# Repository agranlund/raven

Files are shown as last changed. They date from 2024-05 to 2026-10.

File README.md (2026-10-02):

# Raven
### A homemade Atari clone computer based on Motorola 68060
This computer is primarily designed to be an Atari clone computer with
the goal of being able to natively run clean GEM/TOS applications, and backward compatibility with old ST games by help of software emulation.

Latest release package: https://github.com/agranlund/raven/releases/tag/Raven.A1.latest

Other resources:
- Youtube: https://www.youtube.com/@granlund23/videos
- Forum: https://www.exxosforum.co.uk/forum/viewforum.php?f=119

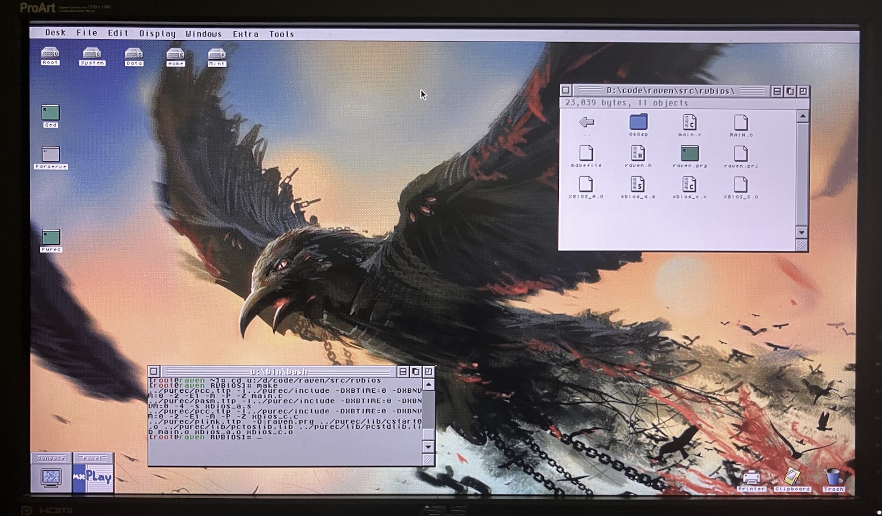
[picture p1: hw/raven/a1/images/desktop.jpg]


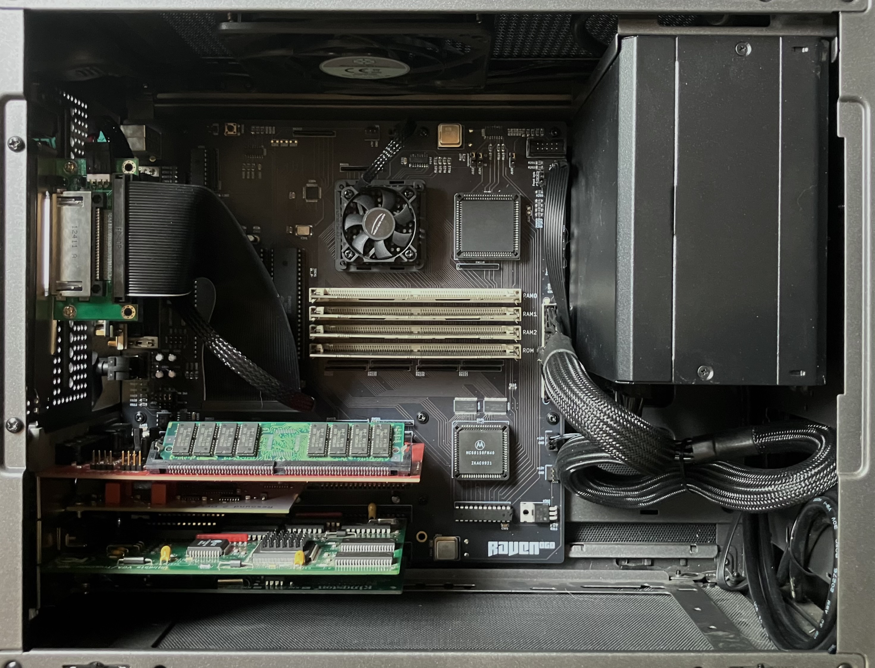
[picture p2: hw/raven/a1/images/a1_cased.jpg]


## This is not a consumer product.
I have no formal EE training or education and learn as I go.

This computer is primarily designed as a one-off for myself. For fun and learning and as a platform for low-level tinkering. 

All hardware and software sources are provided as-is and for free but comes with no guarantees or promise of support.

The computer works for me and runs EmuTOS, FreeMiNT and MagiC but if you decide to build or buy this board I very much recommend coming in with a DIY mindset.
Knowledge and tools to perform hardware-level debugging and/or very low level software debugging is highly recommended.

## Specifications Rev.A2
- Motorola 68060 CPU @ 96Mhz
- Motorola 56303 DSP @ 90Mhz
- Max 48MB RAM
- Max 16MB ROM
- USB Mouse & Keyboard
- 1Mbps serial port
- Legacy Atari serial port
- Legacy Atari parallel port
- Legacy Atari joystick ports
- IDE Harddisk interface
- Realtime clock
- Midi In/Out
- YM2149 sound
- MC68901 mfp
- ISA 16bit expansion slots x4

## Manual
- [Revision.A1](doc/manual_a1.pdf)

## Required or recommended parts
- Raven motherboard
	- [Revision.A2](hw/raven/a2/)
    - [Revision.A1](hw/raven/a1/)
    	- [USB upgrade](hw/raven/a1/upgrades/ckbd/)
    - ~~[Revision.A0](hw/raven/a0/)~~
- RAM modules
    - [16MB 55ns](hw/simm/ram_16M55/)
    - ~~[8MB 10ns](hw/simm/ram_8M10/)~~
- ROM module
    - [55ns SMD](hw/simm/rom_SMD/)
    - [55ns PLCC](hw/simm/rom_PLCC/)
- ATX power supply
- USB keyboard and mouse (PS/2 for Rev.A1 without USB upgrade)
- Some kind of suitable 44pin IDE->CF adapter
- RS232<->USB cable capable of 1Mbps
- ISA graphics card.
    - SVGA with hardware acceleration
        - Cirrus GD5434, GD5429, GD5428, GD5426
        - WDC WD90C33, WD90C31
        - Tseng ET4000/W32i
        - ATI Mach32
    - SVGA without hardware acceleration
        - Tseng ET4000AX
        - (untested) Cirrus GD5424, GD5422
        - (untested) WD90C30
    - Cards not listed above may work but only in standard VGA resolutions.
- ISA Network card.
	- RTL8019AS based card
- ISA soundcard
	- SoundBlaster compatible
	- Gravis Ultrasound

## Additional tools
- [ROM module programmer](hw/simm/programmer/)
- Programmer for ATF1508AS, for example ATDH1150-USB
- Programmer for ATF22V10C, for example XGecu TL866II-Plus
- (Rev.A1) Programmer for PIC16F876A, for example XGecu TL866II-Plus

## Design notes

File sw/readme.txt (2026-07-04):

## Subtrees:
sw/rom/emutos           : https://github.com/emutos/emutos master
sw/isa/drivers/picogus  : https://github.com/polpo/picogus main
sw/dsp/asm56k           : https://github.com/agranlund/asm56k master

## Compilers:
rom/mon                     : m68k-atari-mintelf-gcc
rom/srec                    : m68k-atari-mintelf-gcc
rom/emutos                  : m68k-atari-mintelf-gcc

rvbios                      : pureC
rvnova                      : pureC
rvsnd                       : pureC
tools/cache                 : pureC
tools/eiffel                : pureC
tools/flash                 : pureC
tools/fpu_emu               : m68k-atari-mintelf-gcc
tools/fpu_off               : pureC
tools/mon                   : pureC
tools/patch_xc              : pureC
tools/raven.cpx             : pureC
tools/resetnvm              : pureC
tools/serial.cpx            : pureC
tools/thingpal              : pureC
tools/uiptools              : m68k-atari-mintelf-gcc

isa/isa_bios                : pureC
isa/drivers/fmradio         : pureC
isa/drivers/gus             : pureC
isa/drivers/mpu401          : pureC
isa/drivers/oplmidi         : pureC
isa/drivers/ne2000/ethernec : turboC (1)
isa/drivers/picogus         : m68k-atari-mintelf-gcc

(1) using existing binaries, not compiling from source.
    to be replaced by own driver at some point.

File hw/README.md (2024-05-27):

All pcbs are made within JLCPCB tolerances and any Gerbers found here are exported for JLCPCB specifications.

Disclaimer: I am not an electrical engineer.
If anything in here seems stupidly designed, then it probably is.

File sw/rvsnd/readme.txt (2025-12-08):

# rvsnd
Sound HAL for Atari compatibles

Very early work in progress but can currently be used to initialize
cards, as well as control their mixers.
Midi in/out drivers are supported too.

Install:
- put rvsnd.prg in c:\auto
- put rvsnd.inf in root of c:\
- rvsnd.inf contains settings which can be edited with a text editor of choice

Remove the old standalone drivers from your auto folder if you have them:
- mpu401.prg
- oplmidi.prg
- ultrinit.prg

You can use rvsctrl.prg on the commandline to view and change settings.
(They are not saved. for that you need to manually edit rvsnd.inf)

The gsxbmixer application should work with rvsnd:
https://assemsoft.atari.org/gsxb/index.html

todo: proper documentation...

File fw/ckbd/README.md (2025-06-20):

# CKBD
## Eiffel replacement for Raven
## This is a work in progress and may contain yet to be discovered incompatibilities

CKBD aims to be fairly compatible with Eiffel and allows the use of the following devices:
* USB Keyboard and mouse
* PS2 Keyboard and mouse
* Atari joystick(s)
* Atari mouse
* Amiga mouse

Raven.A2 has the necessary hardware already on the motherboard.

Older revisions can use an [upgrade board](../../hw/raven/upgrades/ckbd/) that plugs into the Eiffel port.
Two USB ports are then exposed on an internal header.

## Technical description

CKBD is based around the CH559 microcontroller from WCH.

Some parts of this sourcecode is based on HIDman by Rasteri (https://github.com/rasteri/HIDman)

which is turn was based on CH559sdccUSBHost by atc114 (https://github.com/atc1441/CH559sdccUSBHost)

# First time programming: Windows
- Install WCHISPTool tool: https://www.wch.cn/downloads/WCHISPTool_Setup_exe.html
- Connect CKBD to your computer using a USB cable connected to the USB0 port.
- Select "File -> Load UI Config" and pick "ckbd_wch.ini"
- Under the "Download File" section pick "ckbd_a1.bin" as Object File 1
- Press Download to program the firmware

# First time programming: MacOS/Linux
There are several tools for flashing CH559, including an official one from WCH.
I am using ch552tool from MarsTechHAN (https://github.com/MarsTechHAN/ch552tool)

Flashing with ch552tool:
- install ch552tool, libusb and pyusb
- Connect CKBD to your computer using a USB cable connected to the USB0 port.
- run "python3 ch55xtool.py -f ckbd_a1.bin -r"

Flashing with WCHISPTool_Cmd:
- Install WCHISPTool_Cmd
- Read the documentation (especially if you are on MacOS)
- Connect CKBD to your computer using a USB cable connected to the USB0 port.
- run "WCHISPTool_CMD -p \<deviceid\> -c ckbd_wch.ini -o program -f ckbd_a1.bin"
  (you did read the manual regarding finding your \<deviceid\>, right?)

## Firmware update
With the CBKD installed in Raven:
   - press the NMI button to enter the monitor
   - run "kbd flash"
   - send the ckbd firmware binary with your serial terminal
   - run "reset" to reset Raven

If the ckbd is bricked and won't respond to updating firmware the normal way then:
  - make sure Raven is powered off
  - disconnect all usb devices
  - jumper the two middle pins of CKBD header J104
  - power on Raven
  - perform the same steps as when you did the first time programming
  - power off Raven
  - remove jumper from J104 and your USB programming cable
  - reconnect your devices and power on Raven

# Compiling
Compiles with SDCC: https://sdcc.sourceforge.net/

If you are building and working on the firmware yourself you can use "make target=a1 flash" or "make target=a1 flash_wchispcmd" to flash using the bundled ch552tool or wchisptool.
When using wchisptool you'll need to modify the WCHISPDEV variable in the makefile.

Executing "kbd prog" from the Raven monitor will put the CH559 into bootloader mode so it can be programmed with these tools (ie; you don't need to jumper it to start in bootloader mode)

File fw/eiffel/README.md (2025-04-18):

Compiles with GPASM from GPUTILS: https://gputils.sourceforge.io/

## Eiffel firmware v1.10.2-raven_A1

Firmware for Raven rev.A1 boards, based on v1.10.1-Mq_fixedFire_noLcd

The version ending with _ansi defaults to US-ANSI keyboard layout, however the layout can be changed at any time using the Eiffelcf application.

## Eiffel firmware v1.10.1-Mq_fixedFire_noLcd

This is a modified firmware with joystick fix and disabled LCD.
See this thread for details:

http://www.atari.org.pl/forum/viewtopic.php?id=19470

Original Eiffel schematics, firmware and control software:

http://didier.mequignon.free.fr/eiffel-e.htm

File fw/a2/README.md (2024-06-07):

- Nessi
    - ATF1508AS  7ns : main bus logic
- Narnia
    - ATF22V10C 10ns : isa control signals
- Iksi
    - ATF22V10C 10ns : ym/mfp/ide control signals

Builds with WinCUPL Atmel version 5.30.4
https://www.microchip.com/en-us/products/fpgas-and-plds/spld-cplds/pld-design-resources

I am using the newer ATF1508 fitter v1918 extracted from the Atmel Prochip package.
It's probably going to work fine with the old version bundled with WinCUPL but I have not tested it.

ATF1508AS can be programmed in-place using ATMISP software and ATDH1150USB programming cable.
Both of the ATF22V10C chips needs to be programmed off-board in an external programmer.

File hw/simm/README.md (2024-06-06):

# Info:
- Simm modules should be manufactured with a thickness of 1.2 mm
- They are probably be a tiny bit too wide but do fit in the socket ok. Would be good to shave off a millimeter or so in a future update.
- Unless stated otherwise these hardware designs are licensed under CERN-OHL-P v2
    - See LICENSE.md or visit https://cern.ch/cern-ohl

### Sub projects:
- breakout
	- simple simm breakout module for debugging. untested.
- panel
	- template for merging two simms onto one board separated by mouse-bites
- programmer
	- Pico based programmer for ROM simm modules
- ram_16M55
	- 16MB 55ns RAM module
- ram_8M10
	- 8MB 10ns RAM module
- rom_16M55
	- module with SMD roms (recommended)
- rom_2M55
	- module for 4x socketed PLCC roms
- template
	- blank simm module template

### Pinout:

1. vcc     * 
2. a2
3. a3
4. a4
5. a5
6. a6
7. a7
8. a8
9. a9
10. gnd     *
11. d31
12. d30
13. d29
14. d28
15. d27
16. d26
17. d25
18. d24
19. gnd     *
20. d23
21. d22
22. d21
23. d20
24. d19
25. d18
26. d17
27. d16
28. gnd     *
29. d15
30. d14
31. d13
32. d12
33. d11
34. d10
35. d9
36. d8
37. gnd     *
38. d7
39. d6
40. d5
41. d4
42. d3
43. d2
44. d1
45. d0
46. gnd     *
47. a21
48. a20
49. a19
50. a18
51. a17
52. a16
53. gnd     *
54. a15
55. a14
56. a13
57. a12
58. a11
59. a10
60. a9
61. a8
62. gnd     *
63. b0
64. b1
65. b2
66. b3
67. nc      -
68. oe
69. we
70. nc      -
71. nc      -
72. vcc     *

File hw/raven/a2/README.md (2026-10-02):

# Raven060 Rev.A2

(c)2025-2026 Anders Granlund

This source describes Open Hardware and is licensed under the CERN-OHLW v2.

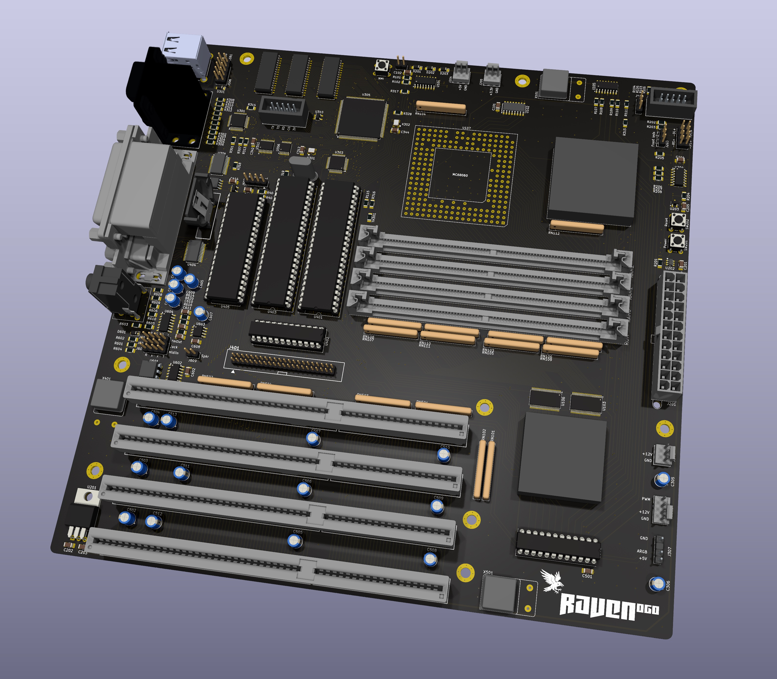
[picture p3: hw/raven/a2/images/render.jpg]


## Status:
- Built and running. Individual new features being tested.

## Info:
- Designed for JLCPCB standard six layer stackup (JLC06161H-3313)
- [Complete BOM](production/raven-a2_bom.md)
- [Interactive BOM](https://htmlpreview.github.io/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)
- [Interactive PCB](https://kicanvas.org/?repo=https%3A%2F%2Fgithub.com%2Fagranlund%2Fraven%2Ftree%2Fmain%2Fhw%2Fraven%2Fa2)

The following changes has been made to the files here on Github since after my personal board was manufactured.
- PWR_SW to UART:RI connection removed
- DC blocking capacitors to ADC left/right inputs added

## Changelog from Rev.A1
- Silkscreen: Fixed wrong pinout info for J305
- Silkscreen: Reversed order of RAM simms
- Silkscreen: Clearer orientation for a bunch of headers
- Silkscreen: Clearer pin1 markers for a bunch of SMD footprints
- Footprint:  Larger footprints for handsolder D201, D202, D203
- BOM: Replaced PLCC64 socket for U104 with black part
- BOM: Replaced PLCC84 socket for U108 with black part
- BOM: Replaced buttons SW101,SW201,SW202 with black parts
- BOM: Replaced jumpers with standard closed-top ones
- BOM: Replaced J401 IDE header
- Fixed: RTC power delivery, now using ATX standby power
- Fixed: unused but floating inputs on U102
- Fixed: polarity of YM2149 DC blocking caps
- Changed: through-hole DS1818 with DS1818R (SMD version)
- Changed: IDE interface is now big-endian
- Changed: CKBD instead of Eiffel
- Changed: 2xUSB instead of 2xPS2
- Changed: Replaced one 12V fan header with PWM + ARGB
- Removed: UART IRQ6 (MFP1:I4)
- Removed: CPU clock multiplier jumpers
- Added: small solderpad for securing Y402 to board
- Added: 68150:BUSCS signal separate from 68150:CS
- Added: A6 signal instead of A5 to ATF1508 (for BERR on SFP004 access)
- Added: pullups on 68150 data bus
- Added: pulldown on IDE:IRQ
- Added: i2c eprom with preprogrammed MAC address
- Added: i2c expansion header
- Added: CPU temperature readout from CKBD
- Added: PowerOff control from CKBD
- Added: YM2149 sw controlled volume
- Added: internal speaker amp + header
- Added: DSP56303 with DAC+ADC and ESSI1 expansion header

## Optional / non-critical:
- todo: describe building Rev.A2 without DSP?

## Untested:
- Midi-in

## Notes and Erratas:
- Part number for ARGB header isn't perfect, might want to use a variant with slightly longer pins.

## Future:
- Remove all components from Analog Devices as they can be hard to purchase for individuals?
  - MAX3245  : ICL3245ECAZ  (drop in replacement)
  - DS1307   : MCP79411     (software changes only, also makes U407+C415 redundant)
  - DS1818R  : MIC6315      (small schematic and board change needed)
  - MAX16054 : tbd          (small schematic and board change needed)

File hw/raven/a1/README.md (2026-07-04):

# Raven060 Rev.A1

(c)2024 Anders Granlund

This source describes Open Hardware and is licensed under the CERN-OHLW v2.



## Status:
Success: All major features has been tested and works in EmuTOS and FreeMiNT.

Tested with 48mhz oscillator for 96mhz CPU, 48mhz BUS speed.

## Info:
- Designed for JLCPCB Standard Service 6 layers
- [Complete BOM](production/raven-a1_bom.md)
- [Interactive BOM](https://htmlpreview.github.io/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)
- [Interactive PCB](https://kicanvas.org/?repo=https%3A%2F%2Fgithub.com%2Fagranlund%2Fraven%2Ftree%2Fmain%2Fhw%2Fraven%2Fa1)

## Errors to consider when building:
- C601-C604 capacitor orientation is wrong. Solder reverse of what silkscreen says.
- J305 silkscreen mislabeled; Pinout is same as J206 above.

## Changelog from Rev.A0:
- Changed locations of H607, H609
- Changed IDE ADR: A1:A3 -> A2:A4
- Changed I2C DTA: MFP1_I7 -> MFP1_I3
- Changed I2C CLK: MFP1_I3 -> MFP1_I7
- Added UART IRQ6 (MFP1:I4)
- Added Eiffel thermistor
- Added 3.3V fan header
- Added 5V fan header
- Added 12V fan header
- Added 12V fan header (Eiffel controlled)
- Added CPU speed switch J102, J104
- Added CPLD spare input switch J105
- Added CPLD spare output header J106
- Added CPLD input ISA:IOCS16
- Added expansion header J402 (4xYM outputs, 5V, gnd, i2c)
- Added pullup on CPU RW
- Added pullup on 68150 RW
- Combined CPLD excs/exbusen signals
- Disabled RS232 AutoShutdownPlus
- Removed debug testpoints and solderjumpers
- Removed second audio connector
    - YM-out / Midi-in share same lower connector on J601
    - Non selected is exposed on header J602:J604
- Misc silkscreen & bom fixes

## Errata / Notes for next revision:
- Silkscreen: J305 pinout mislabeled
- Silkscreen: U203 orientation is not obvious
- Silkscreen: J204-206,J305 orientation is not obvious
- Silkscreen: J301-304 orientation is not obvious
- Silkscreen: J103, J401 orientation is not obvious
- Footprints: D201-203 pads are small and hard to solder by hand
- Footprints: C601-603 hole spacing slightly too wide
- Footprints: C502-513 hole spacing slightly too wide
- Footprints: Y402 add a way to secure it (SMD pad at top to solder it in place)
- BOM: PLCC socket Preci-Dip 540-88-068-24-008 is brown, find black replacement
- BOM: PLCC socket Preci-Dip 540-88-084-24-008 is brown, find black replacement
- BOM: ATX connector TE 1-1775099-3 is white, find black replacement
- BOM: Buttons are red, find black replacement
- BOM: Jumpers TE 1-881545-4 are difficult to grab, pick a different variant
- PCB: Some kind of sign-of-life LEDs
- PCB: Combining excs/exbusen was a misstake. Separate signals could allow faster synchronous termination.
- PCB: A5 signal to CPLD is unused and the pin could potentially be freed up for something else
- PCB: SFP004 detection cannot neatly be prevented in software, route A6 to CPLD for hardware berr generation.
- PCB: Add hardware debounce the NMI switch
- PCB: Add header for one of MFP2 timer-outs (for pc-speaker type applications)
- PCB: Realtime clock should use +5VSB instead of +5V to reduce battery usage

## Untested:
- Midi In

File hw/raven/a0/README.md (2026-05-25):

# Raven060 Rev.A0

(c)2024 Anders Granlund

This source describes Open Hardware and is licensed under the CERN-OHLW v2.

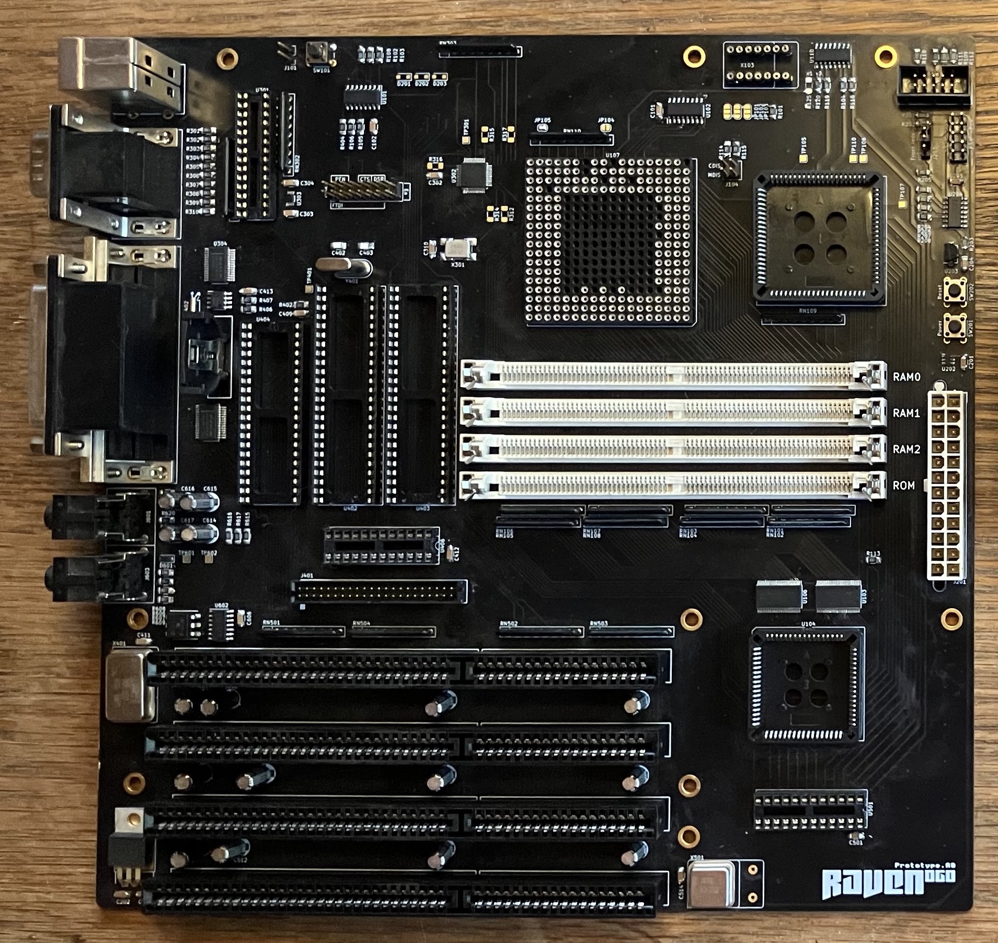
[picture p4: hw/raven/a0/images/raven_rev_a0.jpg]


## Status:
Success: All major features has been tested and works in EmuTOS and FreeMiNT.

Computer runs stable at 96mhz CPU / 48mhz BUS speed.

This is the very first "throw away" prototype and I do not recommend building it.
No efforts will be made to ensure software or firmware developments maintain compatibility with this version.

Revision.A1 should be considered the corrected version of this board.

## Info:
- Designed for JLCPCB Standard Service 6 layers
- [Interactive BOM](https://htmlpreview.github.io/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)

## Notes:

#### Untested features:
- Midi in

#### Errors:
- Layout:
	- H607 wrong location
	- H609 wrong location
    - Back connectors too close to lower edge
- Silkscreen:
	- C512 upside down
- BOM:
	- Exclude DNP parts
	- Missing the jumpers

#### Must fix:
- CPU:
	- pullup on RW
	- remove debug solder jumpers
    - remove debug option header
- 68150:
	- pullup on RW
- RS232:
	- U304 : disable AutoShutDownPlus
	- U401 : disable AutoShutDownPlus
	- remove internal FTDI header
- Eiffel:
	- IRQ6 instead of 5 (or both)
	- Hook up Therm and fan controls
- IDE:
	- use A2:4 instead of A1:3 like Atari/Amiga
- YM:
	- Add internal Line-out header
- ISA:
	- route IOCS16 to cpld

#### Nice to have:
- Fan header(s)
- Combine exbusen & excs
- CPU x1/x2 selectable by jumper
- Spare CPLD in/out on header
- pin info on back silkscreen (ym/mfp)

#### Maybe:
- PC speaker header on a spare MFP2 TBO/TCO
- Indicator leds
- Get rid of uart oscillator and derive from bus clock
- Find a spare input pin usable for bootmode select or similar
- Philosophical question, should IDE be kept little-endian like Amiga/PC or changed to big-endian like Atari
- Should the IDE header be kept as a normal male MB pinout or changed to female cable pinout to allow directly plugging in cheap CF card adapters that expects a cable connection

#### Future ideas:
- onboard ethernet
- onboard usb
- Built in amp + speaker?

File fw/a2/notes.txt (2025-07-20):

Nessi:
 pin changes:
  34: A6 replaces A5
  81: /ETH_CS replaces SPARE_J106_IN_81
  73: /65150:BUSCS replaces SPARE_J106_IO_73

 todo:
  - generated BERR on SFP004 access (fffa40-fffa5f)
  - trigger /68150:BUSCS
  - decode and trigger /ETH_CS

Iksi:

Narnia:

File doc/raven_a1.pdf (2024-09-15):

REV.A1

Raven 68060, rev.A1
(c)2024 Anders Granlund

This computer and accompanying software is open source.

Disclaimer: This computer was designed as a learning experience and for my own enjoyment.
Hardware and software sources are provided as-is and for free but with any functional guarantees or promise of support.

# Ports

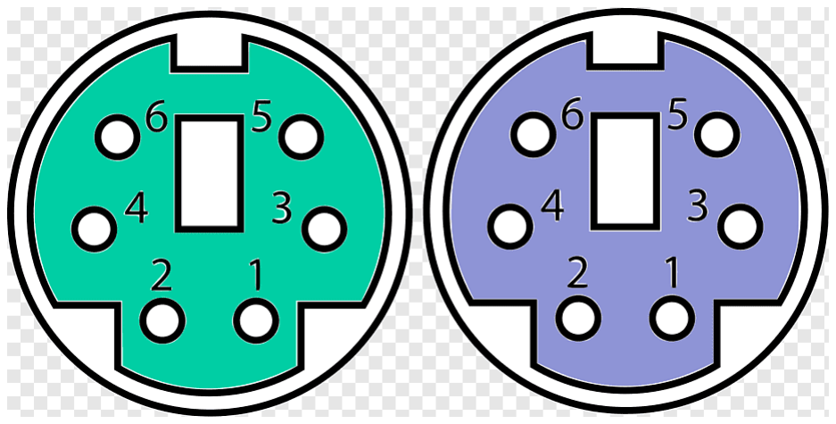
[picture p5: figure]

1 : Mouse data
3 : Mouse GND
4 : Mouse +5V
5 : Mouse clock

1 : Keyboard data
3 : Keyboard GND
4 : Keyboard +5V
5 : Keyboard clock

1 : JOY0 Up
2 : JOY0 Down
3 : JOY0 Left

4 : JOY0 Right
5 : nc
6 : JOY0 Fire

7 : JOY0 +5V
8 : JOY0 GND
9 : nc

1 : LPT1 Strobe
11 : LPT1 Busy

1 : JOY1 Up
2 : JOY1 Down
3 : JOY1 Left

4 : JOY1 Right
5 : nc
6 : JOY1 Fire

7 : JOY1 +5V
8 : JOY1 GND
9 : nc

2-9 : LPT1 Data
18-25 : LPT1 GND

1 : COM1 DCD
2 : COM1 RX
3 : COM1 TX
4 : COM1 DTR
5 : COM1 GND
6 : COM1 DSR
7 : COM1 RTS
8 : COM1 CTS
9 : COM1 RI

1 : COM2 DCD
2 : COM2 RX
3 : COM2 TX
4 : COM2 DTR
5 : COM2 GND
6 : nc
7 : COM2 RTS
8 : COM2 CTS
9 : COM2 RI

LPT1 : Atari parallel
COM1 : High speed UART
COM2 : Atari serial

# Audio ports

Upper : Midi-OUT
Lower : Midi-IN / YM-OUT

The function of the lower port is selected using jumpers J602:J604 on the motherboard. Non-selected function can be still be used through the exposed header.

YM-OUT is outputted in stereo with channel A=left, B=both, C=right
TRS-Tip | : Left
TRS-Ring | : Right
TRS-Sleeve : GND

Midi-OUT is outputted on the TRS connector as Midi Standard Type-A
TRS-Tip | : MIDI5 (Sink)
TRS-Ring | : MIDI4 (Source)
TRS-Sleeve : MIDI2 (Shield)

Midi-IN in inputted from the TRS connector as Midi Standard Type-A
TRS-Tip | : MIDI5 (Sink)
TRS-Ring | : MIDI4 (Source)
TRS-Sleeve : nc

# Motherboard connectors and jumpers

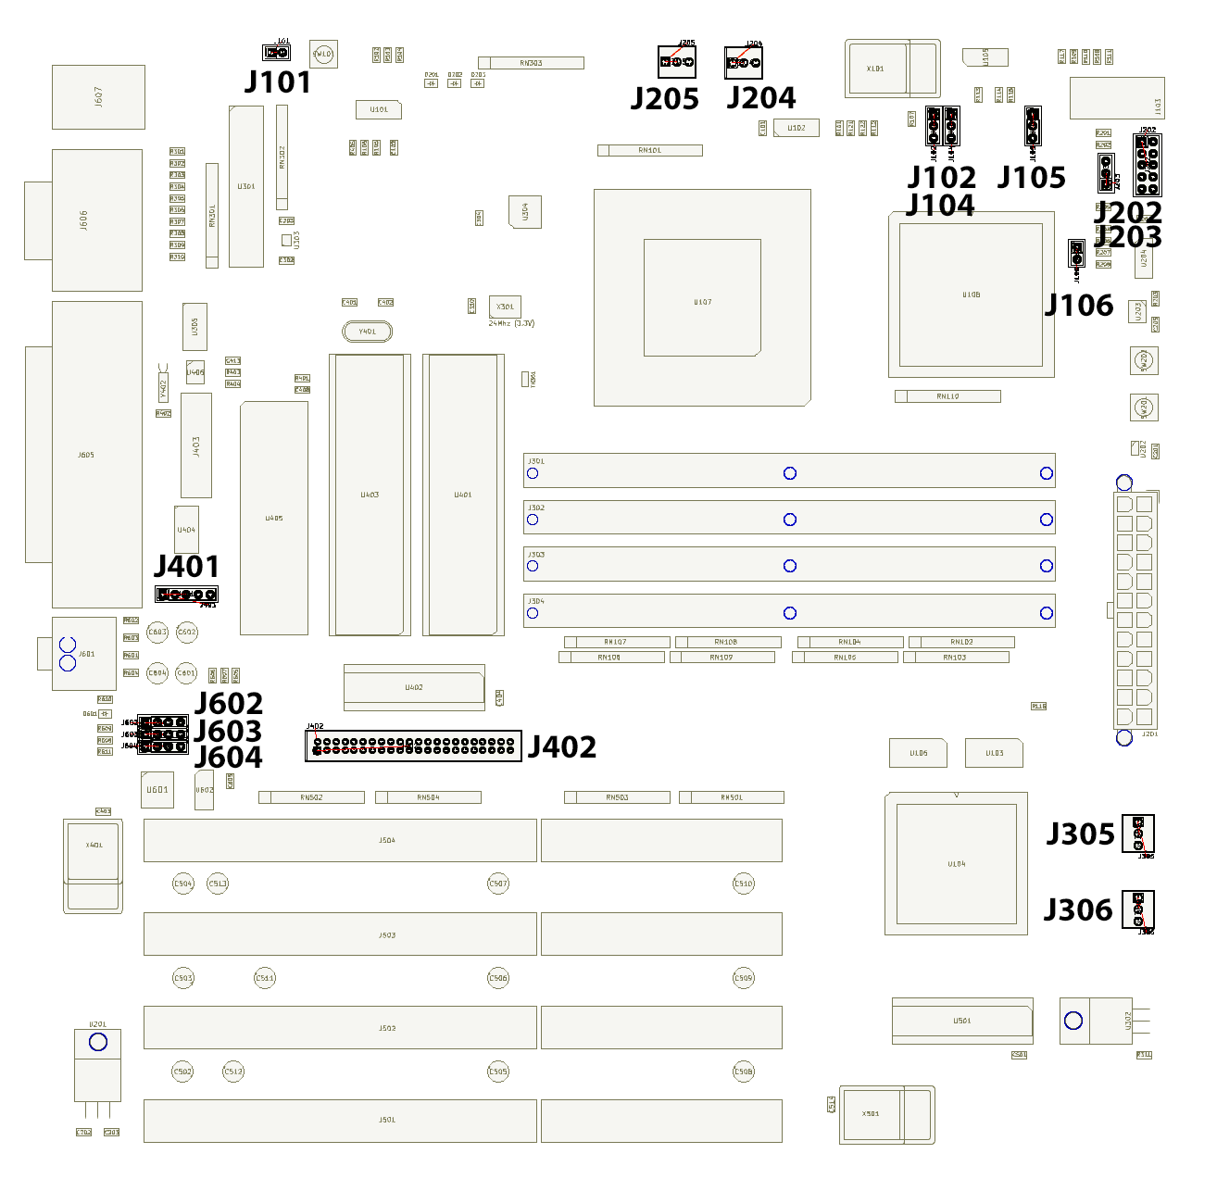
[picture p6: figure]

J101 | : NMI trigger
J102,J104 | : CPU x1/x2 multiplier selector
J105 | : RAM speed selector (not yet implemented)
J106 | : Reserved
J202 | : Front panel connector
J203 | : Front panel configuration
J204 | : Always on fan +3.3V
J205 | : Always on fan +5V
J305 | : Always on fan +12V
J306 | : Eiffel controlled fan +12V [On:40°C, Off:30°C] | (Silkscreen pinout is mislabeled)
J401 | : I2C/GPO expansion connector
J402 | : 44pin IDE interface
J602,J603,J604 : Lower TRS port feature select.
Connect all pins of either J602 or J604 to the middle J603 using 4 jumpers. The unused feature can still be used through the unconnected header. J602=YM-Out, J604=Midi-In

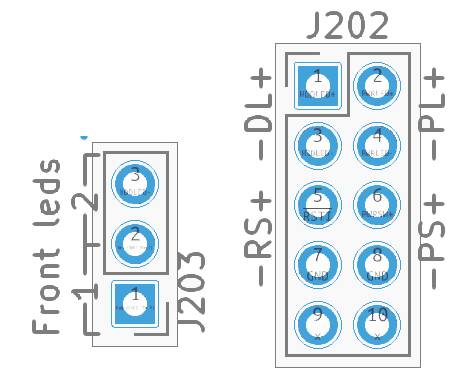
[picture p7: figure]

| J203 : LED configuration.
| 1 = Shared Disk and Power LED
| 2 = Separate Disk and Power LEDs | J202 : Frontpanel connector
| | 1 : DL+ : Disk LED+
| | 2 : PL+ : Power LED+
| | 3 : DL- : Disk LED-
| | 4 : PL- : Power LED-
| | 5 : RS+ : Reset switch+
| | 6 : PS+ : Power switch+
| | 7 : RS- : Reset switch-
| | 8 : RS+ : Power switch-
| | 9 : nc
| | 10 : nc

# IDE Interface

1 : /Reset
3 : D31
5 : D30
7 : D29
9 : D28
11 : D27
13 : D26
15 : D25
17 : D24
19 : GND
21 : DMARQ (nc)
23 : /IOW
25 : /IOR
27 : /RDY
29 : /DMACK (+5v)
31 : IRQ
33 : A3
35 : A2
37 : /CS0
39 : /DASP (led)
41 : +5V
43 : GND

2 : GND
4 : D16
6 : D17
8 : D18
10 : D19
12 : D20
14 : D21
16 : D22
18 : D23
20 : KEY | (nc)
22 : GND
24 : GND
26 : GND
28 : CSEL (gnd)
30 : GND
32 : /IOCS16 (nc)
34 : /PDIAG (nc)
36 : A4
38 : /CS1
40 : GND
42 : +5V
44 : GND

The IDE interface is byte swapped little endian like Amiga and PC, but unlike Atari which is normally big endian.

Register access using A2-A4 same as Amiga and Atari

Connector is IDC male with an orientation that assumes the male-pin drive is connected with a cable or suitable adapter.

# SIMM modules

RAM must be populated from first to last slots. Eg; if you only have one Simm, then it must go in the first (RAM0) slot. ROM must be place in the fourth (ROM) slot.

This may change in the future.
Eg; a combo ROM+RAM Simm module could be made possible with only software / cpld changes.

All Simms modules regardless of type share the exact same pinout:

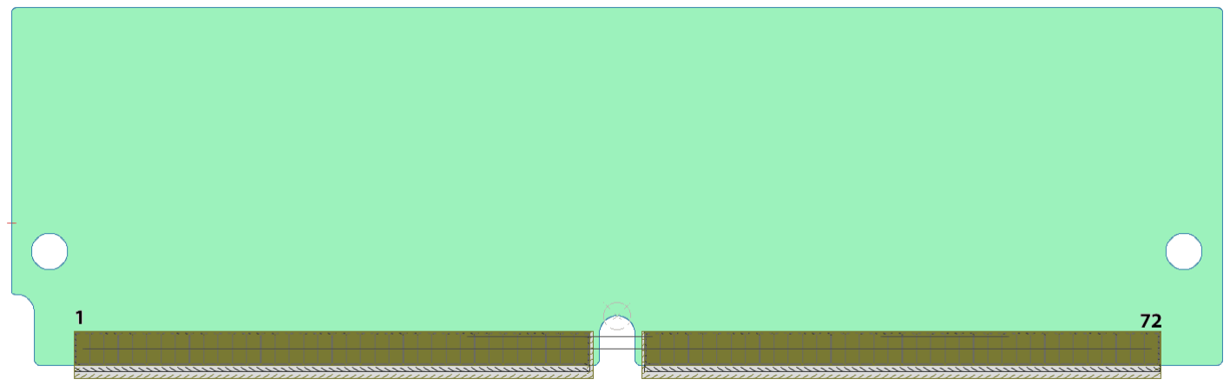
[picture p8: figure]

1 | : +3.3V
2-9 | : A0-A7
10 | : GND
11-18 : D31-D24
19 : GND
20-27 : D23-D16
28 : GND
29-36 : D15-D8
37 : GND
38-45 : D7-D0
46 : GND

47-52 : A21-A16
53 : GND
54-61 : A15-A8
62 : GND
63-66 : BS0-BS3
67 | : nc
68 | : /OE
69 | : /WE
70 | : nc
71 | : nc
72 | : +3.3V | Todo: 10ns vs 55ns RAM

# Expansion slots

todo: ISA interrupts

todo: ISA DMA

todo: LELS wiring

# Physical memory map

Raven CPLD can only decodes address bits 31,30,29,25,24,10,9,5 and relies on PMMU to provide an Atari compatible logical memory map.

$00000000 - $00FFFFFF : SIMM0
$01000000 - $01FFFFFF : SIMM1 $02000000 - $02FFFFFF : SIMM2 $40000000 - $40FFFFFF : SIMM3

$20000000 - $20FFFFFF : UART $A0000000 - $A00001FF : IDE $A0000200 - $A00003FF : MFP2 $A1000800 - $A10009FF : YM
$A1000A00 - $A1000BFF : MFP1 $A1000C00 - $A1000DFF : ACIA emulation

$80000000 - $80FFFFFF : ISA RAM $81000000 - $810FFFFF : ISA IO $82000000 - $82FFFFFF : ISA RAM16 (*)
$83000000 - $830FFFFF : ISA IO16 (*)

(*) Subject to changes, $82x/$83x map may be removed in the future.

# Logical memory map

$00000000 - $00xxxxxx : ST-RAM (1-4MB)
ST-RAM is followed by 1MB bus error

$00500000 - $0050FFFF : bios unused $00510000 - $0051FFFF : bios acia emu $00520000 - $0057FFFF : bios stack $00580000 - $005EFFFF : bios bss
$00600000 - $007FFFFF : bios reserved

$00E00000 - $00EFFFFF : TOS

$00F00000 - $00FFFFFF : Atari hardware registers

$01000000 - $03FFFFFF : TT-RAM (48MB) $04000000 - $040FFFFF : bus error

$41000000 - $41FFFFFF : ST-Emulation

$FF000000 - $FFFFFFFF : 24bit mirror

// todo: ISA bus

# Hardware Interrupts

Autovector interrupts

VBR+$64 : IRQ1 : —
VBR+$68 : IRQ2 : —
VBR+$6C : IRQ3 : —
VBR+$70 : IRQ4 : —
VBR+$74 : IRQ5 : UART
VBR+$78 : IRQ6 : MFP1+MFP2 VBR+$7C : IRQ7 : NMI

Vectored interrupts

VBR+$100 : MFP1 : LPT1 Busy VBR+$104 : MFP1 : COM2 CarrierDetect VBR+$108 : MFP1 : COM2 ClearToSend VBR+$10C : MFP1 : <masked> VBR+$110 : MFP1 : TimerD
VBR+$114 : MFP1 : TimerC
VBR+$118 : MFP1 : UART
VBR+$11C : MFP1 : HDD
VBR+$120 : MFP1 : TimerB
VBR+$124 : MFP1 : COM2 TxError VBR+$128 : MFP1 : COM2 TxBufferEmpty VBR+$12C : MFP1 : COM2 RxError VBR+$130 : MFP1 : COM2 RxBufferFull VBR+$134 : MFP1 : TimerA
VBR+$138 : MFP1 : COM2 Ring VBR+$13C : MFP1 : <masked>

VBR+$140 : MFP2 : ISA 2/9
VBR+$144 : MFP2 : ISA 3
VBR+$148 : MFP2 : ISA 4
VBR+$14C : MFP2 : ISA 5
VBR+$150 : MFP2 : TimerD
VBR+$154 : MFP2 : TimerC
VBR+$158 : MFP2 : ISA 7
VBR+$15C : MFP2 : ISA 10
VBR+$160 : MFP2 : TimerB
VBR+$164 : MFP2 : Midi TxError VBR+$168 : MFP2 : Midi TxBufferEmpty VBR+$16C : MFP2 : Midi RxError VBR+$170 : MFP2 : Midi RxBufferFull VBR+$174 : MFP2 : TimerA
VBR+$178 : MFP2 : ISA 11
VBR+$17C : MFP2 : ISA 14

# Logical Interrupts

Raven Bios moves the VBR to get first dibs on all interrupts.
It normally jumps directly to the equivalent vector at base $0 but it can use this feature to hide or emulate interrupts for compatibility.
This works because all, or most, Atari software assumes vectors start at $0 without checking VBR.

$70 : IRQ4 : VBL emulation (from MFP2:TimerB)
$7C : IRQ7 : intercepted and will never trigger (used by bios)
$10C : MFP1 : intercepted and will never trigger (used for i2c)
$118 : MFP1 : ACIA emulation
$13C : MFP1 : intercepted and will never trigger (used for i2c)

# Debug monitor

Enter debug monitor by pressing NMI button SW101 or closing jumper J101.
The default monitor connection is COM1, 750000 baud, 8 data bits, no parity, 1 stop bit with CTS/RTS flow control.

Commands:

# Todo:

- ATF1508AS / ATV22V10C / Eiffel programming
- Hard disk setup
- NOVA driver
- ISA_BIOS
- ISA programming example
- Ethernet driver
- GUS driver
- I2C information and programming
- J402 Expansion header
- J105 RAM speed select

# Resources

Raven: | https://github.com/agranlund/raven
ST Emulator: | https://github.com/agranlund/castaway
Eiffel: | http://didier.mequignon.free.fr/eiffel-e.htm
NOVA: | https://silicon-heaven.org/atari/nova

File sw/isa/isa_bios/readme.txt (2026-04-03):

ISA plug and play bios for Atari compatibles

Main development platform is Raven but it has built-in support
for other ISA enabled Atari platforms too.

- Raven
  Main developement platform.
  IRQ is supported.
  DMA not supported by the hardware.

- Hades
  (limited support. IRQ support not implemented)

- Milan
  (limited support. IRQ support not implemented)

- Panther/2
  (limited support. IRQ support not implemented)

- Others
  Limited support for other platforms can be added by
  specifying the bus configuration in isa_bios.inf

Portions of this software is based on code from FreeBSD.

----------------------------------------------------------------------------
SPDX-License-Identifier: BSD-2-Clause-FreeBSD

Copyright (c) 1996, Sujal M. Patel
Copyright (c) 2025, Anders Granlund
All rights reserved.

Redistribution and use in source and binary forms, with or without
modification, are permitted provided that the following conditions are met:
1. Redistributions of source code must retain the above copyright
   notice, this list of conditions and the following disclaimer.
2. Redistributions in binary form must reproduce the above copyright
   notice, this list of conditions and the following disclaimer in the
   documentation and/or other materials provided with the distribution.

 THIS SOFTWARE IS PROVIDED BY THE AUTHOR AND CONTRIBUTORS ``AS IS'' AND
 ANY EXPRESS OR IMPLIED WARRANTIES, INCLUDING, BUT NOT LIMITED TO, THE
 IMPLIED WARRANTIES OF MERCHANTABILITY AND FITNESS FOR A PARTICULAR PURPOSE
 ARE DISCLAIMED.  IN NO EVENT SHALL THE AUTHOR OR CONTRIBUTORS BE LIABLE
 FOR ANY DIRECT, INDIRECT, INCIDENTAL, SPECIAL, EXEMPLARY, OR CONSEQUENTIAL
 DAMAGES (INCLUDING, BUT NOT LIMITED TO, PROCUREMENT OF SUBSTITUTE GOODS
 OR SERVICES; LOSS OF USE, DATA, OR PROFITS; OR BUSINESS INTERRUPTION)
 HOWEVER CAUSED AND ON ANY THEORY OF LIABILITY, WHETHER IN CONTRACT, STRICT
 LIABILITY, OR TORT (INCLUDING NEGLIGENCE OR OTHERWISE) ARISING IN ANY WAY
 OUT OF THE USE OF THIS SOFTWARE, EVEN IF ADVISED OF THE POSSIBILITY OF
 SUCH DAMAGE.
----------------------------------------------------------------------------

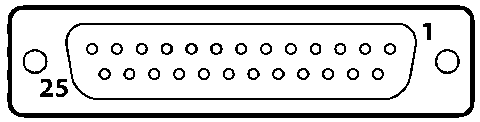
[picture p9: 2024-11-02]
doc/img/lpt.gif

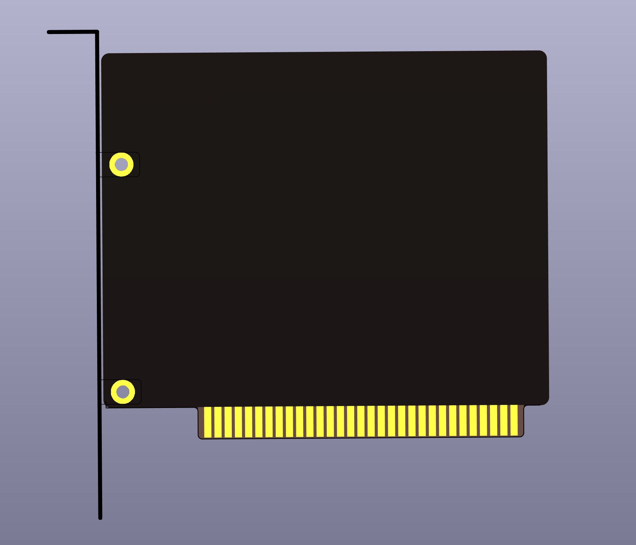
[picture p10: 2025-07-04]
hw/isa/template_8bit/images/render.png

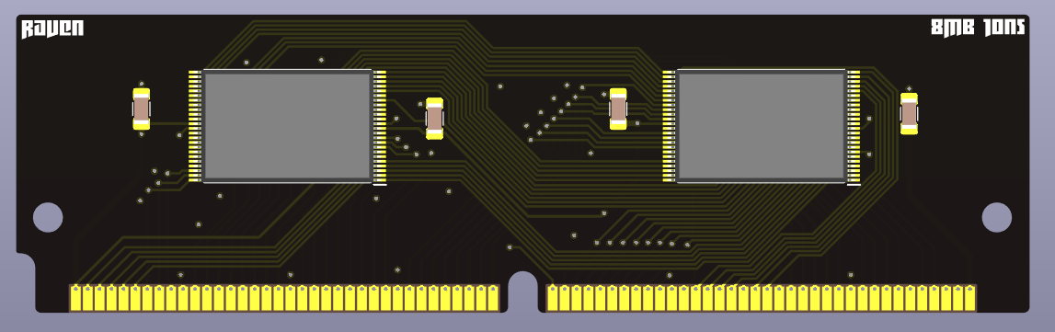
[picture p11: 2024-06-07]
hw/simm/ram_8M10/images/render.png

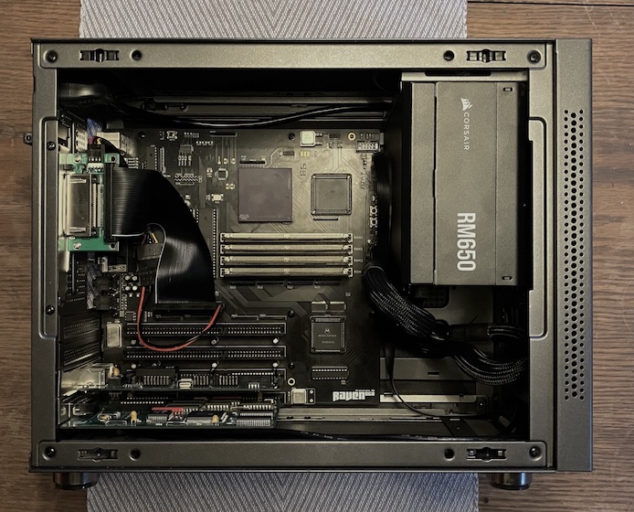
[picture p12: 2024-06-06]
hw/raven/a0/images/raven_a0_cased2.jpg

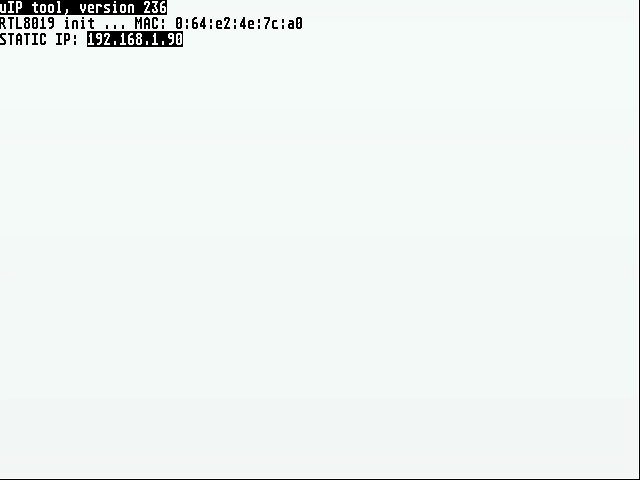
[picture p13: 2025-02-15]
sw/tools/uiptools/docs/static_ip_screen.png

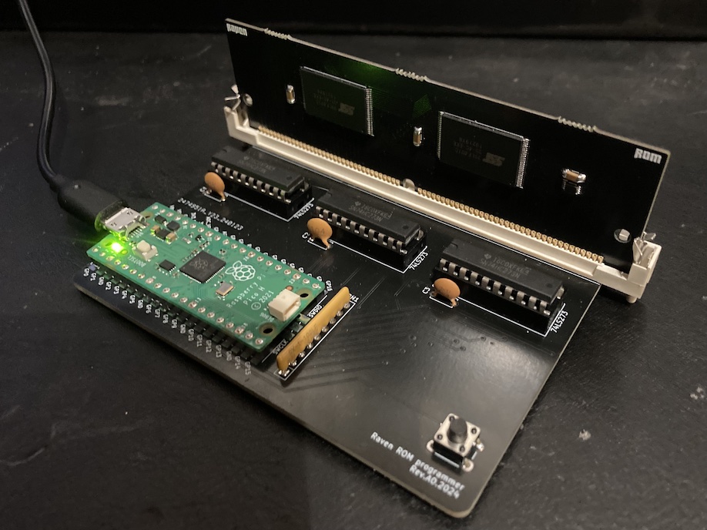
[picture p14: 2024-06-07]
hw/simm/programmer/images/programmer.jpg

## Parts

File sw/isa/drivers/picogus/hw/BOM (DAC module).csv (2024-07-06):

Mfr. # | Manufacturer | Qty | Mouser # | Digi-Key # | LCSC # | Customer # | Footprint | Description | Notes
CL31A476MPHNNNE | Samsung Electro-Mechanics | 2 | 187-CL31A476MPHNNNE | 1276-3063-1-ND | C96123 | C1,C2 | 0805 | 47 µF ±20% 10V Ceramic Capacitor X5R 1206 (3216 Metric) | Subst any 47uF electrolytic cap w/ 2mm lead spacing
CL21B105KBFNNNE | Samsung Electro-Mechanics | 1 | 187-CL21B105KBFNNNE | 1276-1029-1-ND | C28323 | C10 | 0805 | 1 µF ±10% 50V Ceramic Capacitor X7R 0805 (2012 Metric) | Subst any X7R 1uF 0805 ceramic cap
CL21B104KCFNNNE | Samsung Electro-Mechanics | 8 | 187-CL21B104KCFNNNE | 399-C0805C104M5RAC7800CT-ND | C28233 | C3,C4,C5,C6,C7,C8,C9,C11 | 0805 | 0.1 µF ±10% 100V Ceramic Capacitor X7R 0805 (2012 Metric) | Subst any X7R 0.1uF 0805 ceramic cap
B5819W-TP | Micro Commercial Components | 1 | 833-B5819W-TP | B5819W-TPMSCT-ND | C8598 | D1 | SOD-123 | 40V 600mV@1A 1A SOD-123 Schottky Barrier Diodes (SBD) | Subst any 1A 20V Schottky SOD123 diode
M20-9771246 | Harwin | 1 | 855-M20-9771246 | M20-9771246-ND | C2840012 | I2S_DAC1,J4,J7 |  | Headers & Wire Housings 12 SIL VERTICAL PIN HEADER TIN | Cut into 6, 4, 2 pin sections
10129381-918001BLF | FCI / Amphenol | 1 | 649-1012938191801BLF | 609-10129381-918001BLF-ND | C2935925 | J1 | PinHeader_2x09_P2.54mm_Vertical | Headers & Wire Housings HEADER DR VT TH 2X9-10129381-918001BLF | Subst any 2x9 2.54mm pin header
SJ1-3535NG | CUI Devices | 1 | 490-SJ1-3535NG | CP1-3535NG-ND | C5372857 | J5 | Jack_3.5mm_CUI_SJ1-3535NG_Horizontal | 3.50mm (0.141", 1/8", Mini Plug) - Headphone Phone Jack Stereo (3 Conductor, TRS) Connector Solder | Black jack for MIDI - Yellow jacks on AliExpress, search PJ-325
PH1-02-UA | Adam Tech | 1 | 649-54102-T0800LF | 2057-PH1-02-UA-ND | C2883961 | J7 | PinHeader_1x02_P2.54mm_Vertical | Connector Header Through Hole 2 position 0.100" (2.54mm)
SJ1-3535NG-GR | CUI Devices | 1 | 490-SJ1-3535NG-GR | SJ1-3535NG-GR | C692438 | J8 | Jack_3.5mm_CUI_SJ1-3535NG_Horizontal | 3.50mm (0.141", 1/8", Mini Plug) - Headphone Phone Jack Stereo (3 Conductor, TRS) Connector Solder, green | Green jack for line out
BLM21AG102SN1D | Murata Electronics | 2 | 81-BLM21AG102SN1 | 490-1041-1-ND | C85835 | FB1,FB2 | 0805 | 1 kOhms @ 100 MHz 1 Ferrite Bead 0805 (2012 Metric) 600mA 280mOhm | Subst any 1kOhm @ 100Mhz 0805 ferrite bead
CR0805-JW-102ELF | Bourns | 1 | 652-CR0805JW-102ELF | CR0805-JW-102ELFCT-ND | C17513 | R1 | 0805 | 1 kOhms ±5% 0.125W, 1/8W Chip Resistor 0805 (2012 Metric) Moisture Resistant Thick Film | Subst any 1kOhm 0.125w 0805 resistor
CR0805-JW-153ELF | Bourns | 3 | 652-CR0805JW-153ELF | 118-CR0805-JW-153ELFCT-ND | C17475 | R2,R5,R6 | 0805 | 15 kOhms ±5% 0.125W, 1/8W Chip Resistor 0805 (2012 Metric) Moisture Resistant Thick Film | Subst any 15kOhm 0.125w 0805 resistor
RK73B2ATTD221J | KOA Speer | 2 | 660-RK73B2ATTD221J | 2019-RK73B2ATTD221JCT-ND | C5120092 | R3,R4 | 0805 | 220 Ohms ±5% 0.25W, 1/4W Chip Resistor 0805 (2012 Metric) Automotive AEC-Q200 Thick Film | Subst any 220Ohm 0.25w 0805 resistor
CR0805-JW-471ELF | Bourns | 2 | 652-CR0805JW-471ELF | 118-CR0805-JW-471ELFCT-ND | C17710 | R7,R8 | 0805 | 470 Ohms ±5% 0.125W, 1/8W Chip Resistor 0805 (2012 Metric) Moisture Resistant Thick Film | Subst any 470Ohm 0.125w 0805 resistor
SC0915 | Raspberry Pi | 1 | 358-SC0915 | 2648-SC0915CT-ND | C2905423 | U1 |  | Single Board Computers Raspberry Pi Pico | Pico W and Pico H also work
74LVC244APW,118 | Nexperia | 1 | 771-74LVC244APW-T | 1727-2875-1-ND | C6079 | U2 | TSSOP-20 | Buffer, Non-Inverting 2 Element 4 Bit per Element 3-State Output 20-TSSOP
SN74CB3T3257 | Texas Instruments | 2 | 595-SN74CB3T3257PWR | 296-17850-1-ND | C544573 | U3,U4 | TSSOP-14 | Encoders, Decoders, Multiplexers & Demultiplexers 4-Bit 1-OF-2 FET Mltplx/Demultplxr
74AHC14S14-13 | Diodes Incorporated | 1 | 621-74AHC14S14-13 | 31-74AHC14S14-13CT-ND | C6942 | U5 | SOIC-14 | Inverter IC 6 Channel Schmitt Trigger 14-TSSOP | Subst any 74LVC14
74LVC00AS14-13 | Diodes Incorporated | 1 | 621-74LVC00AS14-13 | 31-74LVC00AS14-13CT-ND | C526338 | U6 | SOIC-14 | NAND Gate IC 4 Channel 14-SO | Subst any 74LVC00
SN74LVC1G00DBVR | Texas Instruments | 1 | 595-SN74LVC1G00DBVR | 74LVC1G00W5-7DICT-ND | C7826 | U7 | SOT-23-5 | Logic Gates 2-Input | Subst any 74LVC1G00
APS6404L-3SQR-SN | AP Memory Technology | 1 | 878-APS6404L-3SQR-SN | 1528-4677-ND | C139966 | U8 | SOIC-8 | DRAM IoT RAM 64Mb QSPI (x1,x4) SDR 133/84MHz, RBX, 3V, Ind. Temp., SOP8 | Subst Adafruit 4677, Vilsion Tech VTI7064MSME, ISSI IS66WVS1M8BLL-104NLI, IPUS IPS6404, Lyontek LY68L6400SLIT, Espressif ESP-PSRAM64H
SN74LVC2G06DBVR | Texas Instruments | 1 | 595-SN74LVC2G06DBVR | 296-13492-1-ND | C402162 | U10 | SOT-23-6 | Buffers & Line Drivers Single Invert w/OD | Subst any 74LVC1G06

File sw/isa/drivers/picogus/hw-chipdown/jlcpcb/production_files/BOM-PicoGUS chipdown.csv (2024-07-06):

Comment | Designator | Footprint | LCSC
100Ω@100MHz | FB3,FB4 | L_0805_2012Metric | C1015
1k | R12,R14,R4,R6,R7,R8,R9 | C_0402_1005Metric | C11702
2.2uF | C18,C19 | C_0402_1005Metric | C12530
PCM5100 | U10 | TSSOP-20_4.4x6.5mm_P0.65mm | C131154
AO3401A | Q1 | SOT-23 | C15127
0.1uF | C14,C15,C16,C2,C20,C23,C26,C27,C28,C3,C30,C32,C33,C34,C35,C36,C37,C4,C45,C5,C6,C7,C8,C9 | C_0402_1005Metric | C1525
SN74CB3T3245 | U7 | TSSOP-20_4.4x6.5mm_P0.65mm | C15298
1KΩ@100MHz | FB1,FB2 | L_0805_2012Metric | C155073
1uF | C10 | C_0603_1608Metric | C15849
10u | C12,C13,C17 | C_0805_2012Metric | C15850
2.2nF | C21,C22 | C_0603_1608Metric | C1604
30pF | C24,C25 | C_0603_1608Metric | C1658
D_Schottky | D2 | D_SOD-323_HandSoldering | C191023
RP2040 | U12 | QFN-56-1EP_7x7mm_P0.4mm_EP3.2x3.2mm_ThermalVias | C2040
USB_A - joy | J5 | USB-A_902-131A1011D10100 | C2345
27 | R15,R16 | C_0402_1005Metric | C25100
470 | R10,R11,R13 | R_0402_1005Metric | C25117
10K | R1,R5 | R_0402_1005Metric | C25744
15K | R17,R18 | R_0402_1005Metric | C25756
APS6404L-3SQR-SN | U8 | SOIC-8_3.9x4.9mm_P1.27mm | C261881
3.5mm TRS | J7 | Jack_3.5mm_CUI_SJ1-3535NG_Horizontal | C2910528
Wavetable | J8 | Wavetable | C358701
USB_B_Micro - program | J6 | USB-microB_U254-051T-4BH83-F1S | C397452
2.2uF | C39,C40,C41,C42,C43,C44 | CP_Elec_4x5.4 | C445039
IRQDMA_JP | J3 | PinHeader_2x09_P2.54mm_Vertical | C492426
220 | R2,R3 | R_0805_2012Metric | C5120092
1u | C29,C31 | C_0402_1005Metric | C52923
SW_Push | SW1 | SW_SPST_TL3305A | C5342982
SN74CB3T3257 | U1,U2 | TSSOP-16_4.4x5mm_P0.65mm | C544573
74LVC2G06 | U6 | SOT-363_SC-70-6 | C548560
AMS1117-3.3_SOT223 | U9 | SOT-223-3_TabPin2 | C6186
M62429L | U13 | SOIC-8_3.9x4.9mm_P1.27mm | C668666
3.5mm TRS | J9 | Jack_3.5mm_CUI_SJ1-3535NG_Horizontal | C692438
LED | D1 | LED_0603_1608Metric | C72038
74AHC14 | U3 | TSSOP-14_4.4x5mm_P0.65mm | C7460
Polyfuse | F1 | Fuse_1206_3216Metric | C75464
74LVC00 | U4,U5 | TSSOP-14_4.4x5mm_P0.65mm | C7803
W25Q128JVS | U11 | SOIC-8_5.23x5.23mm_P1.27mm | C82317
ABLS-12.000MHZ-B4-T | Y1 | Crystal_SMD_3225-4Pin_3.2x2.5mm | C9002
47uF | C1,C11,C38 | C_1206_3216Metric | C96123

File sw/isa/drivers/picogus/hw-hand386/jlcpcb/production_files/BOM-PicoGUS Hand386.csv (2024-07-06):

Comment | Designator | Footprint | LCSC
1K | R8 | R_0402_1005Metric | C11702
2.2uF | C11,C12 | C_0402_1005Metric | C12530
PCM5100 | U10 | TSSOP-20_4.4x6.5mm_P0.65mm | C131154
74AHC14 | U5 | TSSOP-14_4.4x5mm_P0.65mm | C138310
0.1uF | C13,C14,C15,C16,C20,C3,C4,C5,C6,C7,C8,C9 | C_0402_1005Metric | C1525
SN74CB3T3245 | U2 | TSSOP-20_4.4x6.5mm_P0.65mm | C15298
2.2nF | C18,C19 | C_0402_1005Metric | C1531
33 | R4 | R_0805_2012Metric | C161967
10uF | C17 | C_0603_1608Metric | C19702
470 | R5,R6 | R_0402_1005Metric | C25117
10K | R1,R2,R7 | R_0402_1005Metric | C25744
APS6404L-3SQN-SN | U8 | SOIC-8_3.9x4.9mm_P1.27mm | C3028887
1K @ 100MHz | FB1,FB2 | L_0603_1608Metric | C50069
1uF | C10 | C_0402_1005Metric | C52923
SN74CB3T3257 | U3,U4 | TSSOP-16_4.4x5mm_P0.65mm | C544573
AudioJack3 | J5 | PJ-231F-4A | C707219
10 | R3 | R_0805_2012Metric | C728003
74LVC00 | U6 | TSSOP-14_4.4x5mm_P0.65mm | C7803
74LVC1G00 | U7 | SOT-23-5 | C7826
74LVC1G06 | U9 | SOT-23-5 | C840103
1A 20V Schottky | D1 | D_SOD-123 | C8598
AudioJack3 | J1 | PJ-321A | C879743
47uF | C1,C2 | C_1206_3216Metric | C96123
Bus_ISA_8bit | J3 | EDGE-60

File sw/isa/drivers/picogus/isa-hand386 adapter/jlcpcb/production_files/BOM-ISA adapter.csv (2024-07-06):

Comment | Designator | Footprint | LCSC
1K | R1,R2,R3,R4 | R_0805_2012Metric | C17513
10K | RV1 | RK10J12R0A0B | C351175
100nF | C1 | C_0805_2012Metric | C49678
74HC14 | U1 | SOIC-14_3.9x8.7mm_P1.27mm | C5605
Bus_ISA_8bit | J3 | BUS_PC
MountingHole_3.2mm_M3_Pad | H1 | MountingHole_3.2mm_M3_ISO14580_Pad
Conn_02x30_Odd_Even | J1 | Hand386_PicoGUS
IRQDMA_JP | J4 | PinHeader_2x09_P2.54mm_Vertical
MountingHole_3.2mm_M3_Pad | H2 | MountingHole_3.2mm_M3_ISO14580_Pad
AudioJack3 | J6 | Jack_3.5mm_CUI_SJ1-3535NG_Horizontal
Wavetable | J5 | Wavetable

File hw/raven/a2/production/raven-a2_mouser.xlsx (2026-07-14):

RAVEN_A2
Mouser nr | Tillverk: Nr. | Tillverkare | Kundens artikelnummer | Beskrivning | RoHS-direktivet | Livscykel | Ordermängd. | Pris (SEK) | Totalsumma: (SEK)
667-ECE-A1AKS101I | ECE-A1AKS101I | Panasonic |  | Aluminumelektrolytkondensatorer - radiella med ben 10VDC 100uF SU | Överensstämmer med RoHS-direktiv |  | 1 | 2,64 kr | 2,64 kr
667-ECE-A1HKS100I | ECE-A1HKS100I | Panasonic |  | Aluminumelektrolytkondensatorer - radiella med ben 50VDC 10uF POLARIZED | Överensstämmer med RoHS-direktiv |  | 14 | 1,42 kr | 19,88 kr
667-ECE-A1HKS4R7 | ECE-A1HKS4R7 | Panasonic |  | Aluminumelektrolytkondensatorer - radiella med ben 50VDC 4.7uF POLARIZED | Överensstämmer med RoHS-direktiv |  | 4 | 2,73 kr | 10,92 kr
80-C1206C106K4R | C1206C106K4RACTU | KEMET |  | Flerskiktade keramiska kondensatorer MLCC - SMD/SMT 16V 10uF X7R 1206 10% | Överensstämmer med RoHS-direktiv |  | 10 | 1,27 kr | 12,70 kr
80-C1206C225K4R | C1206C225K4RACTU | KEMET |  | Flerskiktade keramiska kondensatorer MLCC - SMD/SMT 16V 2.2uF X7R 1206 10% | Överensstämmer med RoHS-direktiv |  | 2 | 2,92 kr | 5,84 kr
80-C1206C105K4R | C1206C105K4RACTU | KEMET |  | Flerskiktade keramiska kondensatorer MLCC - SMD/SMT 16V 1uF X7R 1206 10% | Överensstämmer med RoHS-direktiv |  | 13 | 0,912 kr | 10,03 kr
80-C1206C474K5R | C1206C474K5RACTU | KEMET |  | Flerskiktade keramiska kondensatorer MLCC - SMD/SMT 50V 0.47uF X7R 1206 10% | Överensstämmer med RoHS-direktiv |  | 1 | 2,64 kr | 2,64 kr
80-C1206C104K5R | C1206C104K5RACTU | KEMET |  | Flerskiktade keramiska kondensatorer MLCC - SMD/SMT 50V 0.1uF X7R 1206 10% | Överensstämmer med RoHS-direktiv |  | 80 | 0,371 kr | 29,68 kr
80-C1206C103K5R | C1206C103K5RACTU | KEMET |  | Flerskiktade keramiska kondensatorer MLCC - SMD/SMT 50V 0.01uF X7R 1206 10% | Överensstämmer med RoHS-direktiv |  | 2 | 1,46 kr | 2,92 kr
80-C1206C272K5R | C1206C272K5RACTU | KEMET |  | Flerskiktade keramiska kondensatorer MLCC - SMD/SMT 50V 2700pF X7R 1206 10% | Överensstämmer med RoHS-direktiv |  | 1 | 2,64 kr | 2,64 kr
80-C1206C330J1G | C1206C330J1GACTU | KEMET |  | Flerskiktade keramiska kondensatorer MLCC - SMD/SMT 100V 33pF C0G 1206 5% | Överensstämmer med RoHS-direktiv |  | 2 | 2,10 kr | 4,20 kr
603-RT1206FRE0747KL | RT1206FRE0747KL | YAGEO |  | Tunnfilmsresistorer - SMD 1/4W 47K ohm 1% 50ppm | RoHS överensstämmelse genom undantag |  | 12 | 0,233 kr | 2,80 kr
603-RT1206FRE0710KL | RT1206FRE0710KL | YAGEO |  | Tunnfilmsresistorer - SMD 1/4W 10K ohm 1% 50ppm | RoHS överensstämmelse genom undantag |  | 50 | 0,233 kr | 11,65 kr
603-RT1206FRE074K7L | RT1206FRE074K7L | YAGEO |  | Tunnfilmsresistorer - SMD 4.7K Ohm 1% 1/4W 200 Volts 50ppm | RoHS överensstämmelse genom undantag |  | 10 | 0,233 kr | 2,33 kr
603-RT1206FRE072K2L | RT1206FRE072K2L | YAGEO |  | Tunnfilmsresistorer - SMD 1/4W 2.2K ohm 1% 50ppm | RoHS överensstämmelse genom undantag |  | 10 | 0,223 kr | 2,23 kr
603-RT1206FRE071KL | RT1206FRE071KL | YAGEO |  | Tunnfilmsresistorer - SMD 1/4W 1K ohm 1% 50ppm | RoHS överensstämmelse genom undantag |  | 15 | 0,223 kr | 3,35 kr
603-RT1206FRE07220RL | RT1206FRE07220RL | YAGEO |  | Tunnfilmsresistorer - SMD 1/4W 220 ohm 1% 50ppm | RoHS överensstämmelse genom undantag |  | 10 | 0,233 kr | 2,33 kr
603-RT1206FRE0733RL | RT1206FRE0733RL | YAGEO |  | Tunnfilmsresistorer - SMD 1/4W 33 ohm 1% 50ppm | RoHS överensstämmelse genom undantag |  | 10 | 0,233 kr | 2,33 kr
858-L091S472LF | L091S472LF | TT Electronics |  | Motståndsnätverk och -matriser 4.7K OHM 9 PIN | RoHS överensstämmelse genom undantag |  | 4 | 8,56 kr | 34,24 kr
858-L091S102LF | L091S102LF | TT Electronics |  | Motståndsnätverk och -matriser 1K OHM 9 PIN | RoHS överensstämmelse genom undantag |  | 12 | 4,82 kr | 57,84 kr
750-CGRKM4001-HF | CGRKM4001-HF | Comchip Technology |  | Likriktare 1.0A 50V SMD Gen Purpose rect | Överensstämmer med RoHS-direktiv |  | 3 | 3,65 kr | 10,95 kr
821-1N914BWRHG | 1N914BW RHG | Taiwan Semiconductor |  | Kopplingsdioder för små signaler 75V, 0.15A, Switching Diode & Array | Överensstämmer med RoHS-direktiv |  | 1 | 1,46 kr | 1,46 kr
771-PMEG2010ER115 | PMEG2010ER,115 | Nexperia |  | Schottky-dioder och -likriktare RECT 20V 1A SM SCHOTTKY | RoHS överensstämmelse genom undantag |  | 1 | 3,65 kr | 3,65 kr
871-B57621C5103J62 | B57621C5103J62 | TDK |  | NTC-termistorer NTC THERMISTOR 1206 10K J62 B-35300 | Överensstämmer med RoHS-direktiv |  | 1 | 11,02 kr | 11,02 kr
710-61300211121 | 61300211121 | Wurth Elektronik |  | List- och kabelhölje WR-PHD 2.54mm 2Pin T HT Header | Överensstämmer med RoHS-direktiv |  | 2 | 1,19 kr | 2,38 kr
710-61300311121 | 61300311121 | Wurth Elektronik |  | List- och kabelhölje WR-PHD 2.54mm Hdr 3P Single Str Gold | Överensstämmer med RoHS-direktiv |  | 2 | 1,19 kr | 2,38 kr
710-61300411121 | 61300411121 | Wurth Elektronik |  | List- och kabelhölje WR-PHD 2.54mm Hdr 4P Single Str Gold | Överensstämmer med RoHS-direktiv |  | 4 | 1,73 kr | 6,92 kr
710-61300821121 | 61300821121 | Wurth Elektronik |  | List- och kabelhölje WR-PHD 2.54mm Hdr 8P Dual Str Gold | Överensstämmer med RoHS-direktiv |  | 1 | 6,38 kr | 6,38 kr
710-61301021121 | 61301021121 | Wurth Elektronik |  | List- och kabelhölje WR-PHD 2.54mm THT 10 Pin Dual Pin Headr | Överensstämmer med RoHS-direktiv |  | 1 | 10,03 kr | 10,03 kr
710-61201021621 | 61201021621 | Wurth Elektronik |  | List- och kabelhölje WR-BHD 2.54mm Box 10Pin Male Straight | Överensstämmer med RoHS-direktiv |  | 2 | 4,28 kr | 8,56 kr
710-62004421121 | 62004421121 | Wurth Elektronik |  | List- och kabelhölje WR-PHD 2.0mm THT 44P in Dual Pin Headr | Överensstämmer med RoHS-direktiv |  | 1 | 17,60 kr | 17,60 kr
571-1-1775099-3 | 1-1775099-3 | TE Connectivity |  | Ström till kortet ATX PWR CONN 1 BDLK 24 POS | Överensstämmer med RoHS-direktiv |  | 1 | 8,56 kr | 8,56 kr
571-5176139-2 | 5176139-2 | TE Connectivity |  | Standard kortkantskontakter CONN SEC II 49P 100C/L | Överensstämmer med RoHS-direktiv |  | 4 | 57,24 kr | 228,96 kr
571-5822030-3 | 5822030-3 | TE Connectivity |  | SIMM-kontakter LEFT POLARIZATION 72 tin | Överensstämmer med RoHS-direktiv |  | 4 | 64,13 kr | 256,52 kr
538-171856-1003 | 171856-1003 | Molex |  | List- och kabelhölje KK Hdr Vrt 3 Ckt 2.54mm Pitch 15um Au | Överensstämmer med RoHS-direktiv |  | 3 | 5,29 kr | 15,87 kr
538-47053-1000 | 47053-1000 | Molex |  | List- och kabelhölje 4P VERT HDR W/FL | Överensstämmer med RoHS-direktiv |  | 1 | 4,74 kr | 4,74 kr
575-8001000410001000 | 800-10-004-10-001000 | Mill-Max |  | List- och kabelhölje STANDARD PIN HEADER | RoHS överensstämmelse genom undantag |  | 1 | 25,12 kr | 25,12 kr
855-S8401-46 | S8401-46 | Harwin |  | Hållare för myntcellsbatteri S84 EZ BDWR, SMT COIN CELL HOLDER CR2032 | Överensstämmer med RoHS-direktiv |  | 1 | 18,34 kr | 18,34 kr
523-L17H26R0121 | L17H26R0121 | Amphenol |  | D-sub-dualport kontaktdon DUAL PORT D SUB |  |  | 1 | 68,90 kr | 68,90 kr
806-K42X-E9P/P-A4NJ | K42X-E9P/P-A4NJ | Kycon |  | D-sub-dualport kontaktdon DL-PRT 9M O/ 9M-750 4GB JS | RoHS överensstämmelse genom undantag |  | 1 | 99,00 kr | 99,00 kr
806-STX-4235-3/3-N | STX-4235-3/3-N | Kycon |  | Telefonkontakter 3.5mm STACKED STEREO 3P OVER 3P NONTHREA | Överensstämmer med RoHS-direktiv |  | 1 | 19,40 kr | 19,40 kr
640-USB1035GFP0BB | USB1035-GF-P-0-B-B | GCT |  | USB-anslutningar USB A Skt, Dual Top TH R/A, GF, BLK, No ground, W/stake, tray | Överensstämmer med RoHS-direktiv |  | 1 | 5,83 kr | 5,83 kr
571-1-2199298-8 | 1-2199298-8 | TE Connectivity |  | IC och komponentuttag 24P DIP SKT 300 CL LADDER | Ej tillämplig |  | 2 | 7,11 kr | 14,22 kr
571-1-2199298-9 | 1-2199298-9 | TE Connectivity |  | IC och komponentuttag 28P DIP SKT 300 CL LADDER | Överensstämmer med RoHS-direktiv |  | 1 | 8,02 kr | 8,02 kr
517-4840-6000-CP | 4840-6000-CP | 3M |  | IC och komponentuttag 40P DUAL WIPE DIPSKT | Överensstämmer med RoHS-direktiv |  | 1 | 8,94 kr | 8,94 kr
517-4848-6000-CP | 4848-6000-CP | 3M |  | IC och komponentuttag 48P DUAL WIPE DIPSKT | Överensstämmer med RoHS-direktiv |  | 2 | 12,40 kr | 24,80 kr
517-8468-11B1-RK-TP | 8468-11B1-RK-TP | 3M |  | IC och komponentuttag 68P PLCC SOCKET THRU-HOLE | Överensstämmer med RoHS-direktiv | Utgående | 1 | 26,82 kr | 26,82 kr
517-8484-11B1-RK-TP | 8484-11B1-RK-TP | 3M |  | IC och komponentuttag 84P PLCC SOCKET THRU-HOLE | Överensstämmer med RoHS-direktiv | Utgående | 1 | 31,27 kr | 31,27 kr
737-MSA-G | MSA-G | Adam Tech |  | List- och kabelhölje CLOSED TOP .100 GOLD PLATED | Överensstämmer med RoHS-direktiv |  | 8 | 0,912 kr | 7,30 kr
688-SKHHAK | SKHHAKA010 | Alps Alpine |  | Taktil-omkopplare 6.0x6.0x5.0mm 100gf | Överensstämmer med RoHS-direktiv |  | 3 | 2,75 kr | 8,25 kr
595-SN74LS07DR | SN74LS07DR | Texas Instruments |  | Buffertar och linjedrivare Hex W/ OC HV Out A 5 95-SN74LS07D A 595- A 595-SN74LS07D | Överensstämmer med RoHS-direktiv |  | 1 | 5,65 kr | 5,65 kr
595-SN74LS148DR | SN74LS148DR | Texas Instruments |  | Kodare, avkodare, multiplexrar och demultiplexrar 8 to 3 Priority A 59 5-SN74LS148D A 595- A 595-SN74LS148D | Överensstämmer med RoHS-direktiv |  | 1 | 15,90 kr | 15,90 kr
595-CD74HCT10M96G4 | CD74HCT10M96G4 | Texas Instruments |  | Logikgrindar Hi Spd CMOS Log Tr 3 -Input NAND ALT 595 ALT 595-CD74HCT10M96 | Överensstämmer med RoHS-direktiv | Utgående | 1 | 4,20 kr | 4,20 kr
595-SN74LVC1G14DBVR | SN74LVC1G14DBVR | Texas Instruments |  | Växelriktare SINGLE SCHMITT TRIGG ER INVERTER A 595-S A 595-SN74LVC1G14DBVT | Överensstämmer med RoHS-direktiv |  | 1 | 1,09 kr | 1,09 kr
771-AHC157D118 | 74AHC157D,118 | Nexperia |  | Kodare, avkodare, multiplexrar och demultiplexrar SOT109-1 QUAD 2INPUT MULTPLXR | Överensstämmer med RoHS-direktiv |  | 1 | 2,92 kr | 2,92 kr
771-74LVCH16245ADG11 | 74LVCH16245ADGG,11 | Nexperia |  | Buss-transceiver SOT362-1 BUS TRANSCEIVER | Överensstämmer med RoHS-direktiv |  | 2 | 7,75 kr | 15,50 kr
556-ATF1508AS-7JX84 | ATF1508AS-7JX84 | Microchip |  | EEPLD - Elektroniskt raderbara, logiska programmeringsenheter 128 MC CPLD 7NS IND TEMP GRN | Överensstämmer med RoHS-direktiv | Utgående | 1 | 127,62 kr | 127,62 kr
556-ATF22V10C-10PU | ATF22V10C-10PU | Microchip |  | EEPLD - Elektroniskt raderbara, logiska programmeringsenheter 500 Gate SPLD 5V 24pin | Överensstämmer med RoHS-direktiv |  | 2 | 23,96 kr | 47,92 kr
579-24AA02E48TIOT | 24AA02E48T-I/OT | Microchip |  | EEPROM 2K, 256x8 1.8V Serial EE | Överensstämmer med RoHS-direktiv |  | 1 | 2,83 kr | 2,83 kr
700-MAX3245CAIT | MAX3245CAI+T | Analog Devices Inc. |  | RS-232, IC-gränssnitt 1 A Supply Current, 1Mbps, 3.0V to 5.5V, RS-232 Transceivers with AutoShutdown Plus | Överensstämmer med RoHS-direktiv |  | 2 | 63,07 kr | 126,14 kr
700-MAX16054AZTT | MAX16054AZT+T | Analog Devices Inc. |  | Övervakningskretsar On/Off Controller with Debounce and 15kV ESD Protection | Överensstämmer med RoHS-direktiv |  | 1 | 39,43 kr | 39,43 kr
700-DS1818R-10T&R | DS1818R-10+T&R | Analog Devices Inc. |  | Övervakningskretsar 3.3V EconoReset with Pushbutton | Överensstämmer med RoHS-direktiv |  | 1 | 40,70 kr | 40,70 kr
700-DS1307ZT&R | DS1307Z+T&R | Analog Devices Inc. |  | Realtidsklocka 64 x 8, Serial, I C Real-Time Clock | Överensstämmer med RoHS-direktiv |  | 1 | 49,40 kr | 49,40 kr
727-CY2308SXC-2 | CY2308SXC-2 | Infineon |  | Klockbuffert 3.3VZDB COM | Överensstämmer med RoHS-direktiv | Utgående | 1 | 110,03 kr | 110,03 kr
701-XR68M752IM48-F | XR68M752IM48-F | MaxLinear |  | UART, IC-gränssnitt UART | Överensstämmer med RoHS-direktiv |  | 1 | 85,75 kr | 85,75 kr
782-CNY17F-3 | CNY17F-3 | Vishay |  | Transistor, utmatningsoptokopplare Phototransistor Out Single CTR 100-200% | Överensstämmer med RoHS-direktiv |  | 1 | 5,75 kr | 5,75 kr
579-MCP4251-103-E/SL | MCP4251-103E/SL | Microchip |  | Digital IC-potentiometer Dual 8B V SPI POT | Överensstämmer med RoHS-direktiv |  | 1 | 11,34 kr | 11,34 kr
621-PAM8302AADCR | PAM8302AADCR | Diodes Incorporated |  | Ljudförstärkare 2.5W MONO FILTERLESS CLASS-D AUDIO AMP | Överensstämmer med RoHS-direktiv |  | 1 | 5,11 kr | 5,11 kr
595-PCM1808PW | PCM1808PW | Texas Instruments |  | IC-omvandlare för A/D-ljud Sgl-ended Ana Input 24B 96kHz Stereo ADC A 595-PCM1808PWR | Överensstämmer med RoHS-direktiv |  | 1 | 19,82 kr | 19,82 kr
595-PCM5102APWR | PCM5102APWR | Texas Instruments |  | IC-omvandlare för D/A-ljud 2VRMS DirectPath 112 dB Audio Stereo DAC A 595-PCM5102APW | Överensstämmer med RoHS-direktiv |  | 1 | 32,86 kr | 32,86 kr
926-LM7905CT/NOPB | LM7905CT/NOPB | Texas Instruments |  | Linjära spänningsregulatorer 3-Terminal Neg Vltg | Överensstämmer med RoHS-direktiv |  | 1 | 14,31 kr | 14,31 kr
913-AS7C31024B12TJCN | AS7C31024B-12TJCN | Alliance Memory |  | SRAM SRAM, 1Mb, 128K x 8, 3.3V, 32pin 300 mil SOJ, 12ns, Commercial Temp - Tube | Överensstämmer med RoHS-direktiv |  | 3 | 89,15 kr | 267,45 kr
815-ACH-14.31818EK | ACH-14.31818MHZ-EK | ABRACON |  | Standardklockoscillatorer Crystal Oscillator 8-DIP, 4 Leads (Half Size, Metal Can) 14.31818MHz 30ppm -20C - 70C CMOS 5V | Överensstämmer med RoHS-direktiv |  | 1 | 46,64 kr | 46,64 kr
815-ASELJE225792MLRT | ASELJ-E-22.5792MHz-L-R-T | ABRACON |  | Standardklockoscillatorer Crystal Oscillator 22.5792MHz 25ppm -40C - 85C CMOS 3.3V | Överensstämmer med RoHS-direktiv | Ny produkt | 1 | 16,22 kr | 16,22 kr
815-ASE24.000MHZLCT | ASE-24.000MHZ-LC-T | ABRACON |  | Standardklockoscillatorer 24.0 MHZ 3.3V 50PPM -40+85C | Överensstämmer med RoHS-direktiv |  | 1 | 12,19 kr | 12,19 kr
815-ACHL-48-EK | ACHL-48.000MHZ-EK | ABRACON |  | Standardklockoscillatorer Crystal Oscillator 8-DIP, 4 Leads (Half Size, Metal Can) 48MHz 30ppm -20C - 70C CMOS 3.3V | Överensstämmer med RoHS-direktiv |  | 1 | 46,64 kr | 46,64 kr
815-ACH-8-EK | ACH-8.000MHZ-EK | ABRACON |  | Standardklockoscillatorer Crystal Oscillator 8-DIP, 4 Leads (Half Size, Metal Can) 8MHz 30ppm -20C - 70C CMOS 5V | Överensstämmer med RoHS-direktiv |  | 1 | 41,23 kr | 41,23 kr
774-MP024S | MP024S | CTS |  | Kristaller 2.45760 MHz 32pF | Överensstämmer med RoHS-direktiv |  | 1 | 13,99 kr | 13,99 kr
520-S-.32712.513XC | ECS-.327-12.5-13X-C | ECS |  | Kristaller CRYSTAL 32.768 kHZ 12.5 PF SMD, ESR 35K Ohms, 10ppm -20C - 70C, 2.1 x 6.2 1 w Max 3 ppm 1st Year Aging Max | Överensstämmer med RoHS-direktiv |  | 1 | 2,92 kr | 2,92 kr
535-1108800 | 1108800 | Aries Electronics |  | IC och komponentuttag OSCILLATOR HALF 4PIN | Överensstämmer med RoHS-direktiv |  | 1 | 9,57 kr | 9,57 kr

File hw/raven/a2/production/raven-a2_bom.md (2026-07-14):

# Raven060 Revision.A2

| Manufacturer | Part number | Value | Count | Note |
|---|---|---|---|---|
| Panasonic | ECE-A1AKS101 | 100u | 1 | |
| Panasonic | ECE-A1HKS100I | 10u | 14 | |
| Panasonic | ECE-A1HKS4R7 | 4u7 | 4 | |
| | | | | |
| Kemet | C1206C106K4RACTU | 10u | 8 | |
| Kemet | C1206C225K4RACTU | 2.2u | 2 | |
| Kemet | C1206C105K4RACTU | 1u | 9 | |
| Kemet | C1206C474K5RACTU | 0.47u | 1 | |
| Kemet | C1206C104K5RACTU | 0.1u | 78 | |
| Kemet | C1206C103K5RACTU | 0.01u | 2 | |
| Kemet | C1206C272K5RACTU | 2.7n | 1 | |
| Kemet | C1206C330J1GACTU | 33p | 2 | |
| | | | | |
| Yageo | RT1206FRE0747KL | 47K | 12 | |
| Yageo | RT1206FRE0710KL | 10K | 50 | |
| Yageo | RT1206FRE074K7L | 4K7 | 8 | |
| Yageo | RT1206FRE072K2L | 2K2 | 5 | |
| Yageo | RT1206FRE071KL | 1K | 15 | |
| Yageo | RT1206FRE07220RL | 220 | 5 | |
| Yageo | RT1206FRE0733RL | 33 | 5 | |
| | | | | |
| IRC / TT | L091S472LF | 4K7 | 4 | |
| IRC / TT | L091S102LF | 1K | 12 | |
| | | | | |
| Comchip | CGRKM4001-HF | 1A 50V | 3 | |
| Taiwan Semiconductor  | 1N914BW RHG | 1N914 | 1 | |
| Nexperia | PMEG2010ER | PMEG2010ER | 1 | |
| | | | | |
| TDK | B57621C5103J62 | NTC 10K | 1 | |
| | | | | |
| Wurth Elektronik | 61300211121 | PinHdr_01x02 | 2 | |
| Wurth Elektronik | 61300311121 | PinHdr_01x03 | 2 | |
| Wurth Elektronik | 61300411121 | PinHdr_01x04 | 4 | |
| Wurth Elektronik | 61300821121 | Pinhdr_02x04 | 1 | |
| Wurth Elektronik | 61301021121 | PinHdr_02x05 | 1 | |
| Wurth Elektronik | 61201021621 | BoxHdr_02x05 | 2 | |
| Wurth Elektronik | 62004421121 | IDE44 | 1 | |
| TE Connectivity | 1-1775099-3 | ATX Power | 1 | |
| TE Connectivity | 5176139-2 | ISA16 | 4 | |
| TE Connectivity | 5822030-3 | SIMM72 | 4 | |
| Molex | 171856-1003 | FanHeader | 3 | |
| Molex | 47053-1000 | FanHeader | 1 | |
| Mill-Max | 800-10-004-10-001000 | FanHeader | 1 | 1 |
| Harwin | S8401-46 | BatteryHolder | 1 | |
| Amphenol | L17H26R0121 | DB25/9/9 | 1 | |
| Kycon | K42X-E9P/P-A4NJ | DB9M/9M | 1 | |
| Kycon | STX-4235-3/3-N | TRSx2 | 1 | |
| GCT | USB1035-GF-P-0-B-B | USBx2 | 1 | |
| | | | | |
| TE Connectivity | 1-2199298-8 | DIP-24 | 2 | |
| TE Connectivity | 1-2199298-9 | DIP-28 | 1 | |
| 3M | 4840-6000-CP | DIP-40 | 1 | |
| 3M | 4848-6000-CP | DIP-48 | 2 | |
| 3M | 8468-11B1-RK-TP | PLCC-68 | 1 | |
| 3M | 8484-11B1-RK-TP | PLCC-84 | 1 | |
| Aries Electronics | 1108800 | OscHalf | 1 | |
| | | | | |
| Adam Tech | MSA-G | Jumper | 8 | |
| Alps Alpine | SKHHAKA010 | Button | 3 | |
| | | | | |
| Texas Instruments | SN74LS07DR | 74LS07 | 1 | |
| Texas Instruments | SN74LS148DR | 74LS148 | 1 | |
| Texas Instruments | CD74HCT10M96G4 | 74HCT10 | 1 | |
| Texas Instruments | SN74LVC1G14DBVT | SN74LVC1G14 | 1 | |
| Nexperia | 74AHC157D,118 | 74AHC157 | 1 | |
| Nexperia | 74LVCH16245ADGG,11 | SN74LVCH16245 | 2 | |
| Microchip | ATF1508AS-7JX84 | ATF1508 | 1 | |
| Microchip | ATF22V10C-10PU | ATF22V10 | 2 | |
| Microchip | 24AA02E48T-I/OT | 24AA02E48 | 1 | |
| Analog Devices | MAX3245CAI+T | MAX3245 | 2 | |
| Analog Devices | MAX16054AZT+T | MAX16054 | 1 | |
| Analog Devices | DS1818R-10+T&R | DS1818 | 1 | |
| Analog Devices | DS1307Z+T&R | DS1307 | 1 | |
| Infineon Technologies | CY2308SXC-2 | CY2308 | 1 | |
| MaxLinear | XR68M752IM48-F | XR68M752 | 1 | |
| Vishay | CNY17F-3 | CNY17F-3 | 1 | |
| Microchip | MCP4251T-103E/SL | MCP4251 | 1 | |
| Diodes Incorporated | PAM8302AADCR | PAM8302 | 1 | |
| Texas Instruments | PCM1808PW | PCM1808 | 1 | |
| Texas Instruments | PCM5102APWR | PCM5102A | 1 | |
| Texas Instruments | LM7905CT/NOPB | LM7905 | 1 | |
| Alliance Memory | AS7C31024B-12TJCN | AS7C31024B | 3 | |
| | | | | |
| Abracon | ACH-14.31818MHZ-EK | 14.31818Mhz (5V)  | 1 | |
| Abracon | ASELJ-E-22.5792MHz-L-R-T | 22.5792MHz (3.3V) | 1 | |
| Abracon | ASE-24.000MHZ-L-C-T | 24Mhz (3.3V) | 1 | |
| Abracon | ACHL-48.000MHZ-EK | 48Mhz (3.3V) | 1 | |
| Abracon | ACH-8.000MHZ-EK | 8Mhz (5V) | 1 | |
| CTS | MP024S | 2.4576Mhz | 1 | |
| ECS | ECS-.327-12.5-13X-C | 32.768kHz | 1 | |
|-----------------------|--------------------------|-------------------|-------|------|
| WCH | CH559L | CH559 | 1 | |
| Yamaha | YM2149 | YM2149 | 1 | |
| Motorola | MC68060RC50 | MC68060 | 1 | |
| Motorola | MC68150FN40 | MC68150 | 1 | |
| Motorola | MC68901P | MC68901 | 2 | |
| Motorola | DSP56303AG100 | DSP56303 | 1 | |
| Archi-TECH | 1870-5222B | PGA-206 | 1 | |

1. Solder with thiner, shorter, pin facing up.
   Alternative part number 350-10-104-00-001000 might be better for a bit longer pins.

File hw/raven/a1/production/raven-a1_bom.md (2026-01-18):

Raven060 Revision.A1

| Manufacturer | Part number | Value | Count | Note |
|---|---|---|---|---|
| Panasonic | EEU-EB1H100SH | 10u | 12 | |
| Panasonic | EEU-EB1H4R7SH | 4u7 | 4 | |
| Kemet | C1206C105K4RACTU | 1u | 4 | |
| Kemet | C1206C104K5RACTU | 0.1u | 52 | |
| Kemet | C1206C103K2RACTU | 0.01u | 1 | |
| Kemet | C1206C330J1GACTU | 33p | 2 | |
| | | | | |
| Yageo | RT1206FRE0710KL | 10k | 18 | |
| Yageo | RT1206FRE074K7L | 4k7 | 8 | |
| Yageo | RT1206FRE072K2L | 2k2 | 3 | |
| Yageo | RT1206FRE071KL | 1k | 11 | |
| Yageo | RT1206FRE07470RL | 470 | 12 | |
| Yageo | RT1206FRE07220RL | 220 | 3 | |
| Yageo | RT1206FRE0733RL | 33 | 4 | |
| | | | | |
| IRC/TT | L091S103LF | 10k | 2 | |
| IRC/TT | L091S472LF | 4k7 | 2 | |
| IRC/TT | L091S102LF | 1k | 13 | |
| | | | | |
| Comchip | CGRKM4001-HF | 1A50V | 3 | |
| Taiwan Semiconductor  | 1N914BW RHG | 1N914 | 1 | |
| | | | | |
| TDK | B57621C5103J62 | ntc10k | 1 | |
| | | | | |
| Wurth Elektronik | 61300211121 | 01x02 | 2 | |
| Wurth Elektronik | 61300311121 | 01x03 | 4 | |
| Wurth Elektronik | 61300411121 | 01x04 | 3 | |
| Wurth Elektronik | 61300821121 | 02x04 | 1 | |
| Wurth Elektronik | 61301021121 | 02x05 | 1 | |
| Wurth Elektronik | 61201021621 | jtag | 1 | |
| TE Connectivity | 1-1775099-3 | atx | 1 | (1)  |
| TE Connectivity | 5822030-3 | simm | 4 | |
| TE Connectivity | 5176139-2 | isa | 4 | |
| Molex | 87831-4420 | ide44 | 1 | (6)  |
| Molex | 171856-1003 | fan | 4 | |
| Harwin | S8401-46 | bat | 1 | |
| Amphenol | L17H26R0121 | db25/9/9 | 1 | |
| Kycon | STX-4235-3/3-N | trsx2 | 1 | |
| Kycon | K42X-E9P/P-A4NJ | db9/9 | 1 | |
| Kycon | KMDGX-6SG/P-S4N | ps2x2 | 1 | |
| | | | | |
| TE Connectivity | 1-2199298-8 | dip24 | 2 | |
| TE Connectivity | 1-2199298-9 | dip28 | 1 | |
| 3M | 4840-6000-CP | dip40 | 1 | |
| 3M | 4848-6000-CP | dip48 | 2 | |
| Preci-dip | 540-88-068-24-008 | plcc68 | 1 | (2)  |
| Preci-dip | 540-88-084-24-008 | plcc84 | 1 | (2)  |
| Aries Electronics | 1108800 | osc8 | 1 | |
| | | | | |
| TE Connectivity | 1-881545-4 | jumper | 8 | (4)  |
| Alps Alpine | SKHHARA010 | button | 3 | (3)  |
| | | | | |
| Texas Instruments | SN74LS07DR | 74ls07 | 1 | |
| Texas Instruments | SN74LS148DR | 74ls148 | 1 | |
| Texas Instruments | CD74HCT10M96G4 | 74hct10 | 1 | |
| Nexperia | 74AHC157D,118 | 74ahc157 | 1 | |
| Nexperia | 74LVCH16245ADGG,11 | 74lvch16245 | 2 | |
| Microchip | ATF1508AS-7JX84 | atf1508 | 1 | |
| Microchip | ATF22V10C-10PU | atf22v10 | 2 | |
| Microchip | PIC16F876A-I/SP | pic16 | 1 | |
| Analog Devices | MAX3245CAI+T | max3245 | 2 | |
| Analog Devices | MAX16054AZT+T | max16054 | 1 | |
| Analog Devices | DS1818-10+T&R | ds1818 | 1 | |
| Analog Devices | DS1307Z+T&R | ds1307 | 1 | |
| Texas Instruments | TXU0202DCUR | txu0202 | 1 | |
| Texas Instruments | LM7905CT/NOPB | lm7905 | 1 | |
| Infineon Technologies | CY2308SXC-2 | cy2308 | 1 | |
| MaxLinear | XR68M752IM48-F | xr68m752 | 1 | |
| Vishay | CNY17F-3 | cny17f-3 | 1 | |
| Vishay | IRF510PBF | irf510 | 1 | |
| | | | | |
| Abracon | ACHL-48.000MHZ-EK | 48m | 1 | (5)  |
| Abracon | ASV-24.000MHZ-EJ-T | 24m | 1 | |
| Abracon | ACH-8.000MHZ-EK | 8m | 1 | |
| Abracon | ACH-14.31818MHZ-EK | 14.31818m | 1 | |
| CTS | MP024S | 2.4576m | 1 | |
| ECS | ECS-.327-12.5-13X-C | 32.768k | 1 | |
|-----------------------|-----------------------------|-------------|-------|------|
| Yamaha | YM2149F | YM2149 | 1 | |
| Motorola | MC68150FN40 | MC68150 | 1 | (5)  |
| Motorola | MC68060RC50 | MC68060 | 1 | (5)  |
| Motorola | MC68901P | MC68901 | 2 | |
| Archi-Tech | 1870-5222B | pga206 | 1 | |

(1) connector is white. todo: find a black alternative.

(2) sockets are brown. possible black replacements (not tested)
 * 8468-11B1-RK-TP, 3M (PLCC68)
 * 8484-11B1-RK-TP, 3M (PLCC84)

(3) buttons are red, possible black replacement (not tested)
 * SKHHAKA010, Alps Alpine

(4) these jumpers are very hard to grab. todo: find better alternative.

(5) for 48mhz bus speed and 96/48 cpu.

(6) This socket is too narrow for IDC cable connectors.
    Don't have a part number but IDC box headers for 44pin ATA is
    available all over the place.
    Alternatively, use a normal 2mm pitch 2x22pin pin header such
    as: Wurth 62004421121

You may need to use a slower oscillator depending on your MC68060 / MC68150 combination. 
I don't know how far a lower rated MC68150FN33 overclocks but the 40mzh version seems comfortable at 48mhz.

My own revision.A0 build was tested with these following speeds:
- 48mhz bus, 96mhz cpu
- 25mhz bus, 50mhz cpu

The CPU can be either the full version or the LC variant without FPU. An MMU is required so EC models cannot be used.

I recommend the full version unless you are comfortable recompiling software to get rid of fpu requirement, want to implement a soft-fpu emulator, or just generally don't mind being in uncharted territory and enjoys troubleshooting old applications from the 90's.
A lot of Atari software is going to assume that there is an FPU if you have a 68060, they might even refuse to start even if they aren't
actually using it for anything.

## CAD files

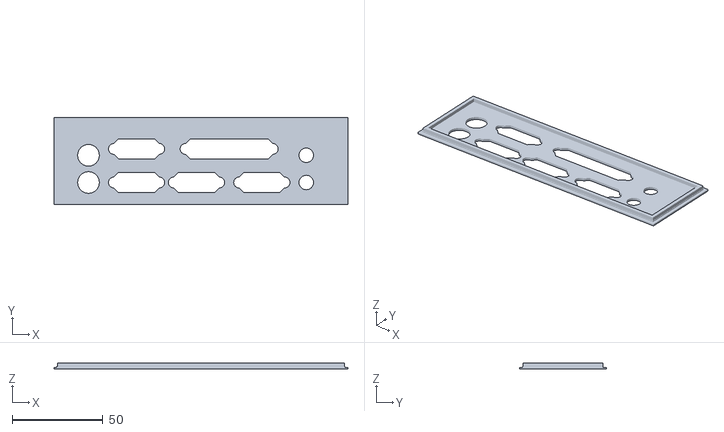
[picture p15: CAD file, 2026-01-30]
hw/raven/a1/raven_ioshield_new.stl
162.0 x 48.0 x 3.50

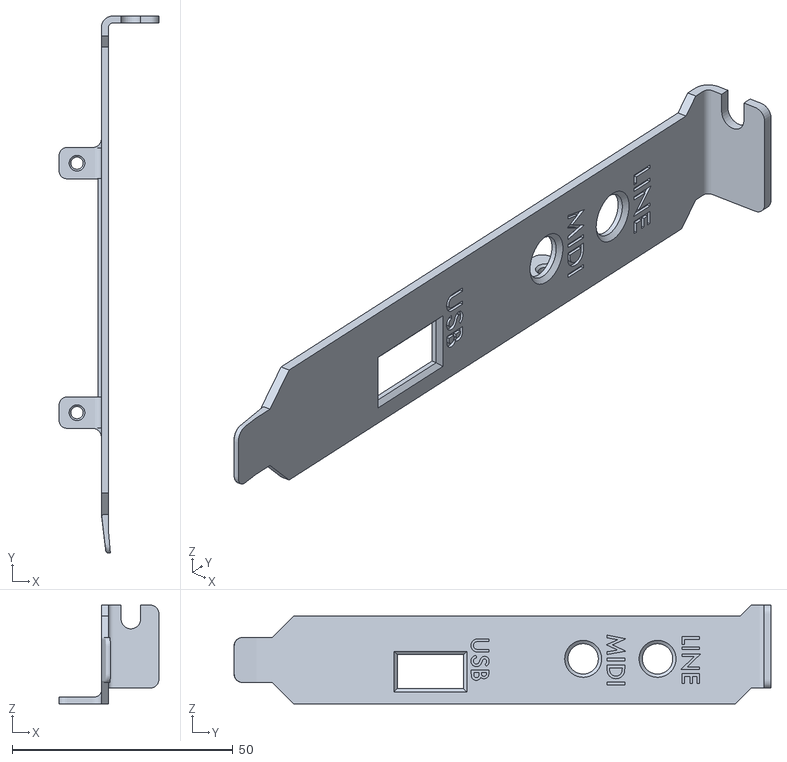
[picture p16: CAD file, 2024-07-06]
sw/isa/drivers/picogus/hw-chipdown/bracket/picogus 2.0 3D printed bracket.stl
22.6 x 121.7 x 22.4

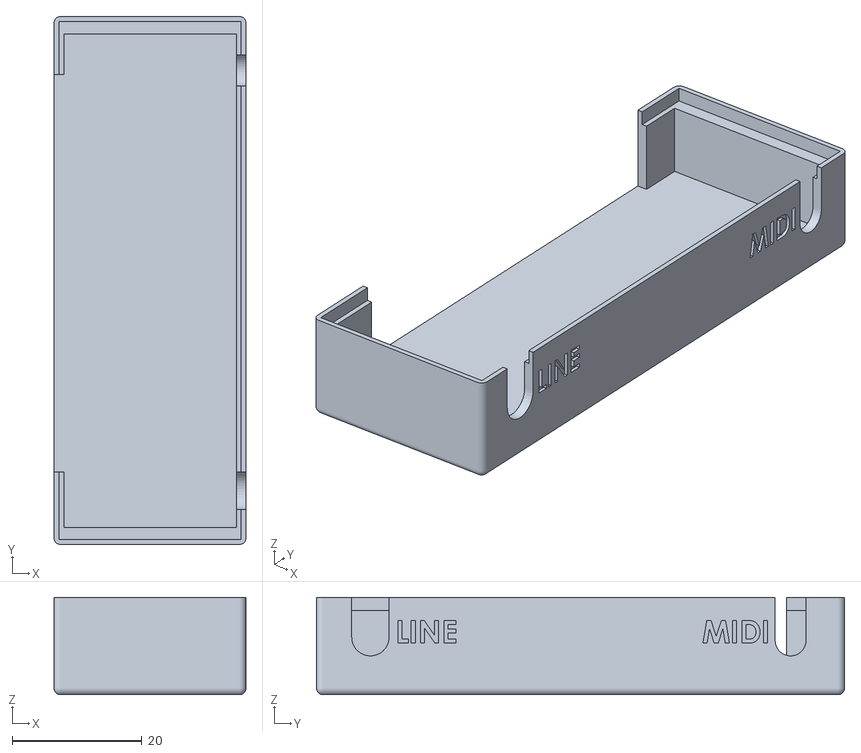
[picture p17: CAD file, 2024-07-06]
sw/isa/drivers/picogus/hw-hand386/picogus_hand_bottom_v2.STL
29.5 x 81.3 x 15.0

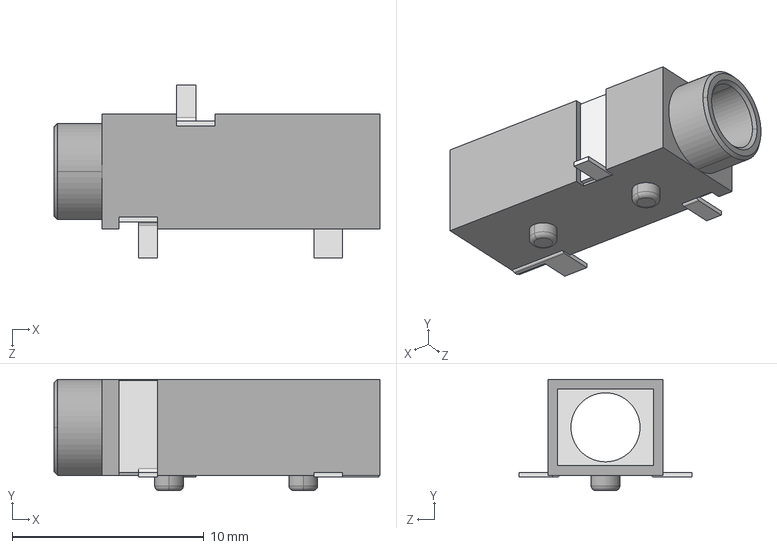
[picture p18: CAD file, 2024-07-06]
sw/isa/drivers/picogus/hw/parts/CUI_DEVICES_SJ-3523-SMT-TR.step
17.0 x 5.80 x 9.00 mm

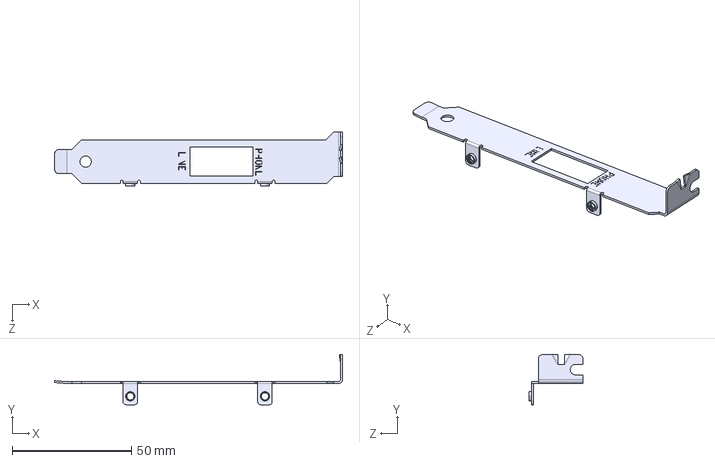
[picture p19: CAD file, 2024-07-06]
sw/isa/drivers/picogus/isa-hand386 adapter/parts/keystone-PN9202-1.STEP
120.9 x 21.2 x 22.7 mm

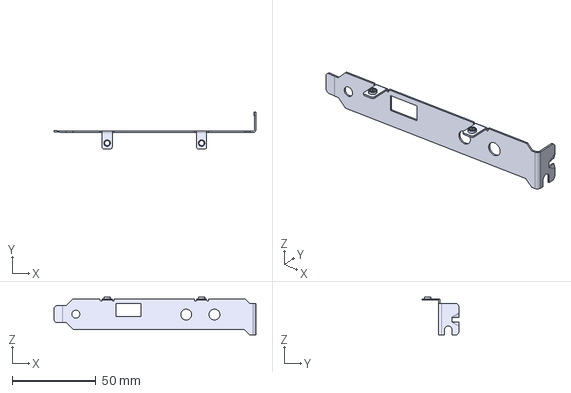
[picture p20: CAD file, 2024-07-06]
sw/isa/drivers/picogus/hw-chipdown/bracket/picogus 2.0 sheet metal bracket.step
120.9 x 22.2 x 22.7 mm

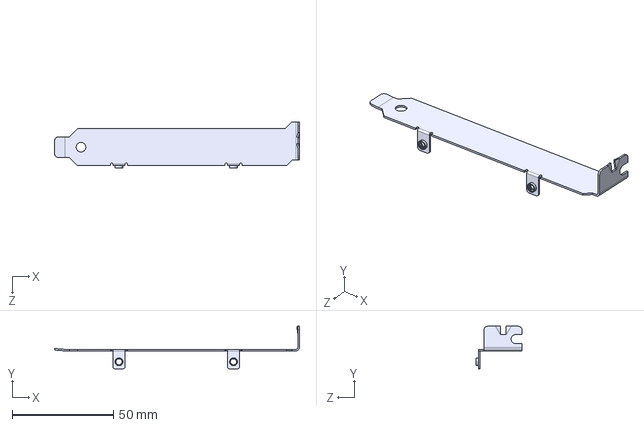
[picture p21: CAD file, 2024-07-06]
sw/isa/drivers/picogus/hw-common/parts/keystone-PN9202.STEP
120.9 x 21.2 x 22.7 mm

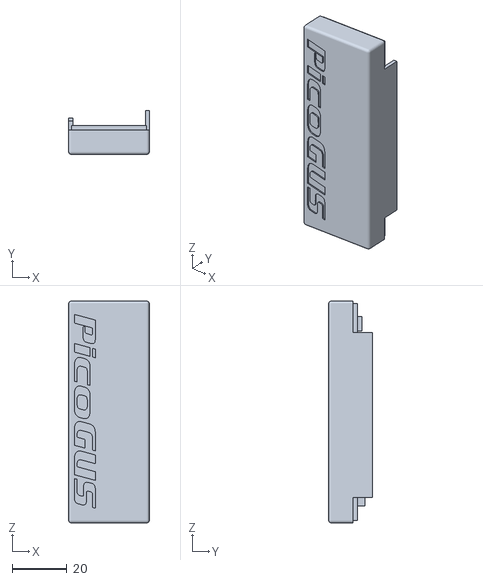
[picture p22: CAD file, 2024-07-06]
sw/isa/drivers/picogus/hw-hand386/picogus_hand_top_v2.STL
29.5 x 16.0 x 81.3

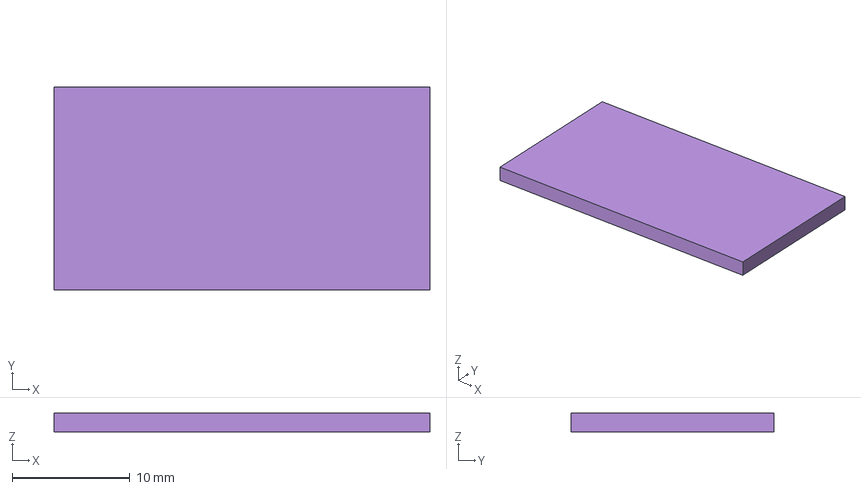
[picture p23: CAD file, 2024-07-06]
sw/isa/drivers/picogus/hw/parts/Unnamed1-Cube.step
32.0 x 17.2 x 1.60 mm

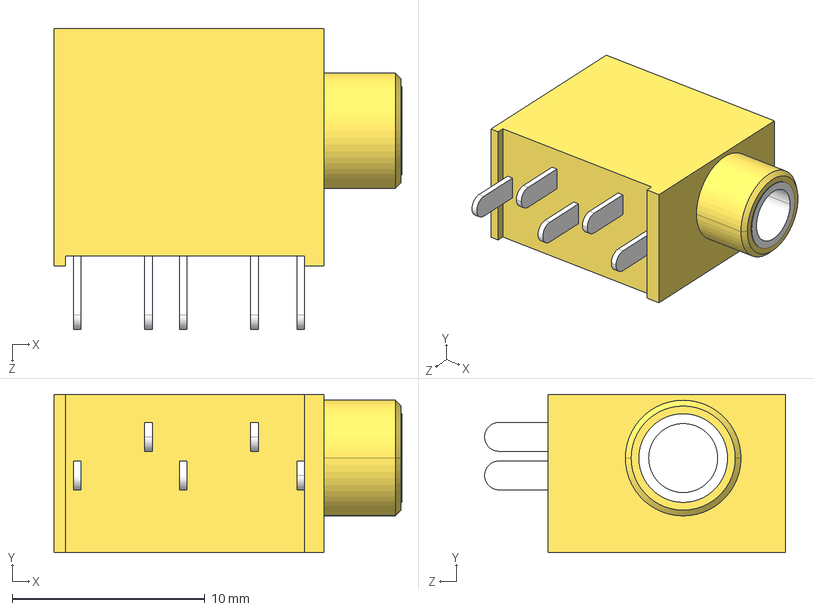
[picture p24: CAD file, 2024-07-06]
sw/isa/drivers/picogus/hw-common/parts/CUI_DEVICES_SJ1-3535NG-BE.step
18.1 x 8.20 x 15.6 mm

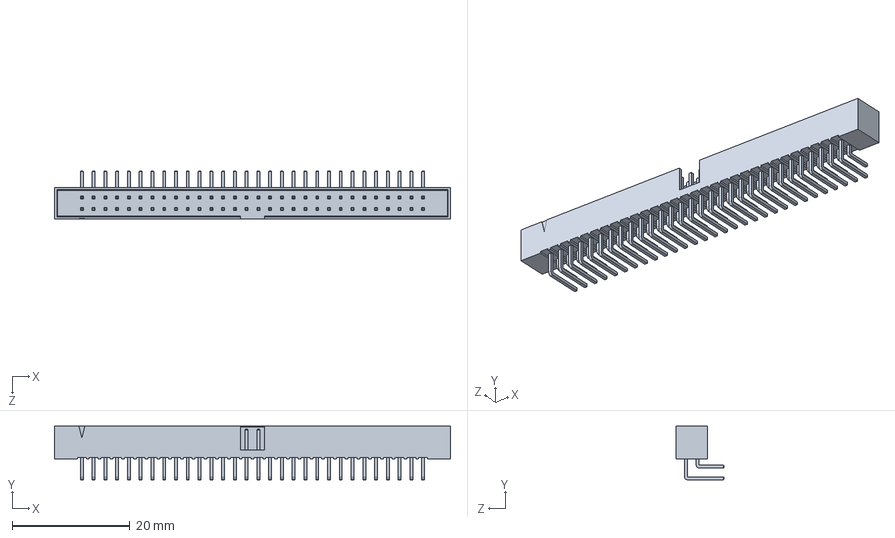
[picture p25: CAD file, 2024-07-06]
sw/isa/drivers/picogus/isa-hand386 adapter/parts/SBH21-_ _ _N-D30-RA-_ _.STEP
67.3 x 9.10 x 8.20 mm

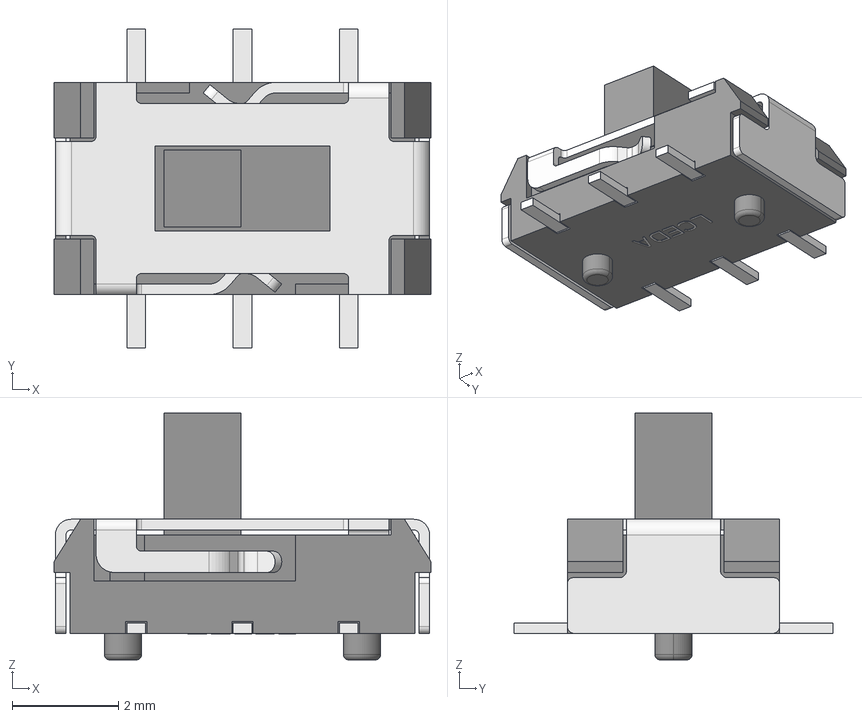
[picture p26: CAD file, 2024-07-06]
sw/isa/drivers/picogus/hw-common/parts/SWITCH_MS-22D28-G020.step
7.10 x 6.00 x 4.65 mm

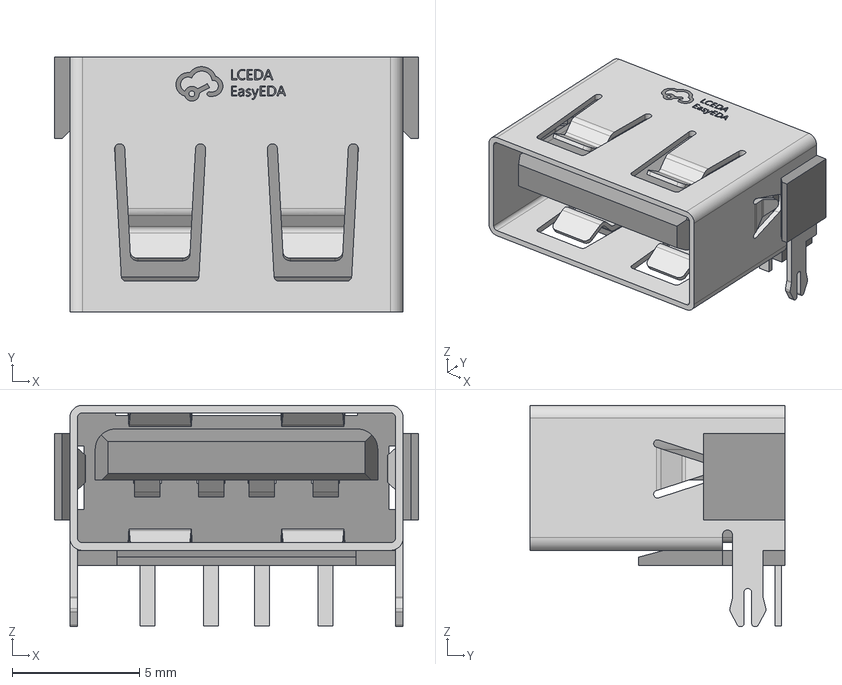
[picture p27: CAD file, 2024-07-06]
sw/isa/drivers/picogus/hw-common/parts/USB-A_AF 10.0 HC6.3.step
14.3 x 10.00 x 8.70 mm

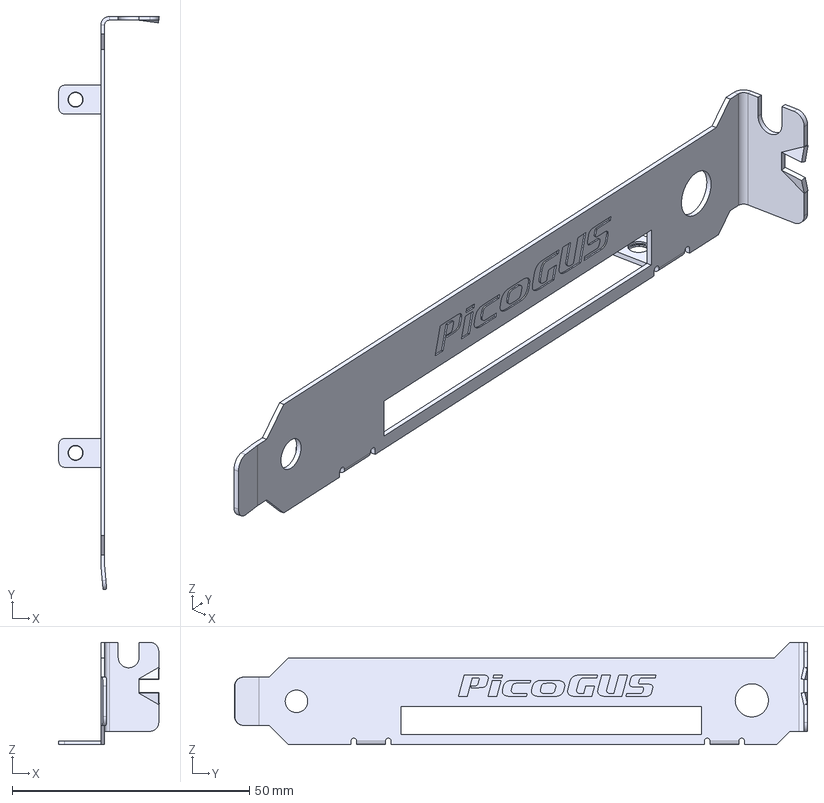
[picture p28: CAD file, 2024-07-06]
sw/isa/drivers/picogus/isa-hand386 adapter/parts/ISA adapter bracket v4.step
21.2 x 120.9 x 21.6 mm

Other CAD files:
hw/raven/a1/Raven060 IO Shield.blend
sw/isa/drivers/picogus/hw-common/parts/CUI_DEVICES_SJ1-3533NG.step
sw/isa/drivers/picogus/hw-common/parts/CUI_DEVICES_SJ1-3535NG-G.step
sw/isa/drivers/picogus/hw-common/parts/PJ-210B.step
sw/isa/drivers/picogus/hw-common/parts/RK09712_0-L20-short.step
sw/isa/drivers/picogus/hw-common/parts/RK09712_0-L20.STEP
sw/isa/drivers/picogus/hw-common/parts/RK10J12R0A0B.step
sw/isa/drivers/picogus/hw-common/parts/RK10J12R0A0B.stp
sw/isa/drivers/picogus/hw-common/parts/RK10J1_R.STEP
sw/isa/drivers/picogus/hw-common/parts/TL3305BFxxxxG.stp
sw/isa/drivers/picogus/hw-common/parts/USB-A_902-131A1011D10100.step
sw/isa/drivers/picogus/hw-common/parts/USB-microB_U254-051T-4BH83-F1S.step
sw/isa/drivers/picogus/hw-common/parts/keystone-9202-maxconnector.step
sw/isa/drivers/picogus/isa-hand386 adapter/parts/RK10J12R0A0B.stp

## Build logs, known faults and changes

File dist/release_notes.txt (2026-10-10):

Raven 68060
Hardware and software binary release

xxxxxx:

  rom:
	- rvbios bootlogo grayscale insted of 1bpp mono
	- added dsp info to bios setup screen
	- added fan controls to bios setup screen
	- added rgb controls to bios setup screen (Rev.A2)
	- general ISA mem access performance increase
	- motorola fpsp fixes

  rvnova:
    - general ISA mem access performance increase

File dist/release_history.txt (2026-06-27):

Raven 68060
Hardware and software binary release

260406:
  rom (bios)
    faster vgabios x86emu
    export function for moving 060sp to any vector table
    d and a commands can now take register as parameter
  rom (emutos)
    updated to #f96a524 @ 20260331
    correct cache status when menudesk.inf is not present
    removed cache menu item (as Falcon, use control panel if needed)
  rvbios:
    move 060sp to TOS vectors (fix Mint 1.16.0 crash)
    support older CT60 xbios calls (fix xcontrol for CT60 crash)
    support puntaes xbios call (MagiC poweroff)
  isa_bios:
    more flexible device config options (isa_bios.inf)
    more useful device info log (isa_bios.log)
  rvsound:
    fix cache related crash
    (update entire folder, including drivers)
  software:
    added xcontrol.acc (CT60 patched version)
    added general.cpx  (CT60 patched version)
    added gsxbmixer

20260308:
  rvnova:   (svga) fixed broken pitch values in .bib file
  software: (uiptool) support 16bit transfer
  software: (castaway) support physical floppy drive

20260302:
  rvnova:   option to scale dac value
  rvnova:   fixed potential bug with blitter fillpattern address

20260225:
  rom:      fixed boot font issue
  rvnova:   more VDI acceleration for Cirrus + WDC

20260216:
  rvnova:   tseng driver fixes

20260215:
  rvnova:   wip tseng driver
  
20260215:
  rvnova:   added settings file
  rvbios:   updated nova settings panel

20260213:
  rom:      updated EmuTOS (#65a71f3 @ 20260202)
  rvnova:   better 1280x720x8bpp quality on Cirrus

20260209:
  rvnova:   1280x720x8bpp for Cirrus and WDC

20260208:
  rvnova:   WD90C33 blitter support
  
20260201:
  software: added ISA floppy disk driver

20260107:
  rom:      fixed crash related to copyback cache

20260106:
  firmware: (iksi) support Atari disk interupt

20251229:
  rom:      default to 8x8 font during boot
  rvnova:   default to 8x8 font during boot
  rvnova:   ET4000/MACH32/MACH64 drivers patched for 68060
  xboot:    patched for 68060
  isa_bios: improved details in logfile
  software: include standalone emucon2.tos in tools folder
  
20251226:
  rom:      updated EmuTOS (#24dff9a @ 20251225)
  rom:      enabled EmuTOS SCSIDRV
  rom:      include uip.tos in romdisk
  software: fixed potential stack bug in all purec based programs
  rvsnd:    fixed missing PSG flag in SND cookie
  
20251215:
  rom:      map entire 16MB isa-ram rather than only first 4MB

20251214:
  rom:      support EmuTOS Shutdown feature (when ckbd is present)
  rom:      removed nova driver specific pmmu mapping
  rvnova:   add nova driver specific pmmu mapping
  isa_bios: support isa-interrupt callbacks

20251208:
  rom:      disable store/load bypass on rev1+5 cpu
  rom:      moved motorola sp060 into bootrom
  rom:      emutos panic message now outputs on raven serial
  rvbios:   moved motorola sp060 into bootrom
  rvbios:   settime/gettime implemention for rtc
  software: rvsnd added (work in progress)
  firmware: (nessi) included version 251029

20251007:
  rom:      ensure caches enabled during vgabios calls
  rvnova:   remove temporary vgabios workarounds

20251004:
  rom:      improved generic vga compatibility
  rvnova:   improved generic vga compatibility
  rvnova:   Cirrus Logic GD5434 driver
  rvbios:   bootscreen
  software: PicoGUS driver updated

20250914:
  rvbios:   prevent showing boot screen twice under MagiC
  software: added 3rd party fpupatch
  software: added 3rd party xboot

20250827:
  rom:      updated to EmuTOS 1.4
  rom:      x86 emulation bugfix
  rvnova:   Cirrus Logic GD54xx driver (blitter support)
  rvnova:   WDC90C31 driver (blitter support)
  rvnova:   OAK driver

20250808:
  rom:      layout and size optimization
  rom:      wip configspace for system settings
  firmware: (simm programmer) support for rom configspace
  rvbios:   get chipset version from bootrom
  rvnova:   generic vga driver

20250718
  rom:      improved IDE speed (4.8 -> 7.9 MB/s)
  firmware: (nessi) improved cf-card compatibility

20250627
  firmware: (nessi) ISA fix: 16-color vga modes now work

20250626
  rom:      support for ide byteswap adapter
  rom:      updated romdisk software
  rom:      create ramdisk when no hdd partition exist
  software: added ymodem serial transfer program

20250621
  rvbios:   _MCH cookie for Raven is now 0x00070000

20250620
  rom:      ckbd support
  rom:      eiffel key-repeat fix
  rom:      autorun srec programs after upload
  firmware: (ckbd) added ckbd firmware binary
  firmware: (nessi) reversed order of ram slots
  rvbios:   ET4000/W32i memory interleave setting
  rvnova:   ET4000/W32i memory interleave support

20250321
  rom:      fixed software reset from tos/mint
  firmware: (eiffel) default to scancode set 2

20250317
  drivers:  added US-ANSI keyboard table for Eiffel

20250307
  monitor:  in-system rom flashing
  software: added rom flash utility

20250215
  software: added uiptools for NE2000 ISA cards

20250208
  rom:      hi-speed serial now usable in TOS as bios device 7
  tools:    added serial.cpx for configurating serial ports

20250123
  drivers:  Aims FM-Radio ISA card

20250119
  drivers:  OPL midi driver

20250107
  rom:      ROM disk support for utilities

20241230
  rom:      fixed bug in cookie set command
  devel:    small isa library can work even without ISA_BIOS
            to a limited degree and on regonised platforms

20241229
  drivers:  MPU401 driver

20241226
  rom:      added tos cookie commands
  rom:      monitor input/output redirection
  software: added raven/mon.tos (requires rom >= 20241226)
  software: added 3rdparty autoexec
  software: added 3rdparty setenv
  software: added 3rdparty setflags
  software: moved 3rdparty autosort into own folder

20241225
  rvbios:   use standard Atari colors
  rvbios:   reset after certain changes
  rvbios:   cpu page memory settings
  rvbios:   check rom version on startup
  rom:      faster vga init
  rvnova:   fixed memory overwrite
  isa_bios: built with purec
  ultrinit: built with purec

20241216
  Updated pgusinit from latest v2.2.0 sources

20241215
  Improved x86 bios emulation, S3 86C801 card now works.

20241210
  Basic mono vga mode is now intiialized by
  the Raven bios instead of EmuTOS.
  Should work on all/most types of VGA cards.

20241202
  software: added FPU emulator 'fpemu.prg'
  software: added ISA_BIOS and example config file
  rvbios:   fixed GUI glitches on nvram page
  rvbios:   fixed SP060 issue
  monitor:  config system and storing settings to nvram

20241124
  monitor: selftest is now a loadable s19 program

20241120
  nova: added 1280x720 resolutions where possible
  nova: added  320x200 resolutions where possible

20241115
 software: first pass of software support package
 monitor: COM1 default to 115200 baud
 monitor: new command 'a' for disassembly
 
20241110

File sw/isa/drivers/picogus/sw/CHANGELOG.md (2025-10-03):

# v3.2.1

## Fixes/improvements

### pgusinit

Fixes several regressions in pgusinit:

- Fixes issue where port settings are parsed as decimal, not hex (fixes /mpuport, /gusport, /cdport, etc.)
- Fixes /sbport and /gusport commands not passing through option
- Fixes /wifistatus command
- Restores /defaults command

### General

- Gives VREG a bit more time to settle at bootup/reset. Should improve stability on initial poweron, after changing modes, or flashing firmware.

# v3.2.0

## Fixes/improvements

### General

- Settings saved in flash with `pgusinit /save` are now preserved when upgrading to a firmware version that introduces new settings
- Volume control is now available for all sources. For example, in SB mode, the SB DSP, OPL2, and CD-ROM audio volumes can be independently controlled. Thanks to [Daniel Arnold (Delphius)](https://github.com/RetroLoom) for contributing this!
- DualShock 4 gamepad support has been fixed

### SB mode

Sound Blaster playback has been almost completely rewritten, removing a major bottleneck and freeing up way more CPU time.

- Crashing on titles with simultaneous SB DSP & OPL2 fixed
- High-quality assembly optimized FIR polyphase resampler for much better sounding OPL2 output. Huge thanks to [korneliuszo](https://github.com/korneliuszo/) for contributing this and other optimizations!
- Direct DAC mode is back after being dropped in firmware v3.0.0
- Too-slow MPU-401 output in SB mode fixed (main symptom was long delay until music starts in Sierra titles)
- CD-ROM speed now faster in SB mode - improved from 2x to 3x

### pgusinit

pgusinit has been almost completely refactored, thanks again to [Daniel Arnold (Delphius)](https://github.com/RetroLoom). It not only helps future maintainability but brings new quality of life features:

- Long output like CD image listing and extended help text now pauses instead of scrolling off the screen
- Progress bar when flashing firmware instead of filling the screen with dots
- More helpful text if there are missing arguments
- Values can be set back to their default values with a `default` argument. Example: `pgusinit /cdport default`
- Added support for volume control via commands like /sbvol, /cdvol, etc.

# v3.1.0

## Fixes

### CD-ROM emulation

Many fixes/improvements to CD image handling:

- Add ability to load image by name
- Fix memory leak when changing images (file handle not freed, causing crash after switching images several times)
- Less memory usage all over
- Longer max file length limit (127 chars)
- Better errors when USB not present
- Fix polling of CD status register when listing images
- Many weird edge cases with image loading state fixed

# v3.0.1

## Fixes

### SB and USB modes

Fixes MPU-401 output in SB and USB modes. It was broken by the introduction of CD-ROM emulation in SB mode and it never actually worked in USB mode!

# v3.0.0

## New features/changes

### CD-ROM emulation

PicoGUS now supports CD-ROM emulation (in other words, PicoGUS is now an ODE)! It emulates a [Panasonic/MKE interface and drive](https://en.wikipedia.org/wiki/Panasonic_CD_interface) and supports CD images in ISO or BIN/CUE stored on a USB drive plugged into the USB port on the PicoGUS. CD-ROM emulation has been tested in DOS and Windows 9x and CD audio playback is fully supported.

CD-ROM emulation is available in Sound Blaster and USB modes. Sound Blaster mode really pushes the limit of the RP2040: it mixes CD audio, SB DSP, and OPL sound while simultaneously supporting CD data and MPU-401 emulation. The emulated drive is approximately 2x speed in SB mode and 3x-4x speed in USB mode. Disc images can be swapped on the fly with pgusinit, and multi-disc games are supported by removing and reinserting the USB drive to advance the current disc image.

For more information and a guide on how to use CD-ROM emulation on PicoGUS with recommended drivers, known limitations, etc., visit the new [CD-ROM emulation wiki page](https://github.com/polpo/picogus/wiki/CD%E2%80%90ROM-Emulation).

Massive thanks to [Kevin Moonlight (yyzkevin)](https://github.com/yyzkevin) for reverse engineering the Panasonic/MKE interface and contributing the bulk of the underlying code for this emulation.

Also major thanks to [rppicomidi](https://github.com/rppicomidi) for greatly improving mass storage speed for the RP2040 in TinyUSB and [Artem Vasilev (wbcbz7)](https://github.com/wbcbz7) for additional fixes and rebasing on a more recent state of the repository. Without their work, USB mass storage would not be nearly fast enough to support CD-ROM emulation on the RP2040. These improvements are still not merged into the upstream project, so here's hoping that can be completed.

And thanks to all who tested this firmware before release to surface bugs and edge cases I wouldn't have been able to find myself. Cue sheets are the wild west of formats!

### Tandy/CMS modes combined into new PSG (programmable sound generator) mode

To reduce firmware size and prepare for future support for other [PSG sound chips](https://en.wikipedia.org/wiki/Programmable_sound_generator) (here's a hint, it's the [AY-3](https://en.wikipedia.org/wiki/General_Instrument_AY-3-8910) as used on the [Mindscape Music Board](https://www.youtube.com/watch?v=Eeo4INoGyRY)), Tandy and CMS modes have been combined into a single PSG mode. It can be selected with `pgusinit /mode psg`, but the old `/mode tandy` and `/mode cms` switches still work for backwards compatibility.

## Fixes

### pgusinit

When pgusinit couldn't detect a PicoGUS, it would erroneously continue trying to configure the card. This would result in a strange firmware version mismatch error. This has now been fixed.

## Known issues

### Sound Blaster mode

Due to the addition of CD-ROM emulation to SB mode, SB DSP audio now runs through a FIFO. This may result in some playback issues that are being worked on. Also "Direct DAC" mode (mostly used by older titles) is not currently supported.

### General

Due to the addition of new settings, any saved settings done with `/pgusinit save` on previous firmware versions will be reset to defaults when upgrading to firmware v3.0.0.

# v2.2.0

## New features/changes

### NE2000 emulation/WiFi

*Please note* that this mode is not supported on PicoGUS 2.0! It needs a v1.1, v1.2, or Femto version of the PicoGUS that takes a Raspberry Pi Pico and requires a Pico W! I made this mode mainly just so I could use WiFi on my Pocket386 with a Femto card plugged into it. At least for now, NE2K mode comes in its own separate firmware file (`pg-ne2k.uf2`) and no other emulation is enabled when this firmware is loaded. Due to this limitation and the fact that the PCB design of the PicoGUS 1.x is not ideal for WiFI reception, consider this mode just a bit of a nice bonus. Config options have been added to pgusinit for NE2000 and WiFi SSID/password settings.

## Fixes

### Sound Blaster 2.0 emulation

* Fixes detection in Windows 9x, allowing SB mode to work in Windows 9x. Thanks to Ian Hanschen (@ianhan) for contributing the fix.
* Fixes detection in Tyrian and Dig-It! Thanks again to Ian Hanschen for the fix.
* Fixes detection in STMIK-based demos (Mental Surgery by Future Crew, SX by Substance, Min Monitor Briner by Syntax Error, probably others)

### GUS emulation

* Fixes intelligent mode MIDI buffer overrun and slow MIDI output in GUS mode. Usually showed up as an "Exc. Checksum Error" on the MT-32 screen. 

### General

* Fixes issue with setting port numbers less than 0x100 or ending in 00. This fixes common port settings like 0c0 for Tandy or 0x300 for NE2000
* Refactors timers to be less jittery; shouldn't be noticeable in practice but may fix some GUS emulation edge cases.

# v2.1.0

## New features/changes

### MPU-401 simultaneous with all modes

MPU-401 emulation is now available in all modes. This can enable simultaneous digital sound effects in SB or GUS modes with MIDI output. If you have another MPU-401 card in the system, to prevent conflicts this can be disabled or moved to a different port with the `/mpuport` option to pgusinit.

The original MPU mode is still available for titles that require MPU interrupts (titles on [this list](https://github.com/bjt42/softmpu/wiki/Compatible-Intelligent-Mode-Games) marked with a 1 require MPU interrupts).

# v2.0.0

## New features/changes

### Serial mouse emulation

Now you can use a USB mouse as a serial mouse on your PC. Features a configurable report rate defaulting to 60Hz so the emulated serial mouse is much smoother and more responsive than a real serial mouse. Also supports configurable sensitivity and protocol support, including Microsoft, Logitech, Mouse Systems, and Intellimouse with wheel support. Note that being a serial port, this does use an IRQ so the IRQ jumper on the PicoGUS must be set to IRQ 4 or 3 depending on which serial port is configured, or use a mouse driver like ctmouse that can use a custom IRQ. Serial mouse can be emulated simultaneously with sound card modes that do not require IRQ such as AdLib, CMS, and Tandy (MPU coming in future firmware for games that don't need MPU IRQ).

Thanks to [Artem Vasilev (wbcbz7)](https://github.com/wbcbz7) for implementing mouse and 8250 UART emulation.

### "Multifw" - all modes in one firmware

All emulation modes (GUS, SB, MPU, etc.) are now contained within the same firmware. This means switching between modes is much faster than before, taking 1-2 seconds on average. Switching also no longer involves writing new firmware to the card's flash, alleviating flash wear concerns (each sector on the flash is rated for at least 100,000 cycles, so there wasn't not much to worry about, but it's still nice for peace of mind).

Many thanks to [Jeroen Taverne](https://github.com/jeroentaverne) for developing [the original proof of concept](https://github.com/jeroentaverne/pico_multi_firmware) and [smymm](https://github.com/smymm) for implementing it within the PicoGUS codebase.

### Card settings can now be saved in flash

Once you're satisfied with your PicoGUS's settings, they can now be saved in the card's flash. Saved settings persist across reboots or power cycle without needing to run pgusinit each boot.

For example, when using serial mouse emulation, some BIOSes like MRBIOS need to see the emulated serial port right at boot. Also as a bonus if you want to use emulation modes outside of DOS, settings will apply in those other operating systems. Want to use GUS in OS/2 or Linux, or serial mouse when setting up NeXTStep? This will help!

### Overhaul of pgusinit

To support the above new features, adding more options to pgusinit meant I ran out of single letters for its various switches that make mnemonic sense. I've moved to longer yet hopefully still fast to type names for each of the switches.

Also, each pgusinit option now persists between invocations of pgusinit. Previously, most but not all options had to be given in the same invocation of pgusinit. Each option that would enable a feature (e.g. joystick support) has been turned into an on/off option so it can be turned off as well as on.

Running pgusinit by itself will now show all the currently applied settings for the current firmware mode.

See the [pgusinit README](https://github.com/polpo/picogus/blob/v2.0.0/pgusinit/README.md) for more details on running pgusinit.

## Fixes

### Sound Blaster 2.0:

* Added speaker on/off commands
* Greatly increased quality of output in "Direct DAC" mode

### OPL2 emulation

* Fixed "missing notes" issue, most commonly heard in Prince of Persia. Thank you to [TerryFi](https://github.com/TerryFi) for discovering the issue and coming up with a preliminary fix, then incorporating the final fix from the upstream emu8950 repository.

# v1.2.0

## New features/fixes

### Sound Blaster 2.0 emulation:

The AdLib mode (`pg-adlib.uf2`) has been replaced with a _new_ Sound Blaster 2.0 mode (`pg-sb.uf2`)! Code to emulate the Sound Blaster DSP was contributed by [Kevin Moonlight](https://github.com/yyzkevin) - huge thanks to him.

* Sound Blaster 2.0 DSP support is pretty well tested but you may run into issues. Please consult the [Compatibility List](https://github.com/polpo/picogus/wiki/Compatibility-list) for titles with known issues, and feel free to [file an issue on GitHub](https://github.com/polpo/picogus/issues/new) to report any problems.
* AdLib/OPL2 emulation has been improved, fixing issues with missing/wrong notes.
* The SB base port can be set with pgusinit with the `/p` option, and the OPL/AdLib base port with the new `/o` option.
* Some older titles supporting AdLib are "speed sensitive" and have weird playback on fast systems (even with a genuine OPL2/OPL3). A new `/w` option in pgusinit can work around these issues in most circumstances.

### MPU-401 emulation:

* Fixes an issue reported by zuldan on Vogons where running pgusinit in MPU-401 mode wouldn't work on certain systems. Fixed by initing the MPU-401 and sending the reset MIDI data asynchronously, preventing IOCHRDY from being held low for too long.
* Sysex delay handled without busy wait. Shouldn't have much effect presently, but may allow MPU-401 to be emulated simultaneously with other modes in the future.

### General:

* Allows the volume of the wavetable header to be set with the `/v` option in pgusinit in all modes. This is useful if you want to use the wavetable header to mix in other external audio sources like a CD-ROM drive (connection guide coming to the Wiki).

# v1.1.0

## New features/fixes

### GUS emulation:
* Works around a hardware bug in the PCM510xA DAC that results in ~10% of chips to be silent at 22.05kHz sampling rate. This is the rate produced by the GUS at 28 channels, and is used by Doom and the demo "Dope". The workaround is to run the DAC at 44.1kHz, linearly interpolating the 22.05kHz output.
* Increased fractional precision of wave addresses to 10 bits from 9.
* New EXPERIMENTAL fixed 44.1kHz output. Normally the GF1 varies its output sample rate from 44.1kHz at 14 voices to 19.2kHz at 32 voices. Using this option enables 44.1kHz output for all numbers of voices, similar to the Interwave. This gives much higher quality output when playing lots of channels.  This will result in stuttering in most games that use streaming DMA for sound effects like Doom, hence it is EXPERIMENTAL. It can be enabled with the `/4` switch in pgusinit. Thanks to [wbcbz7](https://github.com/wbcbz7) for contributing this support along with the increased wave address precision.
* Known issue: Impulse Tracker constantly re-inits the GUS to get the best sampling rate and if it passes through 28 channels rapidly, audio artifacts can be heard. To work around, run PicoGUS in fixed 44.1kHz output mode.

### pgusinit
* New `/4` switch when in GUS mode to enable fixed 44.1kHz output.

# v1.0.2

## New features/fixes

### General:
* New bus timing, fixes compatibility with IBM PC/AT 5170.
* Faster IOCHRDY timing to improve compatibility and spend less time on ISA bus.
* Less aggressive overclock and different startup timing to improve stability on reset.
* Added support for Xbox 360 wireless adapter dongle.

# v1.0.1

As always immediately after I do a big release, a significant bugfix comes soon after! Don't forget to look at the notes for firmware v1.0.0.

### General:
* Increase stability upon startup on PicoGUS 2.0 boards.

# v1.0.0

The PicoGUS 2.0 hardware brings v1.0.0 of the PicoGUS firmware! This firmware runs on _all_ released revisions of the PicoGUS hardware: 1.1, 1.1.1, 1.2, and 2.0.

## New features/fixes

### General:
* Support for PicoGUS 2.0 hardware and its software-controlled wavetable header volume (`/v xxx` pgusinit option).
* A preview of game port joystick emulation using USB joysticks is included in all sound card emulation modes, enabled with the `/j` pgusinit option. There is also a "joystick exclusive" firmware (`pg-joyex.uf2`) for when you only want to use a USB joystick and not emluate any sound cards. This is considered a preview because only a few USB joystick types are supported: wired Xbox 360 (and third party clone) controllers and the Sony DualShock 4. More joysticks will be supported in the future! See the [Compatibility List](https://github.com/polpo/picogus/wiki/Compatibility-list) wiki page for more information about this feature.
* Much more reliable firmware flashing from DOS. The previous method abused IOCHRDY to hold the ISA bus far longer than usual, and some chipsets would release the bus before certain flash operations were complete.
* A more robust startup sequence to improve firmware boot stability. All firmwares have the same LED sequence when starting so you will know when the firmware is ready.
* Compatibility with slower PSRAM chips that are rated for only 104MHz, such as the Vilsion Tech VTI7064MSME and ISSI IS66WVS1M8BLL-104NLI. This widens available options for those DIYing their own PicoGUS boards.

### pgusinit

pgusinit has been updated to version v2.0.0, featuring:

* Updates to pgusinit to support the new firmware flashing protocol, as well as support upgrading from v0.x.x firmware to v1.x.x firmware. If you have a v0.x.x version of firmware running on your PicoGUS, you can upgrade to v1.0.0 with the latest version of pgusinit included with the firmware release package.
* Detects the current card mode and only shows options applicable to that mode when using `/?` to ask for help.

### Adlib emulation:
* Fixes an issue where some software would incorrectly detect PicoGUS as an OPL3 instead of an OPL2.

### MPU-401 emulation:
* Sysex delay can be enabled with the `/s` pgusinit option. This will prevent buffer overflows on older MPU-401 revisions.
* Fake all-notes-off for the Roland RA-50 can be enabled with the `/n` pgusinit option.
* Fixes song change issue in Frederik Pohl's Gateway. PicoGUS will detect when Gateway is running and enable a hack in how the version and ack are returned. Run pgusinit to restore default operation after you're done playing Gateway.
* Running pgusinit will silence any stuck notes if a program exits unceremoniously.

# v0.7.0

## _Note:_ Please use the version of pgusinit.exe that comes with this firmware!

Version v0.7.0 of the firmware has a much smaller default GUS audio buffer size of 4 samples, thanks to the higher RP2040 clock speed. If you run an older version of pgusinit.exe, it will set the buffer size to 16 samples, negating many of the improvements that this version brings for GUS emulation.

## Release notes:

### General:
* Runs the RP2040 at 400MHz. This allows for faster reaction to ISA events, holding IOCHRDY low for shorter time periods. This allows better performance for other ISA cards and may help run on faster ISA bus speeds.
* Fixes from @SuperIlu for pgusinit to fix usage message and improve command line parsing.

### GUS emulation:
* Higher clock speed enables much shorter interval before checking for IRQs. This should improve compatibility in titles that use IRQs and DMA.
* Fixes for Hand386 and other M6117D-based systems.
* Changes to pgusinit to default to the new GUS buffer size of 4 samples, and support setting the buffer size below 8 samples. Please use the new version of pgusinit that ships with this firmware!

### Tandy emulation:
* New emulation core contributed by [Aaron Giles](https://aarongiles.com/). This is the same core used in [DREAMM](https://aarongiles.com/dreamm/) and should result in better accuracy across all titles. or example, sound effects such as crickets chirping and meteor crash in Maniac Mansion and snoring in Zak McKracken sound much better.

### CMS emulation:
* New emulation core contributed by [Aaron Giles](https://aarongiles.com/). This is the same core used in [DREAMM](https://aarongiles.com/dreamm/) and should result in better accuracy across all titles.
* Fixes issue with pitch of CMS sound being too high.

### MPU-401 emulation:
* Misc optimizations might improve compatibility in some titles.

For known issues, please see the [Compatibility List](https://github.com/polpo/picogus/wiki/Compatibility-list) wiki page.

# v0.6.1

Another bugfix release! This release fixes a bug introduced in firmware [v0.5.0](https://github.com/polpo/picogus/releases/tag/v0.5.0) that caused Descent to freeze on the `Loading...` indicator when running setup and starting the game. 

### GUS emulation:
* Fixes freeze when starting Descent. This patch release uses a smaller/simpler 4-byte DMA buffer that solves the freeze with Descent while also hopefully still preventing stuttering in Doom introduced by level changes (the reason for the DMA buffer in the first place).

For known issues, please see the [Compatibility List](https://github.com/polpo/picogus/wiki/Compatibility-list) wiki page.

# v0.6.0

### CMS emulation:
* New emulation mode: **CMS/Game Blaster**.

For known issues, please see the [Compatibility List](https://github.com/polpo/picogus/wiki/Compatibility-list) wiki page.

# v0.5.1

Bugfix release! All of the new features of [v0.5.0](https://github.com/polpo/picogus/releases/tag/v0.5.0) plus the following fixes:

### Tandy emulation:

* Fixed reporting of base port when running pgusinit when on Tandy firmware
* Fixed firmware flashing from DOS when on Tandy firmware

# v0.5.0

### General:
* More reliable firmware flashing from pgusinit by clocking down the Pico and disabling interrupts. Many thanks to JazeFox at Vogons for debugging this issue and suggesting a fix.

### Tandy emulation:
* New emulation mode: **Tandy 3-Voice**. This emulation is on port 2C0h by default, to avoid conflicts or masked IO on the default Tandy port of 0C0h in non-Tandy systems. This is the same alternate port that [Matze79's "TNDY" card](https://www.vogons.org/viewtopic.php?f=62&t=54249) can use. Use the [TNDY driver program](https://github.com/JKnipperts/TNDY) to redirect port 0C0h to 2C0h. Also [many games need to be patched](https://www.vogons.org/viewtopic.php?t=77679) to allow for Tandy sound on non-Tandy systems with CGA, EGA, or VGA graphics. Note that this mode has not received much optimization, so accuracy and compatibility can be improved.

### GUS emulation:
* Resets DMA status bit to 0 on completion of DMA handler. Fixes some Demoscene titles.
* Buffers uploaded DMA samples instead of writing 1 byte at a time. Currently this buffer is 8 bytes, and may be configurable in future releases. Should help stuttering/slowdown issues in games that use streaming DMA audio like Doom.
* Bails out on sound rendering when sample rate changes. This should eliminate any "warbling" sounds when Impulse Tracker resets the channel count on the fly.
* Uses the [RP2040 hardware interpolation](https://people.ece.cornell.edu/land/courses/ece4760/RP2040/C_SDK_interpolator/index_interpolator.html) unit to interpolate samples and clamp output to 16 bits.

For known issues, please see the [Compatibility List](https://github.com/polpo/picogus/wiki/Compatibility-list) wiki page.

# v0.4.0

### General:
* New version (v1.0.1) of pgusinit.exe - DMA interval is in µs, not ms

### GUS emulation:
* Refactored DMA transfer completion handler: this results in much higher compatibility with titles that use streaming DMA. Overriding the DMA transfer interval is not necessary in most circumstances now.
  * Fixes games: Quake, Doom (and Doom engine games), Duke3D, Descent, Hocus Pocus (partially); Demo: Inside
* Fixed bug where DMA control register was not properly reset between transfers. Fixes garbage samples when uploading mixed 16 & 8 bit samples.
  * Fixes music players/trackers: Open Cubic Player (with `gusFastUpload=on`), Fast Tracker 2

# v0.3.0

### General:
* Firmware can now be programmed from DOS (requires FW v0.3.0 or above - upgrading from previous versions must be done by USB)
   * Emulation mode can be changed "on the fly" by uploading different firmwares
* New version (v1.0.0) of pgusinit.exe - Firmware versions v0.3.0+ require this new version of pgusinit.exe!

### GUS emulation:
* Major DMA improvements!
  * DMA PIO state machine rewrite to solve sample glitches (fixes Star Control II)
  * Asynchronous writing to PSRAM of DMAed samples (fixes Doom)
  * Smarter sample cache (fixes Doom)
  * Adjustable DMA interval (fixes Doom)
* One firmware for all ports - base port is now configured with `ULTRASND` environment variable and pgusinit.exe

### MPU-401 emulation:
* Intelligent mode emulation is now working in all but a few titles
* Base port now configured with pgusinit.exe (defaults to 330)

### AdLib emulation:
* Base port now configured with pgusinit.exe (defaults to 388) 

# v0.2.0

* Solved a regression where lots of channels playing 16-bit samples would cause audio stuttering (example: the demo Aeon Drift by Disaster Area). Added a super simple sample pair buffer per channel to solve this.
* Super-unstable DMA support preview. Count on it to fail, but feel free to celebrate when it works! 😅
* Fixed a small bug in pgusinit.exe that didn't set the audio buffer size to 16 if the `/a` option was not given on the command line.
* Includes firmwares for GUS port 220, 240, and 260.
* Built with a new automatic release script.

For firmware programming instructions, see the ["Programming the Pico" part of the build guide](https://github.com/polpo/picogus/wiki/Building-your-PicoGUS#programming-the-pico).

# v0.1.0

* New release format: a ZIP file containing firmware UF2 files and PGUSINIT.EXE.
* Features all IRQ fixes shown in the [November 2022 update video](https://youtu.be/CkJvkJVRscQ) and then some – regressions introduced by those fixes have now been fixed. 😅
* New version of PicoGUSinit (PGUSINIT.EXE) to allow the audio buffer size on the PicoGUS to be configured via the `/a n` option, where `n` is the size of the buffer in samples. Some productions may still freeze, or have audio glitches, and configuring the buffer size can help. Please see the [Compatibility List](https://github.com/polpo/picogus/wiki/Compatibility-list) for the flag to use for any problematic programs.
* Preview firmware for Adlib and MPU-401 emulation.

For firmware programming instructions, see the ["Programming the Pico" part of the build guide](https://github.com/polpo/picogus/wiki/Building-your-PicoGUS#programming-the-pico).

# v0.0.1

Contents:
`picogus.uf2` - Firmware with Gravis Ultrasound emulation core, port 240
`PGUSINIT.EXE` - DOS executable to detect and initialize the PicoGUS

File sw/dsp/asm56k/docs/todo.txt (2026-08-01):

BETA TODO:
- add the path of the currently assembled file to the scan path for include directive
- There's a problem with forward declared variables and IF directive. Detect forward refference and error
- write docs
- write tests (OP_MOVEP)

--------------------------------------------------------------------------------------------------

V 1.5 TODO:
- rs and rs reset for easy structures definition
- smarter DS handling ?
- pipeline restrictions!
- check for overlaping chunks
- repeat instructions
- verify falcon dsp memory scheme. for example, if we define a chunk in internal memory warn if we're going past that, etc.
- move inlcuding of files into parser rather then lexer.
	* include code is dodgy
	* refactor file inclusion code, change variables names to be more sane, extract file inclusion code from Include_file function

- write out dependencies (something like gcc does)
- deduplication in StringBuffer (I doubt it will ever be a memory problem)
- exit after first error (switch)
- ??? make "syntax error" display tokens it failed to parse

--------------------------------------------------------------------------------------------------

DONE:
- named org sections
- org section without requiring absolute address
- option to skip uninited sections (ds/dsm only)
- export p56 as devpac/vasm source files (?)
- fixed #> integer mode
- added new test
- Fixed a division by 0 problem
- L: memory addresses are wrong! 
- IFGT, LT, GE, etc.
- don't allow code generation in L: memory
- export P56
- make sure L: memory works
- make local labels work in every context
- short IO adressing (<<) is broken ... review adressing mode code
- segmentation crash when else is encoutered without matching if
- implement DS statement
- implement DSM statement
- implement casting strings to ints
- text constants crashes the assembler
- implement "*" symbol.
- cleanup lex files too.
- implement error and msg directive
- unfold include/macro path in errors
- c-style comments are broken
- refactor grammar.y, remove embeded C code to a file(s) [almost done]
- cleanup TokenStream and MacroProxy
- add checks for macro stack overflows
- use optc to parse input args
- cleanup main.c, split it itto files [almost done]
- make sure fractional arithmetics works
- test macros some more

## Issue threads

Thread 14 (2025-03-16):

'Topaz New' and 'Wolfenstein4ever' Fonts Used by PCB Files Not Found

hunsra, 2025-03-16:
Opening the raven.kicad_pcb in KiCad 9.0 results in the following error messages:

```
5:05:21 PM: Font 'Topaz New' not found; substituting 'Verdana Bold'.
5:05:21 PM: Font 'Wolfenstein4ever' not found; substituting 'Verdana Regular'.
```
After opening, there are some visible issues with the silkscreen, notably the Raven 060 portion at the bottom right of the board.

I searched for them in the repo, but couldn't find them.  Can these fonts be included in the repo or a reference added for where to find them?

hunsra, 2025-03-16:
FYI, I downloaded and installed the 'Topaz New' font from DaFont.com and 'Wolfenstein' (not 'Wolfenstein4ever') font from fontmeme.com and then opened the raven.kicad_pcb file.  It worked without complaints, but I suspect the 'Wolfenstein4ever' font was replaced automatically with 'Wolfenstein'.  It seems to be OK, but I can't be sure.

I couldn't find a font named 'Wolfenstein4ever' anywhere I searched.  I did find an old game fan site at `http://wolfenstein4ever.de/` that has a downloadable font named 'Wolfenstein' but not 'Wolfestein4ever'.  The site is not hosted with a valid TLS certificate, so I'm not sure it its safe to use anyway.

Closed 2025-03-16.

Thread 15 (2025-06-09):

PSRAM instead of SRAM a possibility?

M1kerochip, 2025-06-09:
@agranlund Hi!

I've just got some Raven060 A1 boards coming my way, and I'm excited to get started!
I was looking though, and thought I'd found a BGA drop in replacement for the SRAM TSSOP IC.

https://lcsc.com/product-detail/SRAM_Infineon-Cypress-Semicon-CY62187G30-55BAXI_C2950478.html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

This looked quite cheap, it's SRAM, and, a drop in replacement! (well, since [BYTE#] is tied high, on the existing SIMM, it is) just in a BGA format! So, I had a look around at buying some... unfortunately, they're even more expensive than the regular SRAM ICs on Farnell/Mouser/Digikey!
I had assumed that the LCSC price ... would be similar on the other vendors.

SO!
To that end... do you think that Pseudo-SRAM would work, as a drop in replacement?

And, how fast would it have to be?
70ns is readily available, IS66WVE4M16EBLL-70BLI but, my friend has pointed out 55ns exists too! (Except I can't seem to find any 55ns handy)

https://www.issi.com/WW/pdf/66-67WVE4M16EALL-BLL-CLL.pdf
IS66WVE4M16EBLL-55BLI

This is a DRAM masquerading as an SRAM chip, with a hidden auto-refresh, so, it presents to the bus as normal SRAM.
And, if we tie [ZZ#] high, I think it could be a drop in replacement?

OK, a new BGA SIMM PCB needs to be designed but, 48MB of that (P)SRAM is $30, not $150 for the current IC!!
What do you think??

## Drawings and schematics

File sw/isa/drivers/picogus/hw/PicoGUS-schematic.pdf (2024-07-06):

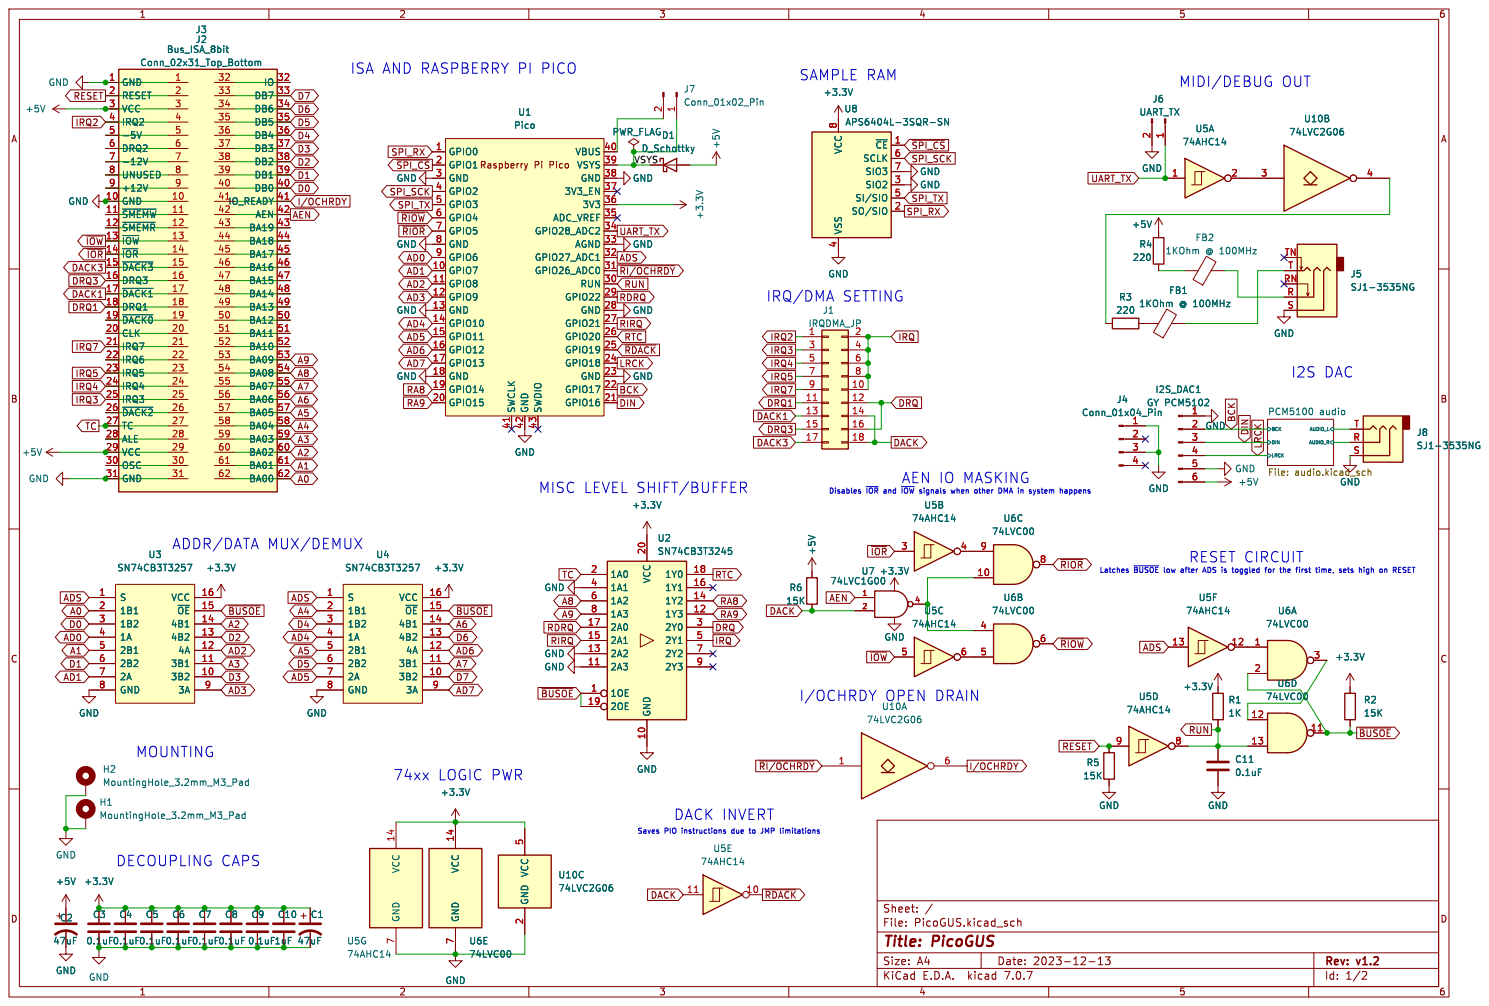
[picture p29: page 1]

J3 Bus_ISA_8bit GND 1 GND 10 ~{SMEMW} 11 ~{SMEMR} 12 ~{IOW} 13 ~{IOR} 14 ~{DACK3} 15 DRQ3 16 ~{DACK1} 17 DRQ1 18 ~{DACK0} 19 RESET 2 CLK 20
GND 1 GND 10 ~{SMEMW} 11 ~{SMEMR} 12 ~{IOW} 13 ~{IOR} 14 ~{DACK3} 15 DRQ3 16 ~{DACK1} 17 DRQ1 18 ~{DACK0} 19 RESET 2 CLK 20
~{RI/OCHRDY} D6 D7 D3 D4 D5 TC
IRQ3 25 ~{DACK2} 26 TC 27 ALE 28 VCC 29 VCC 3 OSC 30 GND 31

ISA AND RASPBERRY PI PICO

8 GND GND
~{CE}1 SO/SIO 2 SIO2 3 VSS

4 SI/SIO 5 SCLK 6 SIO3 7 VCC

GND GND

ADDR/DATA MUX/DEMUX

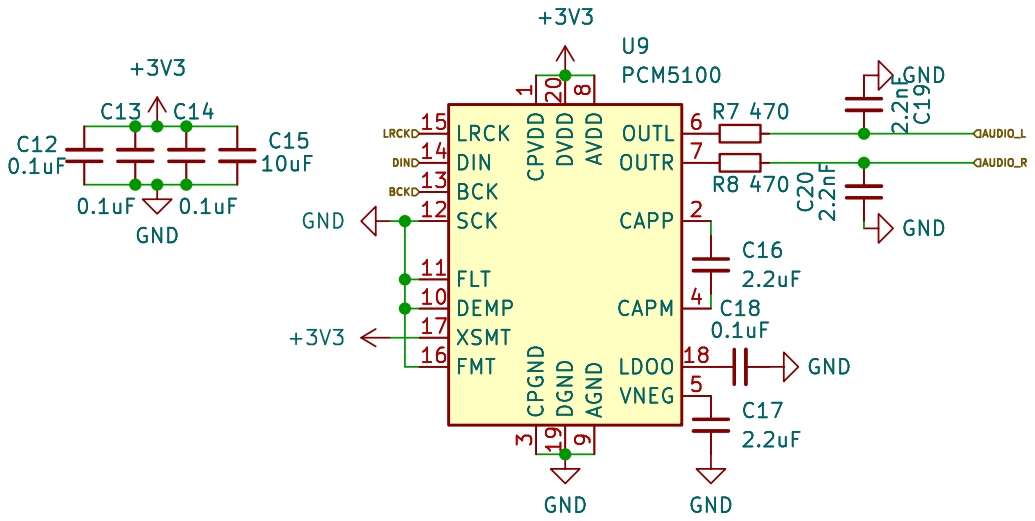
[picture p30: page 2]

1 DEMP 10 FLT 11 SCK 12 BCK 13 DIN 14

3 CAPM 4 VNEG 5 OUTL 6 OUTR 7 AVDD

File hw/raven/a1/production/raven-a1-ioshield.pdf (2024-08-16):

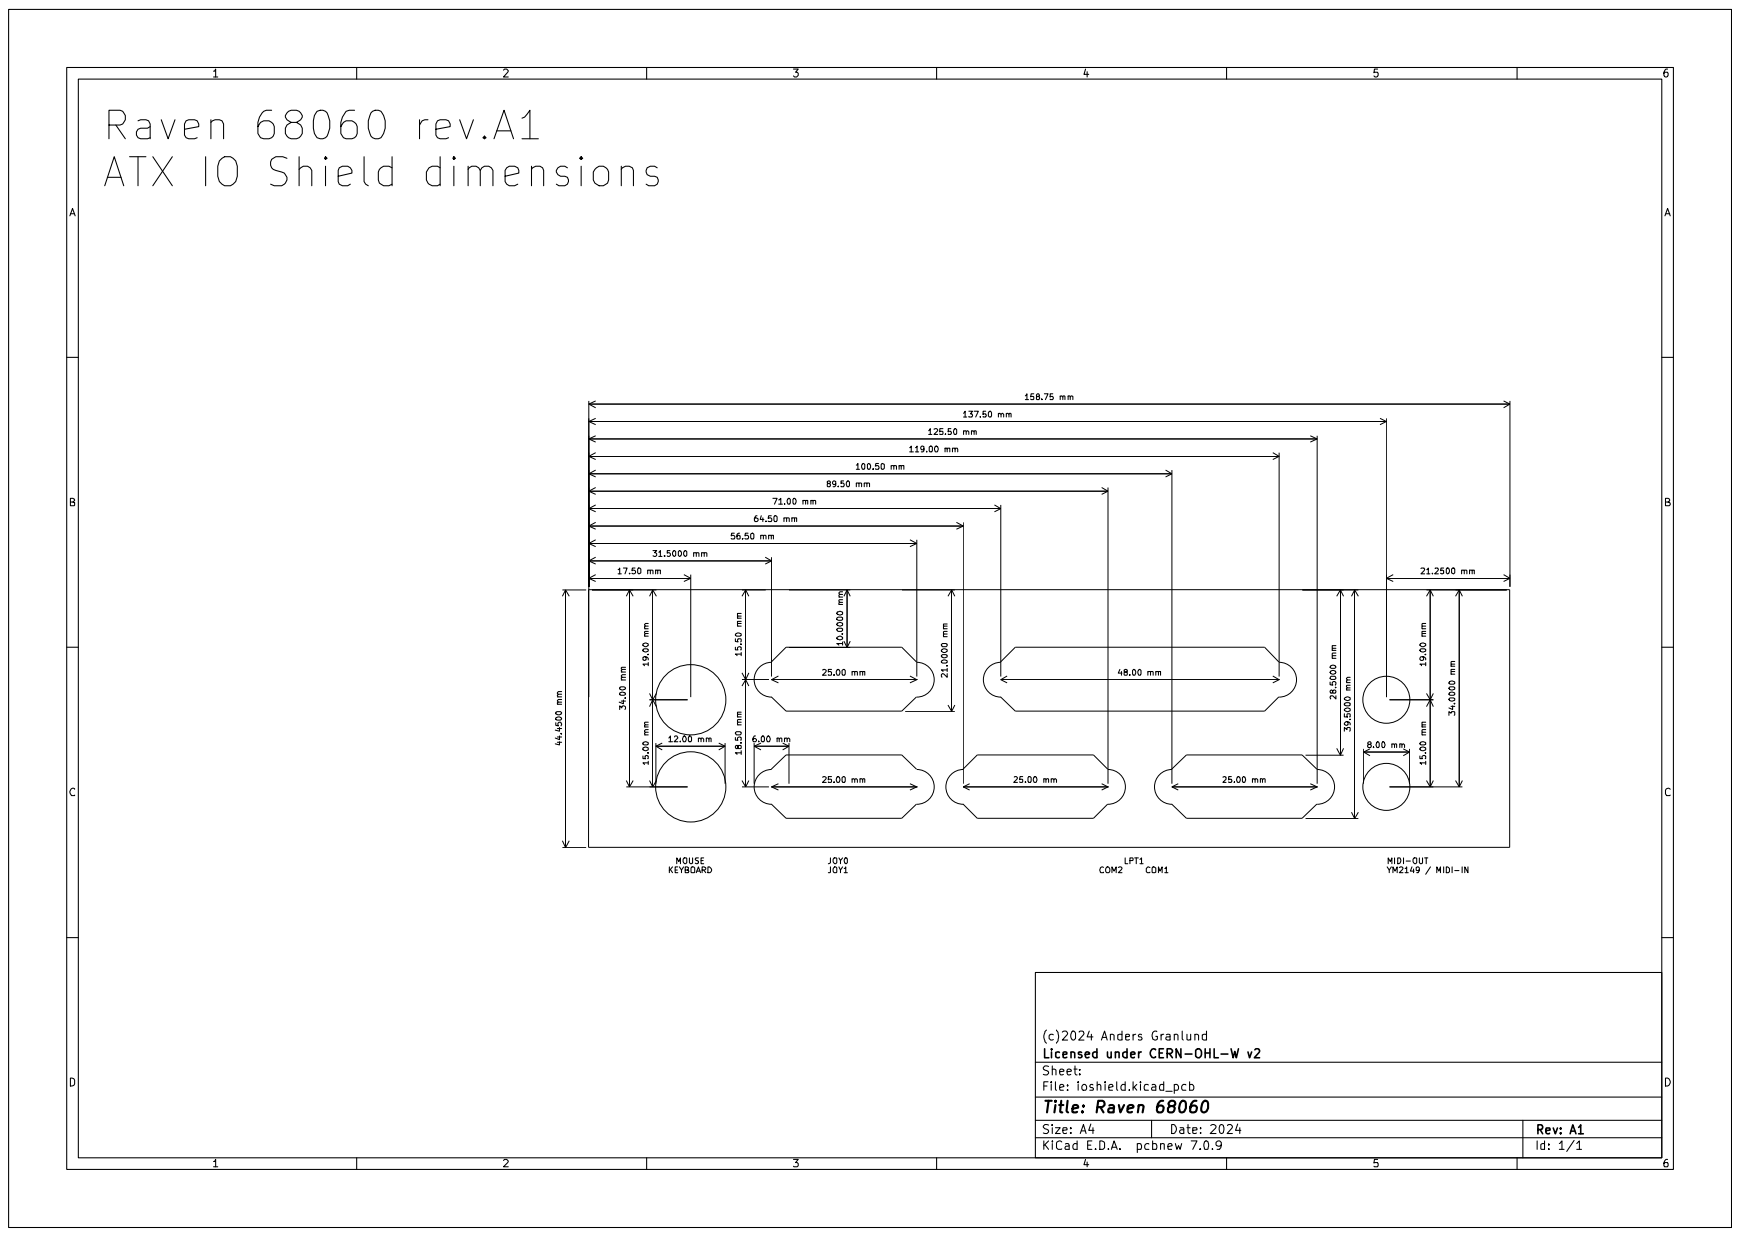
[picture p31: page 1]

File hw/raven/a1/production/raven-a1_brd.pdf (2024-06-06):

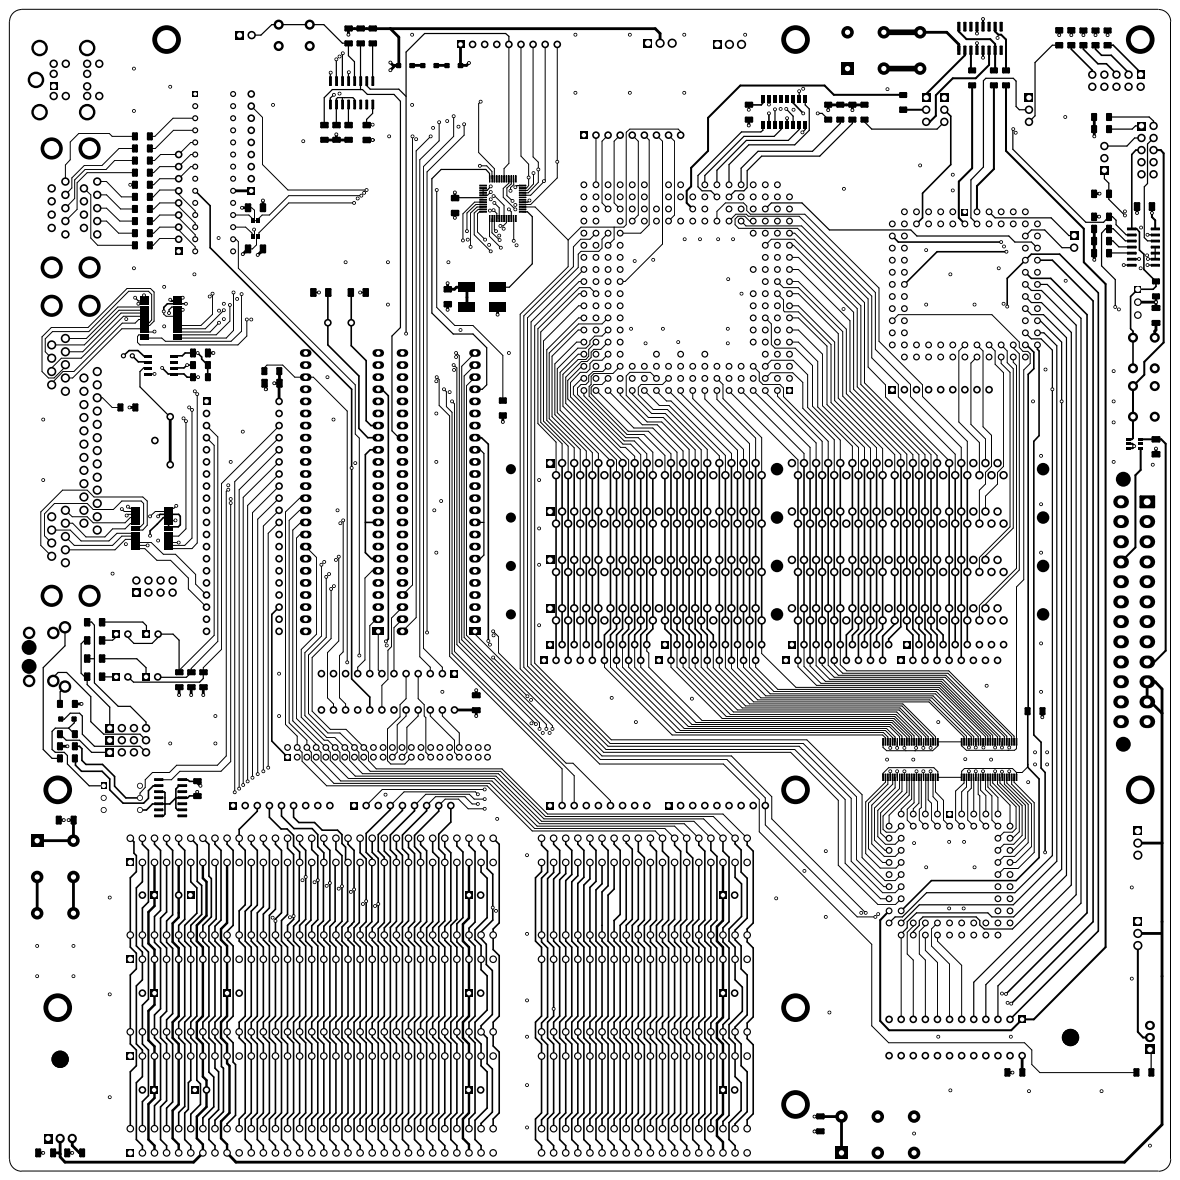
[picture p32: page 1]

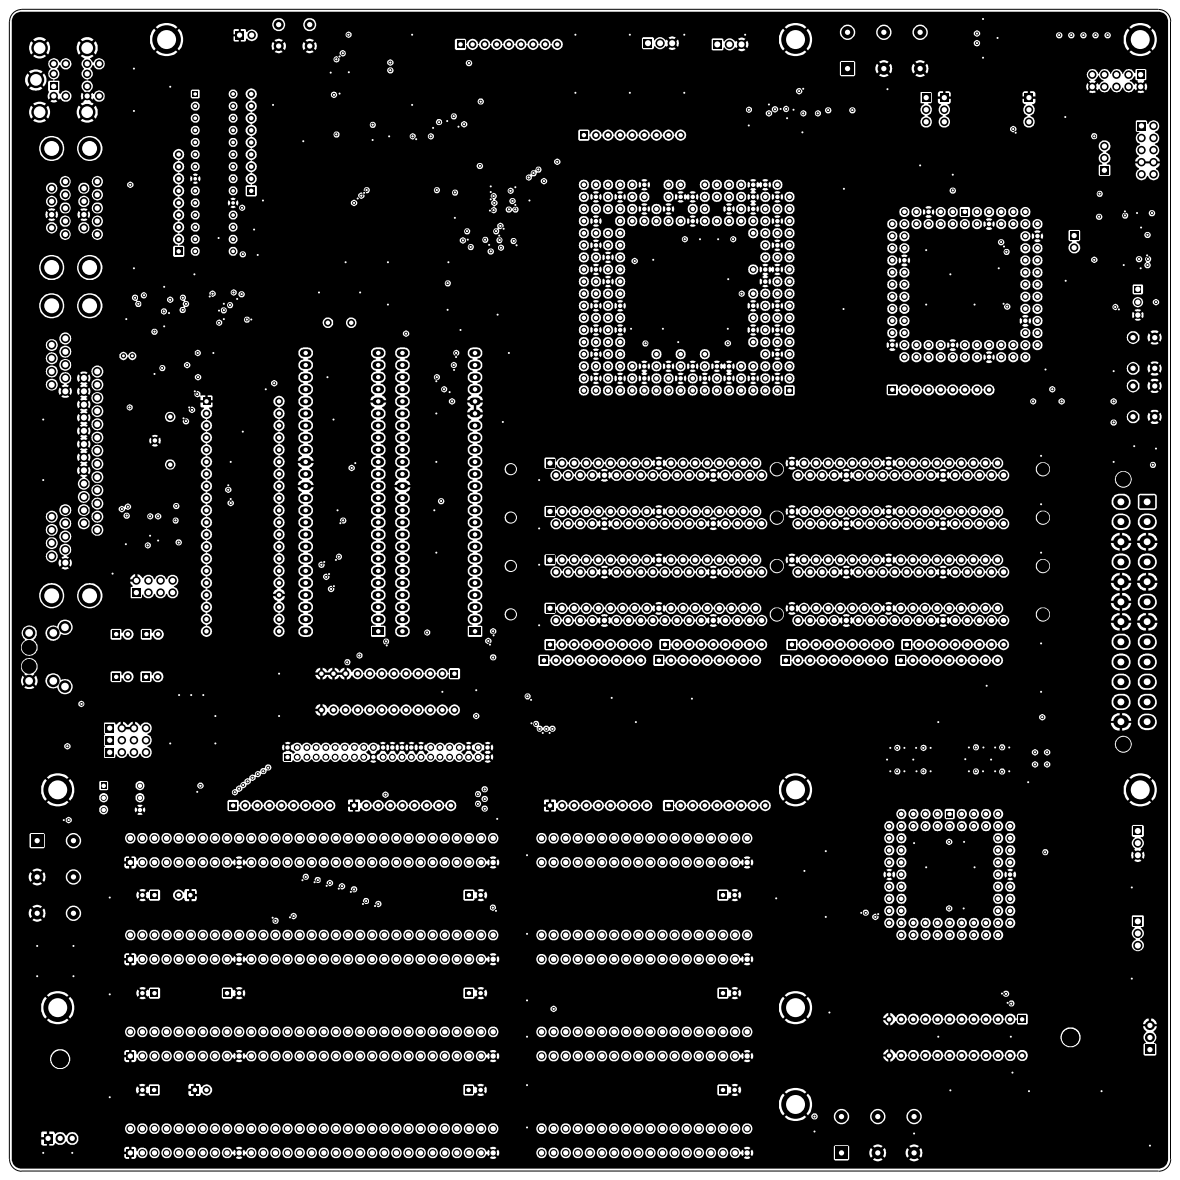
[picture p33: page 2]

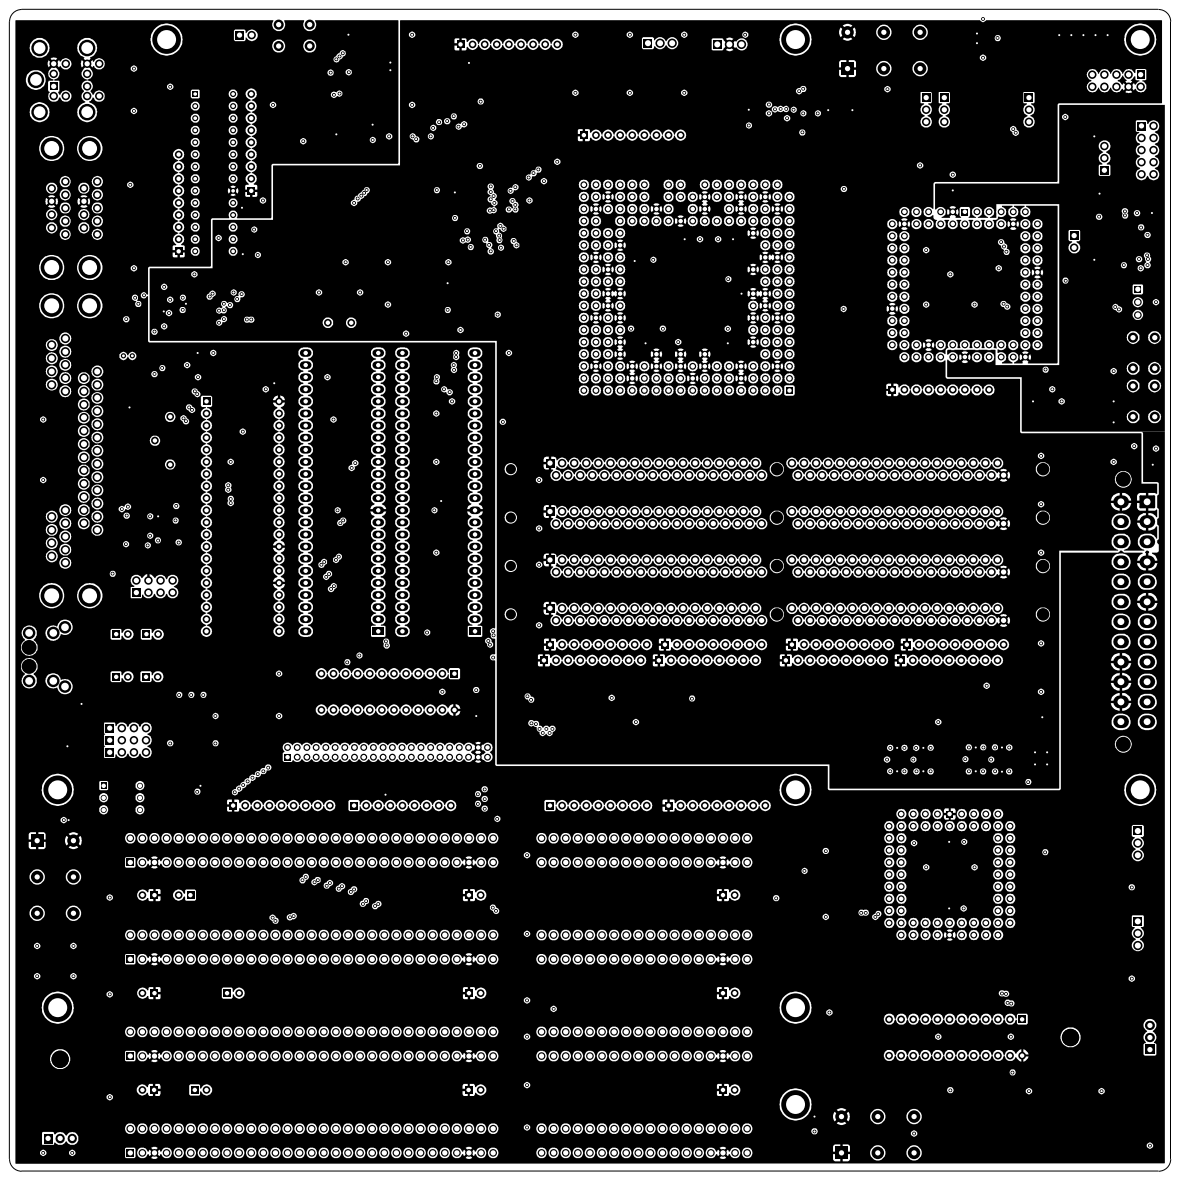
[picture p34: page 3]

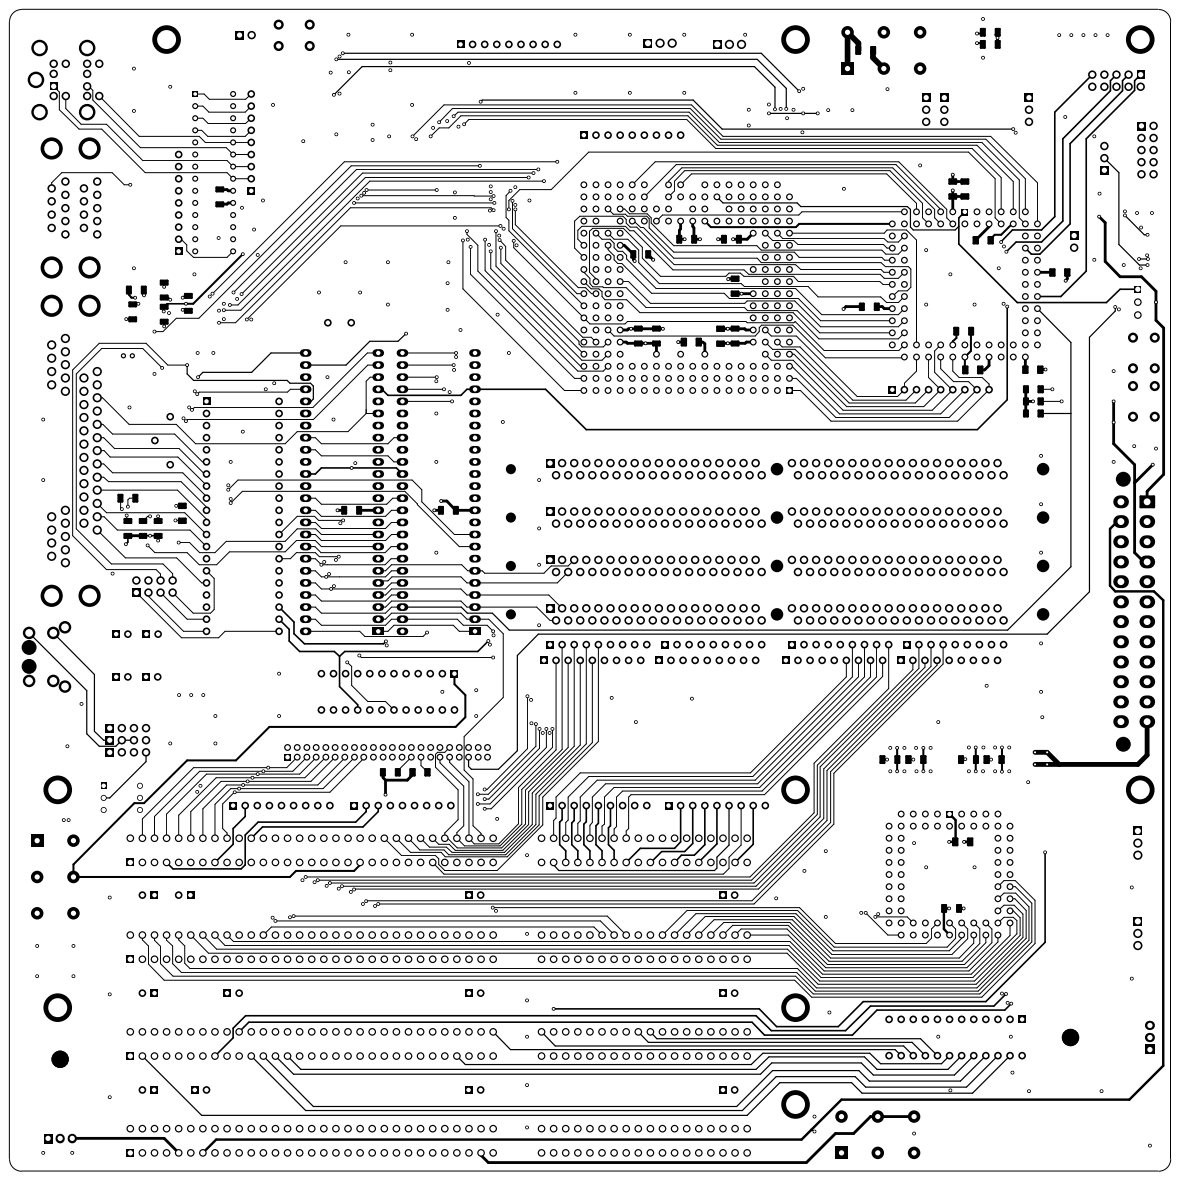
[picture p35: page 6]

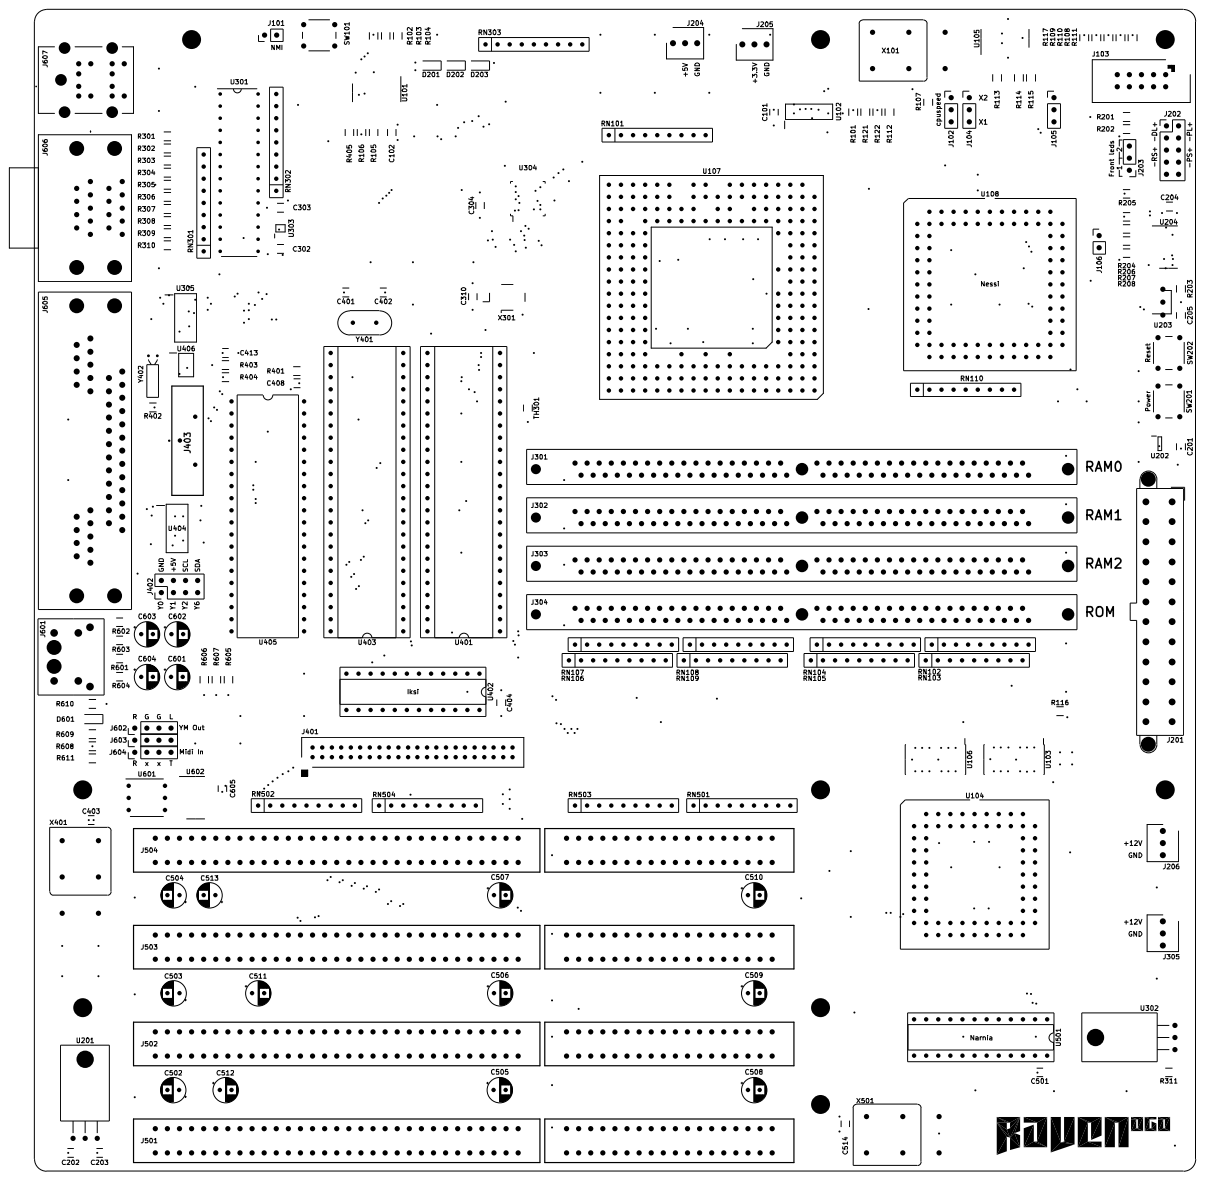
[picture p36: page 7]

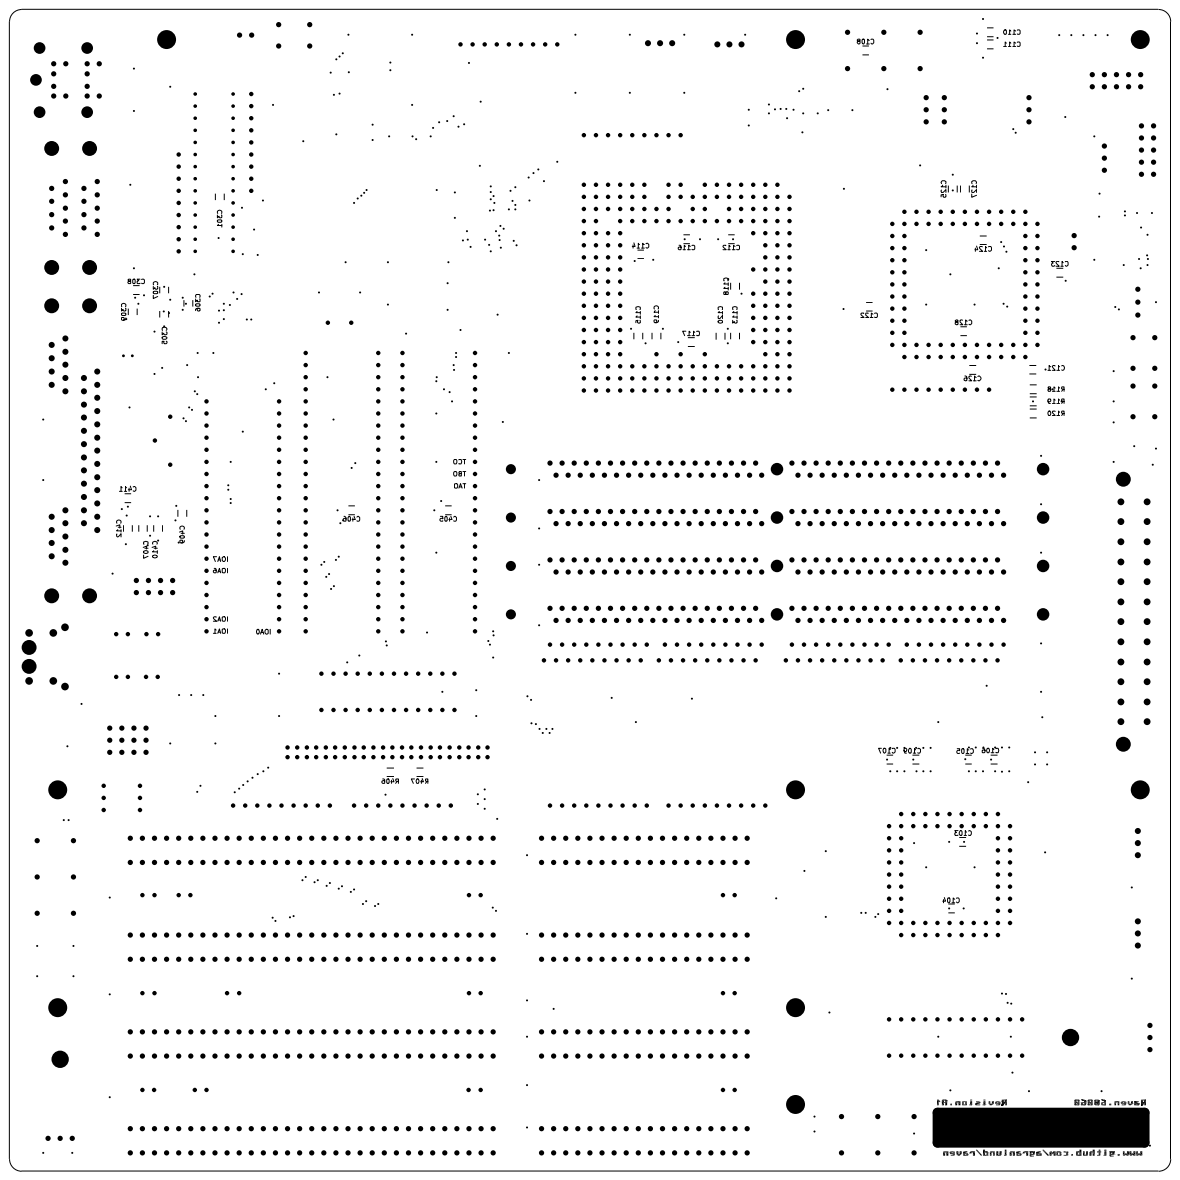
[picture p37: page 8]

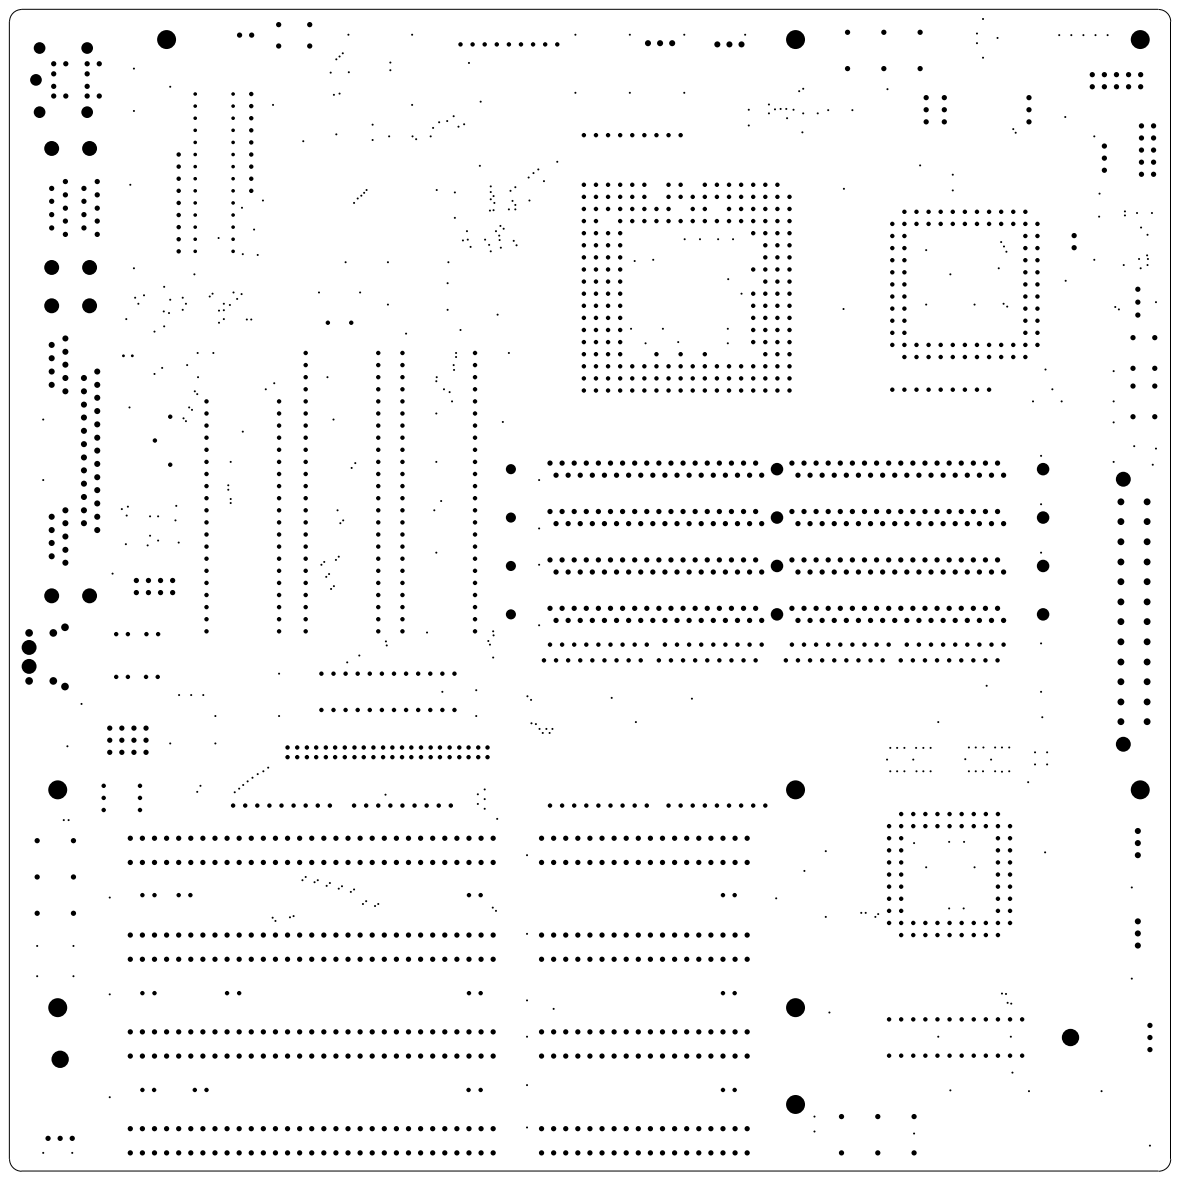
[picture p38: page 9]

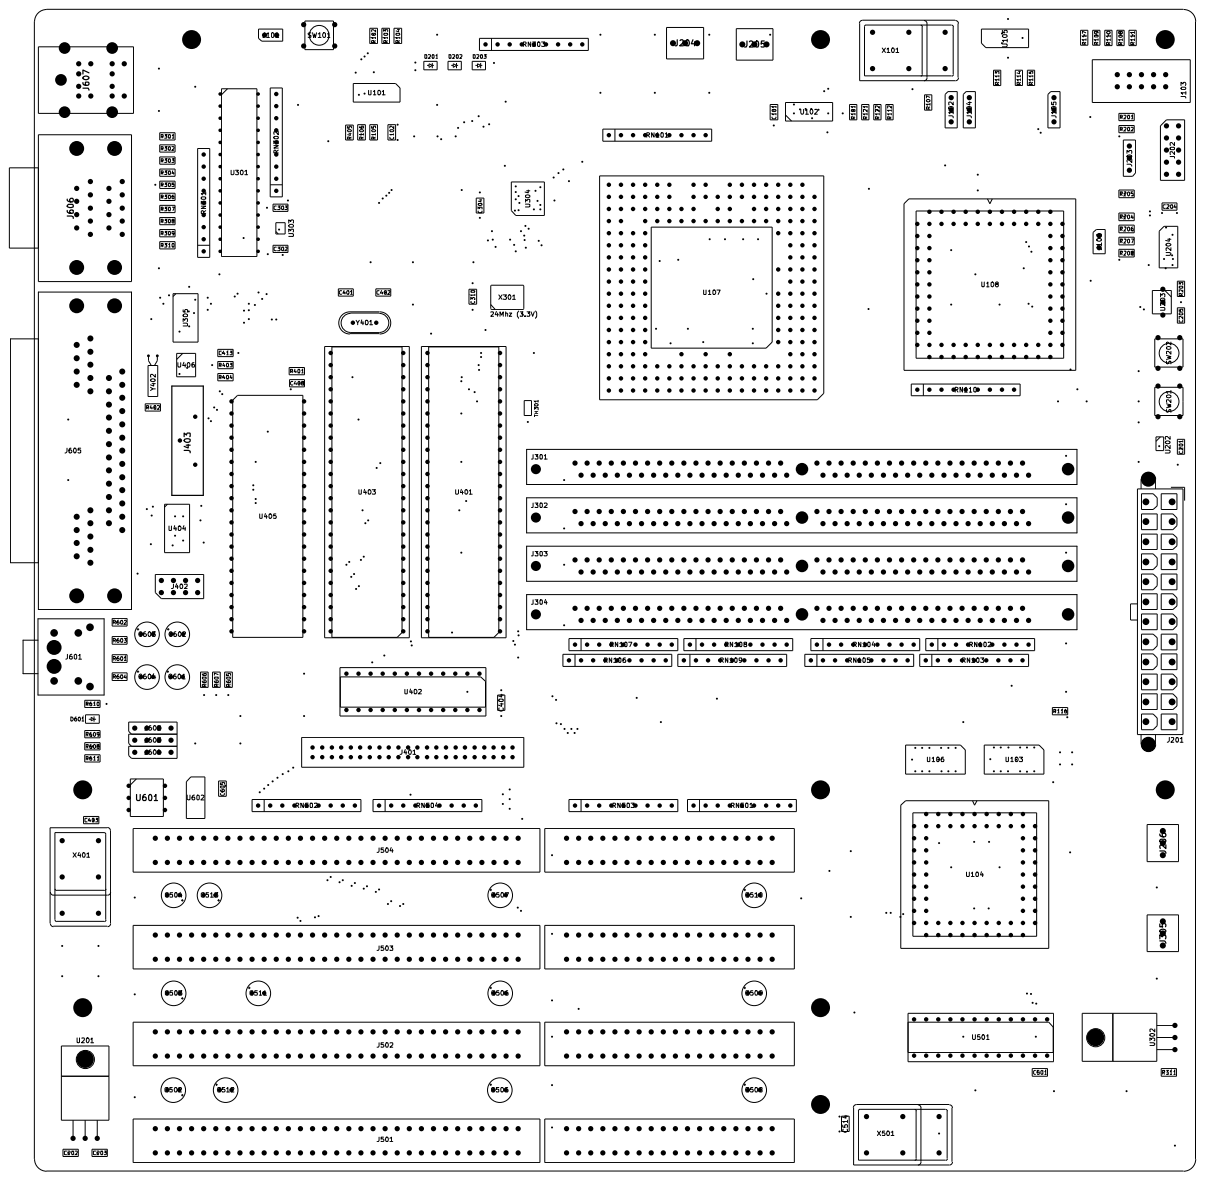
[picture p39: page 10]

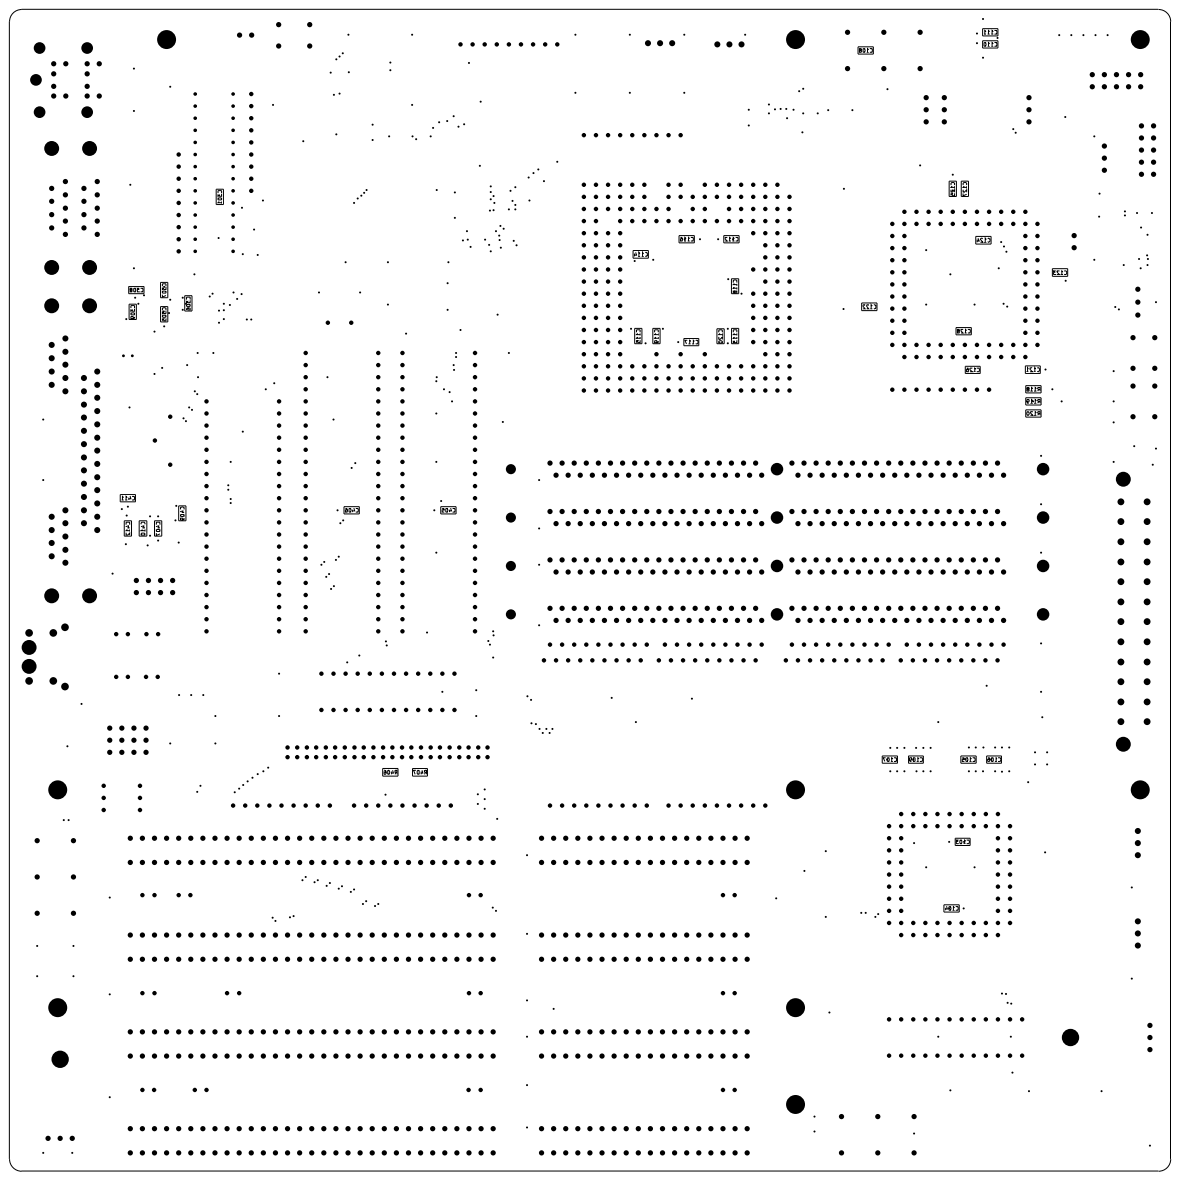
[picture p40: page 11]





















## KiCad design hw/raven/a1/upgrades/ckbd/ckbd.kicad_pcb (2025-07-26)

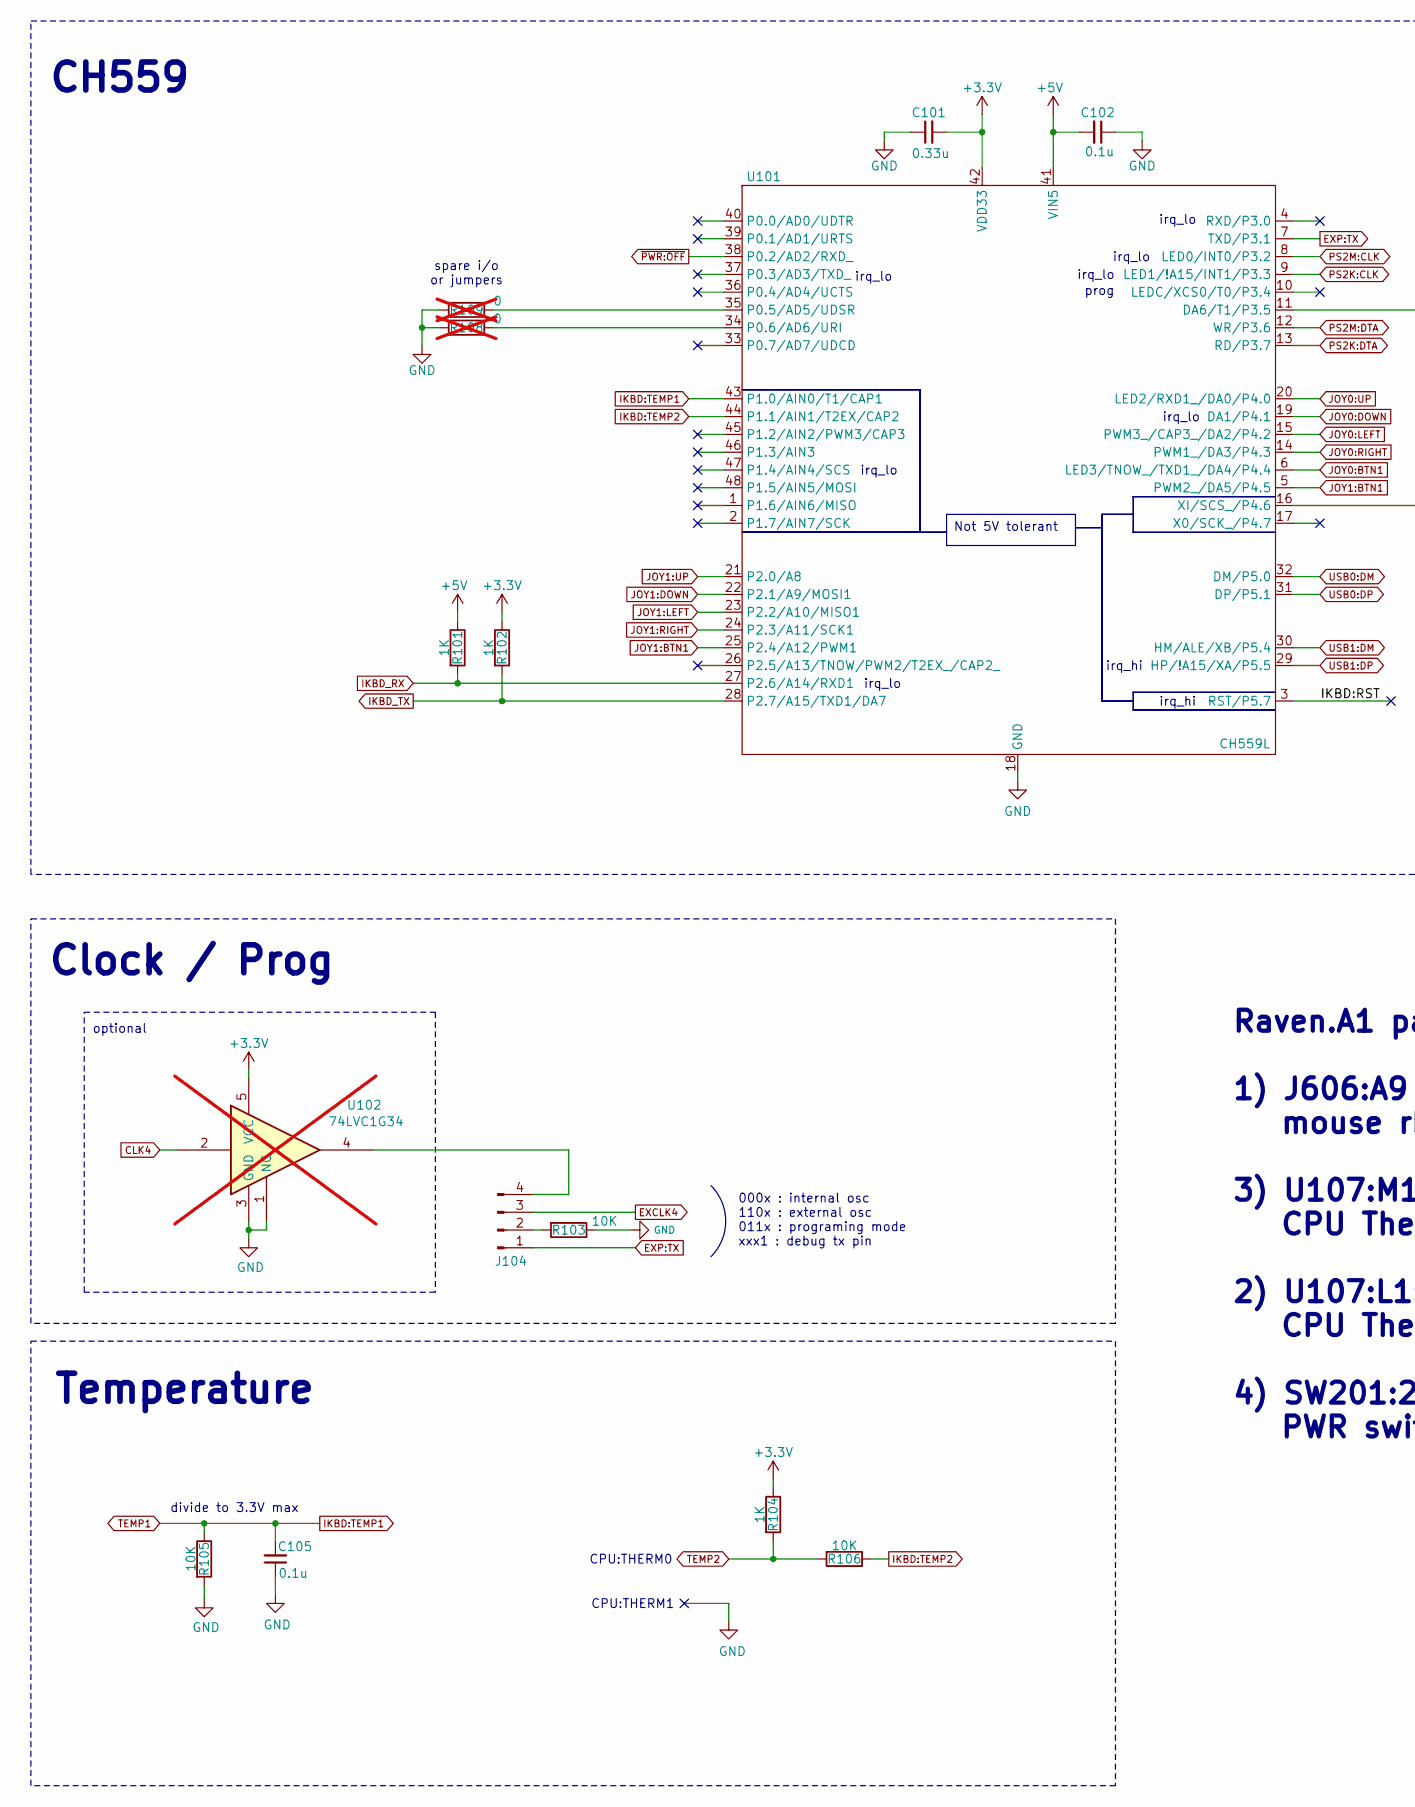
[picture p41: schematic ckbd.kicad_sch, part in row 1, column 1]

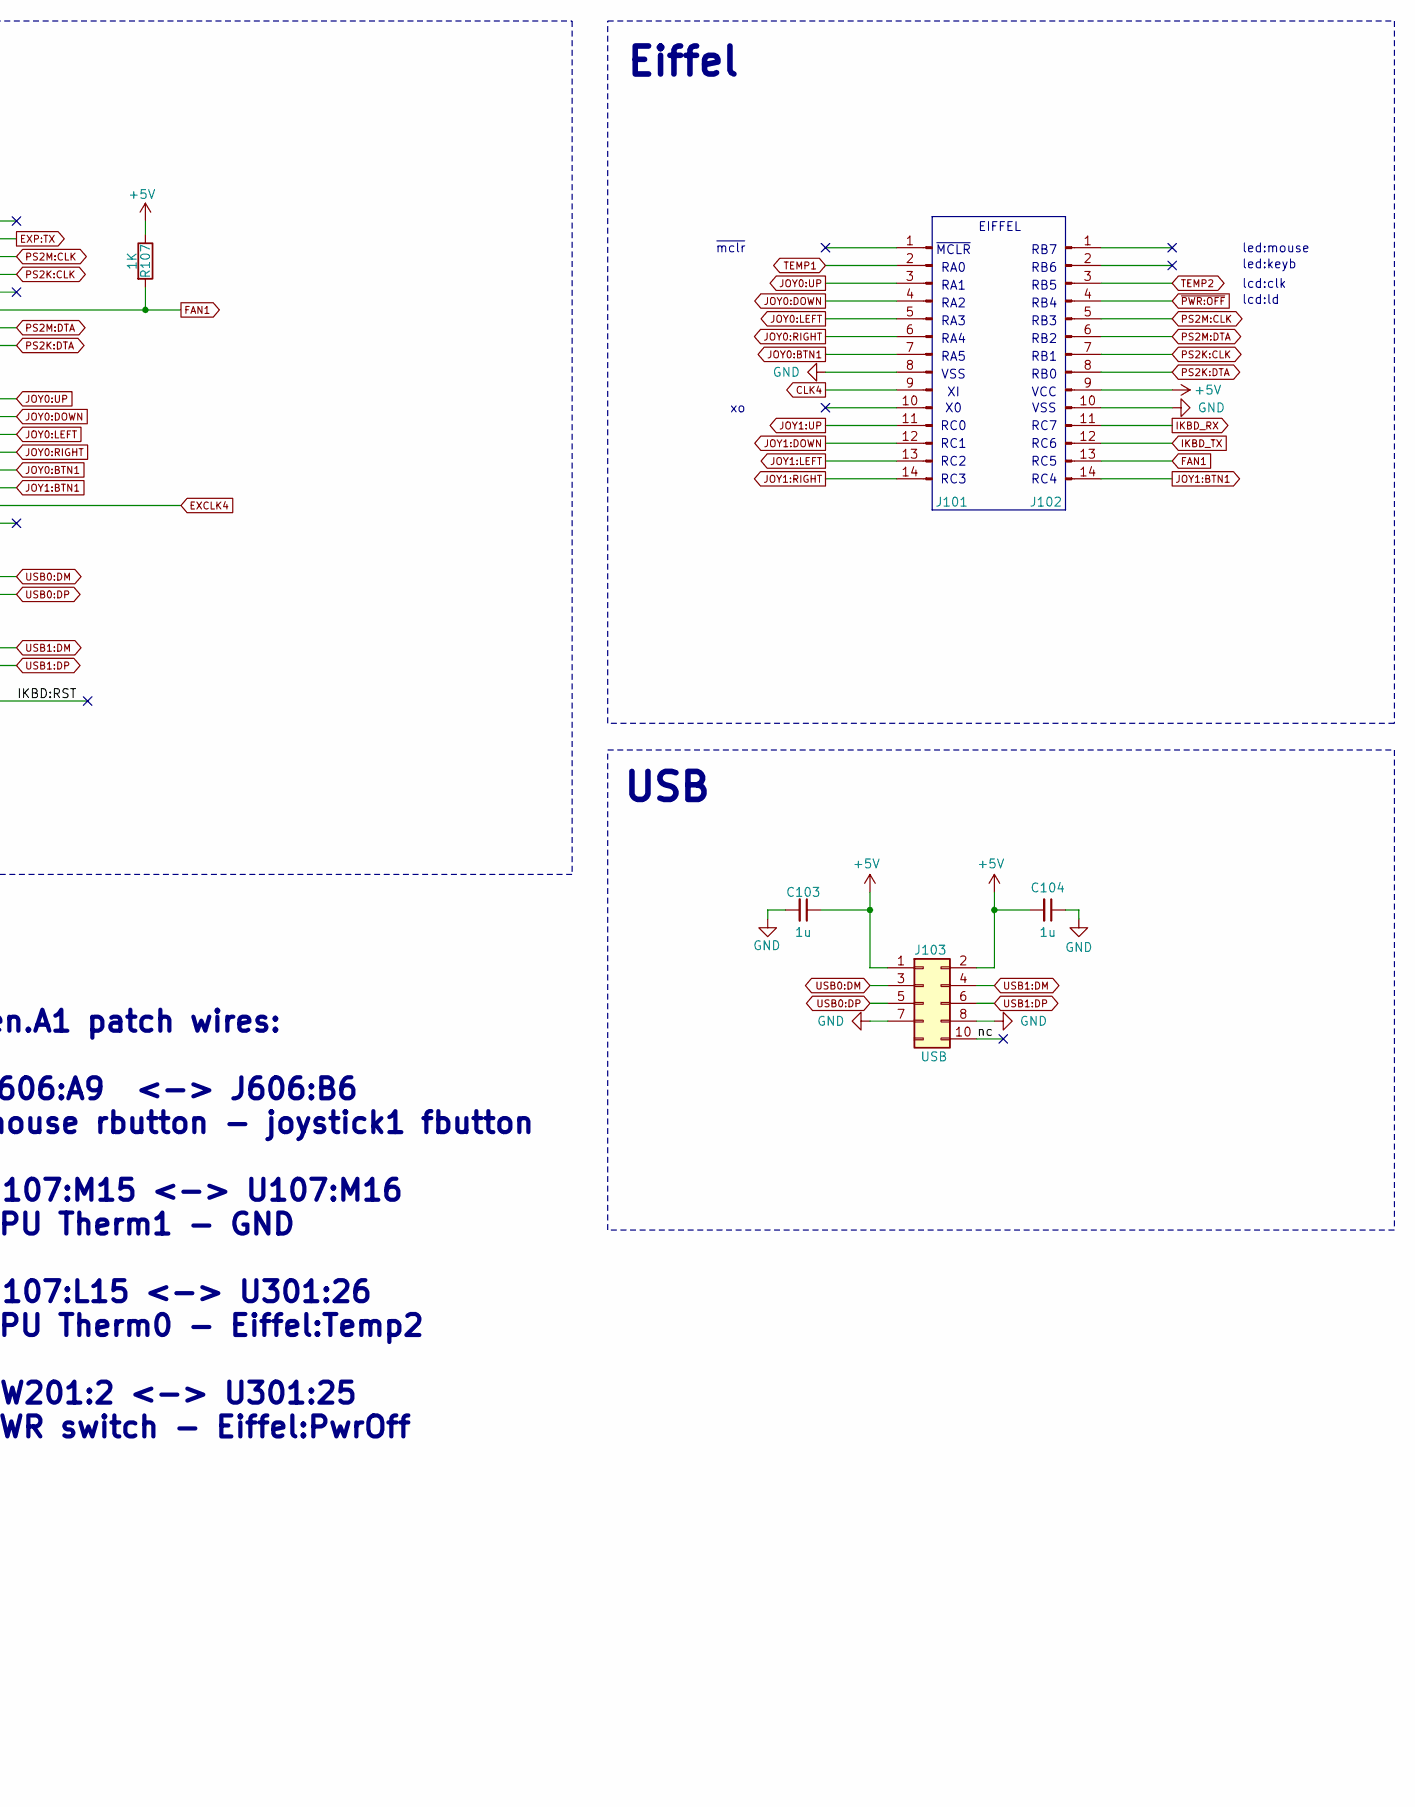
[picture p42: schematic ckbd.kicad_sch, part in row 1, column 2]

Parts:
C101: 0.33u; C_1206_3216Metric_Pad1.33x1.80mm_HandSolder; Manufacturer_Part_Number C1206C334K5RACTU
C102, C105: 0.1u; C_1206_3216Metric_Pad1.33x1.80mm_HandSolder; Manufacturer_Part_Number C1206C104K5RACTU
C103, C104: 1u; C_1206_3216Metric_Pad1.33x1.80mm_HandSolder; Manufacturer_Part_Number C1206C105K4RACTU
J101, J102: PinHeader_1x14_P2.54mm_Vertical
J103: USB; USB2Header
J104: PinHeader_1x04_P2.54mm_Vertical; Manufacturer_Part_Number 61300411121
R101, R102, R104, R107: 1K; R_1206_3216Metric_Pad1.30x1.75mm_HandSolder; Manufacturer_Part_Number RT1206FRE071KL
R103, R105, R106: 10K; R_1206_3216Metric_Pad1.30x1.75mm_HandSolder; Manufacturer_Part_Number RT1206FRE0710KL
R108, R109: 0; R_1206_3216Metric; not fitted
U101: CH559L; LQFP-48_7x7mm_P0.5mm; Manufacturer_Part_Number CH559L
U102: 74LVC1G34; SOT-23-5_HandSoldering; Manufacturer_Part_Number SN74LVC1G34DBVRG4; not fitted

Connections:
+3.3V: C101.2, R102.1, R104.1, U101.42 (VDD33), U102.5 (VCC)
+5V: C102.2, C103.1, C104.2, J102.9, J103.1, J103.2, R101.1, R107.1, U101.41 (VIN5)
/IKBD:RST: U101.3 (RST/P5.7)
/nc: J103.10
CLK4: J101.9, U102.2
EXCLK4: J104.3, U101.16 (XI/SCS_/P4.6)
EXP:TX: J104.1, U101.7 (TXD/P3.1)
FAN1: J102.13, R107.2, U101.11 (DA6/T1/P3.5)
GND: C101.1, C102.1, C103.2, C104.1, C105.1, J101.8, J102.10, J103.7, J103.8, R103.1, R105.2, R108.1, R109.1, U101.18 (GND), U102.1 (NC), U102.3 (GND)
IKBD:TEMP1: C105.2, J101.2, R105.1, U101.43 (P1.0/AIN0/T1/CAP1)
IKBD:TEMP2: R106.1, U101.44 (P1.1/AIN1/T2EX/CAP2)
IKBD_RX: J102.11, R101.2, U101.27 (P2.6/A14/RXD1)
IKBD_TX: J102.12, R102.2, U101.28 (P2.7/A15/TXD1/DA7)
JOY0:BTN1: J101.7, U101.6 (LED3/TNOW_/TXD1_/DA4/P4.4)
JOY0:DOWN: J101.4, U101.19 (DA1/P4.1)
JOY0:LEFT: J101.5, U101.15 (PWM3_/CAP3_/DA2/P4.2)
JOY0:RIGHT: J101.6, U101.14 (PWM1_/DA3/P4.3)
JOY0:UP: J101.3, U101.20 (LED2/RXD1_/DA0/P4.0)
JOY1:BTN1: J102.14, U101.5 (PWM2_/DA5/P4.5), U101.25 (P2.4/A12/PWM1)
JOY1:DOWN: J101.12, U101.22 (P2.1/A9/MOSI1)
JOY1:LEFT: J101.13, U101.23 (P2.2/A10/MISO1)
JOY1:RIGHT: J101.14, U101.24 (P2.3/A11/SCK1)
JOY1:UP: J101.11, U101.21 (P2.0/A8)
unnamed: J104.2, R103.2
unnamed: J104.4, U102.4
unnamed: R109.2, U101.35 (P0.5/AD5/UDSR)
unnamed: R108.2, U101.34 (P0.6/AD6/URI)
PS2K:CLK: J102.7, U101.9 (LED1/!A15/INT1/P3.3)
PS2K:DTA: J102.8, U101.13 (RD/P3.7)
PS2M:CLK: J102.5, U101.8 (LED0/INT0/P3.2)
PS2M:DTA: J102.6, U101.12 (WR/P3.6)
TEMP2: J102.3, R104.2, R106.2
USB0:DM: J103.3, U101.32 (DM/P5.0)
USB0:DP: J103.5, U101.31 (DP/P5.1)
USB1:DM: J103.4, U101.30 (HM/ALE/XB/P5.4)
USB1:DP: J103.6, U101.29 (HP/!A15/XA/P5.5)
~PWR:OFF: J102.4, U101.38 (P0.2/AD2/RXD_)

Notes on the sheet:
RC7
EIFFEL
RB6
RC4
irq_lo
RA4
RA0
VCC
RB2
RB5
RB7
RC0
RB1
Eiffel
irq_hi
~{MCLR}
led:keyb
lcd:clk
CH559
USB
RB4
lcd:ld
RC3
000x : internal osc 110x : external osc 011x : programing mode xxx1 : debug tx pin
CPU:THERM1
divide to 3.3V max
RB0
RC6
Temperature
CPU:THERM0
RA3
RA2
prog
VSS
led:mouse
RB3
RC2
Clock / Prog
RA5
RA1

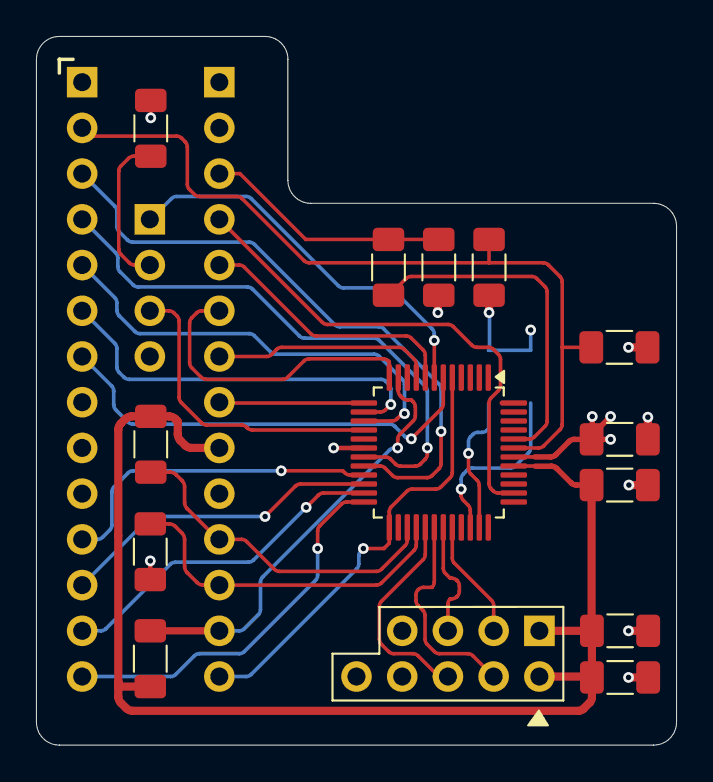
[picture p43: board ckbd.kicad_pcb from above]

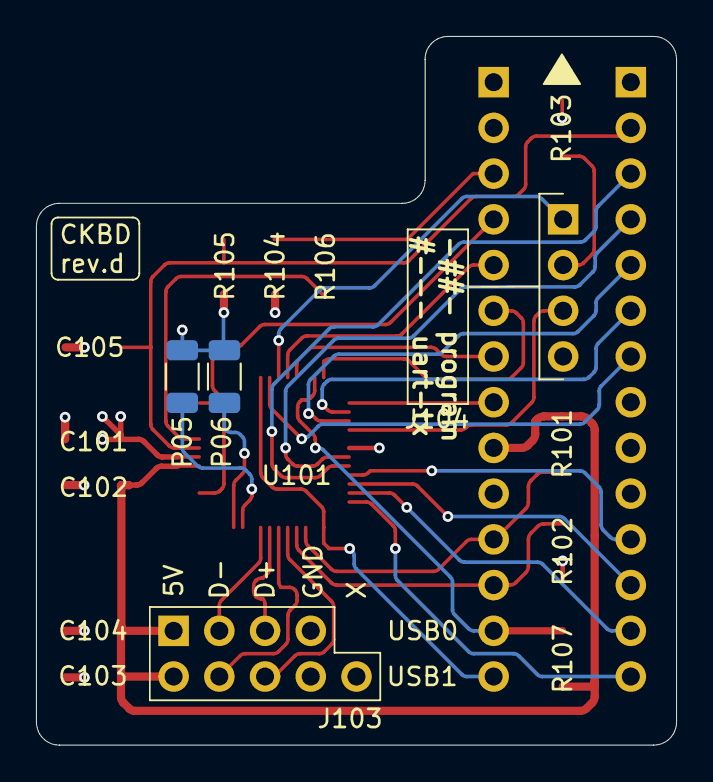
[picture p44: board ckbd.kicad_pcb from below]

Board: 4 copper layers, 35.6 x 39.4 mm, 19 parts (2 on the bottom side), 33 nets.

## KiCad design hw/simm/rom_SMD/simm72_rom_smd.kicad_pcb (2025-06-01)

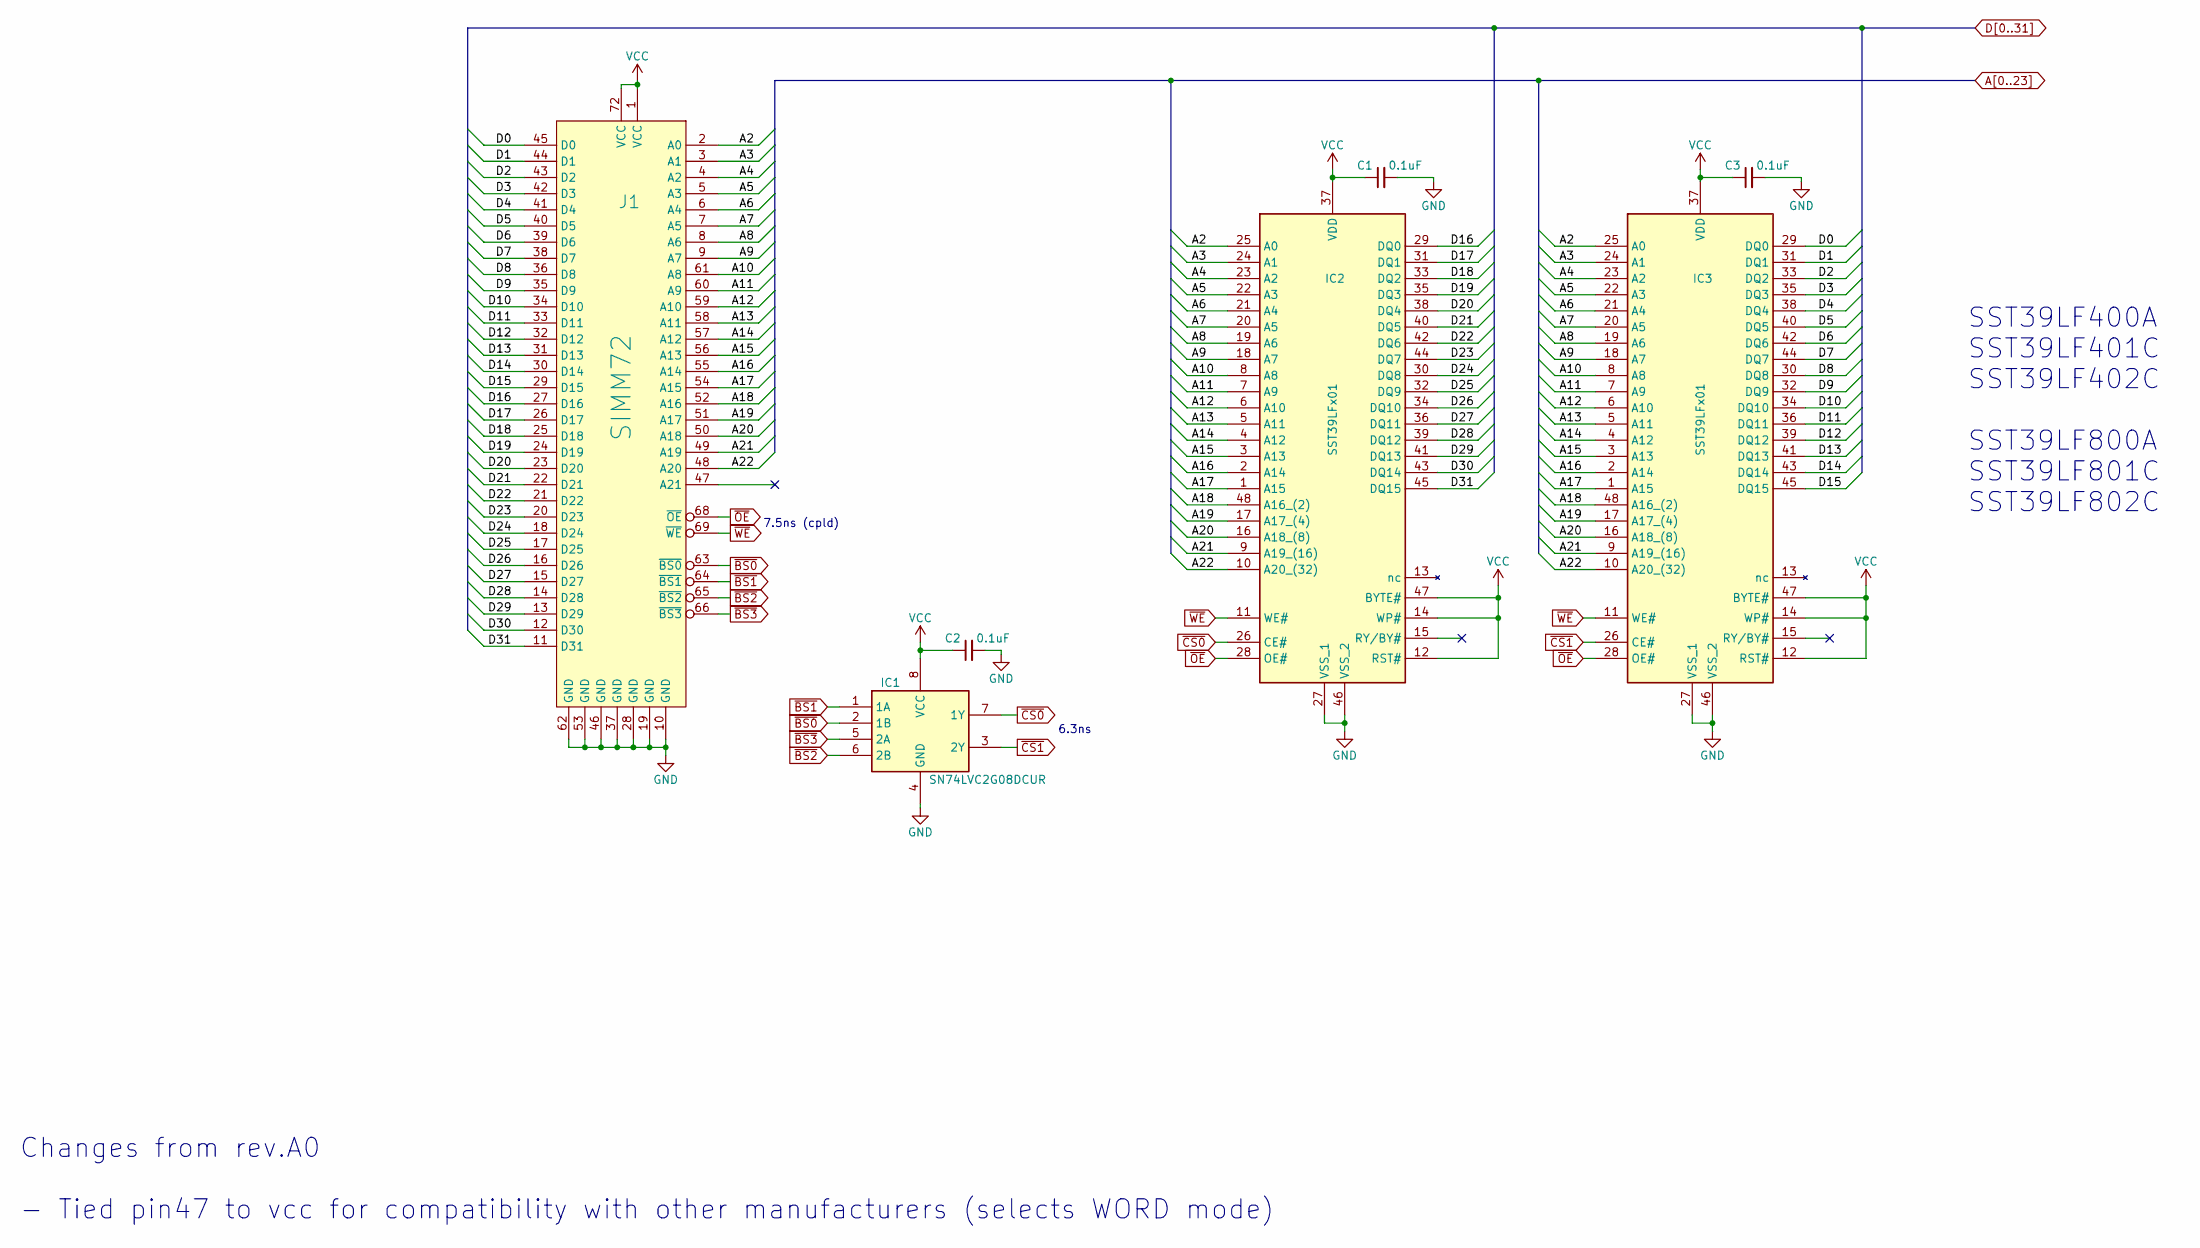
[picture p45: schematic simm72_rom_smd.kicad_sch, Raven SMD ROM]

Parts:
C1, C2, C3: 0.1uF; C_1206_3216Metric_Pad1.33x1.80mm_HandSolder; Manufacturer_Part_Number C1206C104K5RACTU
IC1: SN74LVC2G08DCUR; SOP50P310X90-8N; Mouser Part Number 595-SN74LVC2G08DCUR
IC2, IC3: SST39LFx01; SOP50P2000X120-48N; Mouser Part Number 579-39LF401C554CEKET
J1: SIMM72; SIMM72_edge

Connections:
A2: IC2.25 (A0), IC3.25 (A0), J1.2 (A0)
A3: IC2.24 (A1), IC3.24 (A1), J1.3 (A1)
A4: IC2.23 (A2), IC3.23 (A2), J1.4 (A2)
A5: IC2.22 (A3), IC3.22 (A3), J1.5 (A3)
A6: IC2.21 (A4), IC3.21 (A4), J1.6 (A4)
A7: IC2.20 (A5), IC3.20 (A5), J1.7 (A5)
A8: IC2.19 (A6), IC3.19 (A6), J1.8 (A6)
A9: IC2.18 (A7), IC3.18 (A7), J1.9 (A7)
A10: IC2.8 (A8), IC3.8 (A8), J1.61 (A8)
A11: IC2.7 (A9), IC3.7 (A9), J1.60 (A9)
A12: IC2.6 (A10), IC3.6 (A10), J1.59 (A10)
A13: IC2.5 (A11), IC3.5 (A11), J1.58 (A11)
A14: IC2.4 (A12), IC3.4 (A12), J1.57 (A12)
A15: IC2.3 (A13), IC3.3 (A13), J1.56 (A13)
A16: IC2.2 (A14), IC3.2 (A14), J1.55 (A14)
A17: IC2.1 (A15), IC3.1 (A15), J1.54 (A15)
A18: IC2.48 (A16_(2)), IC3.48 (A16_(2)), J1.52 (A16)
A19: IC2.17 (A17_(4)), IC3.17 (A17_(4)), J1.51 (A17)
A20: IC2.16 (A18_(8)), IC3.16 (A18_(8)), J1.50 (A18)
A21: IC2.9 (A19_(16)), IC3.9 (A19_(16)), J1.49 (A19)
A22: IC2.10 (A20_(32)), IC3.10 (A20_(32)), J1.48 (A20)
D0: IC3.29 (DQ0), J1.45 (D0)
D1: IC3.31 (DQ1), J1.44 (D1)
D2: IC3.33 (DQ2), J1.43 (D2)
D3: IC3.35 (DQ3), J1.42 (D3)
D4: IC3.38 (DQ4), J1.41 (D4)
D5: IC3.40 (DQ5), J1.40 (D5)
D6: IC3.42 (DQ6), J1.39 (D6)
D7: IC3.44 (DQ7), J1.38 (D7)
D8: IC3.30 (DQ8), J1.36 (D8)
D9: IC3.32 (DQ9), J1.35 (D9)
D10: IC3.34 (DQ10), J1.34 (D10)
D11: IC3.36 (DQ11), J1.33 (D11)
D12: IC3.39 (DQ12), J1.32 (D12)
D13: IC3.41 (DQ13), J1.31 (D13)
D14: IC3.43 (DQ14), J1.30 (D14)
D15: IC3.45 (DQ15), J1.29 (D15)
D16: IC2.29 (DQ0), J1.27 (D16)
D17: IC2.31 (DQ1), J1.26 (D17)
D18: IC2.33 (DQ2), J1.25 (D18)
D19: IC2.35 (DQ3), J1.24 (D19)
D20: IC2.38 (DQ4), J1.23 (D20)
D21: IC2.40 (DQ5), J1.22 (D21)
D22: IC2.42 (DQ6), J1.21 (D22)
D23: IC2.44 (DQ7), J1.20 (D23)
D24: IC2.30 (DQ8), J1.18 (D24)
D25: IC2.32 (DQ9), J1.17 (D25)
D26: IC2.34 (DQ10), J1.16 (D26)
D27: IC2.36 (DQ11), J1.15 (D27)
D28: IC2.39 (DQ12), J1.14 (D28)
D29: IC2.41 (DQ13), J1.13 (D29)
D30: IC2.43 (DQ14), J1.12 (D30)
D31: IC2.45 (DQ15), J1.11 (D31)
GND: C1.2, C2.2, C3.2, IC1.4 (GND), IC2.27 (VSS_1), IC2.46 (VSS_2), IC3.27 (VSS_1), IC3.46 (VSS_2), J1.10 (GND), J1.19 (GND), J1.28 (GND), J1.37 (GND), J1.46 (GND), J1.53 (GND), J1.62 (GND)
VCC: C1.1, C2.1, C3.1, IC1.8 (VCC), IC2.12 (RST#), IC2.14 (WP#), IC2.37 (VDD), IC2.47 (BYTE#), IC3.12 (RST#), IC3.14 (WP#), IC3.37 (VDD), IC3.47 (BYTE#), J1.1 (VCC), J1.72 (VCC)
~BS0: IC1.2 (1B), J1.63 (~BS0)
~BS1: IC1.1 (1A), J1.64 (~BS1)
~BS2: IC1.6 (2B), J1.65 (~BS2)
~BS3: IC1.5 (2A), J1.66 (~BS3)
~CS0: IC1.7 (1Y), IC2.26 (CE#)
~CS1: IC1.3 (2Y), IC3.26 (CE#)
~OE: IC2.28 (OE#), IC3.28 (OE#), J1.68 (~OE)
~WE: IC2.11 (WE#), IC3.11 (WE#), J1.69 (~WE)

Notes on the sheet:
7.5ns (cpld)
6.3ns
Changes from rev.A0 - Tied pin47 to vcc for compatibility with other manufacturers (selects WORD mode)
SST39LF400A SST39LF401C SST39LF402C SST39LF800A SST39LF801C SST39LF802C

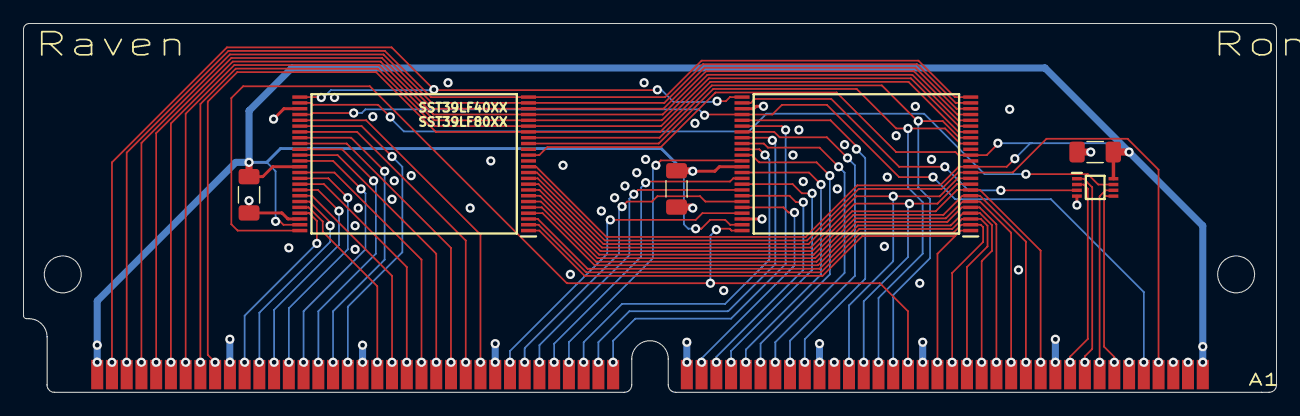
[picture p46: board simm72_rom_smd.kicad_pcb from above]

Board: 4 copper layers, 108.0 x 31.8 mm, 7 parts (0 on the bottom side), 63 nets.

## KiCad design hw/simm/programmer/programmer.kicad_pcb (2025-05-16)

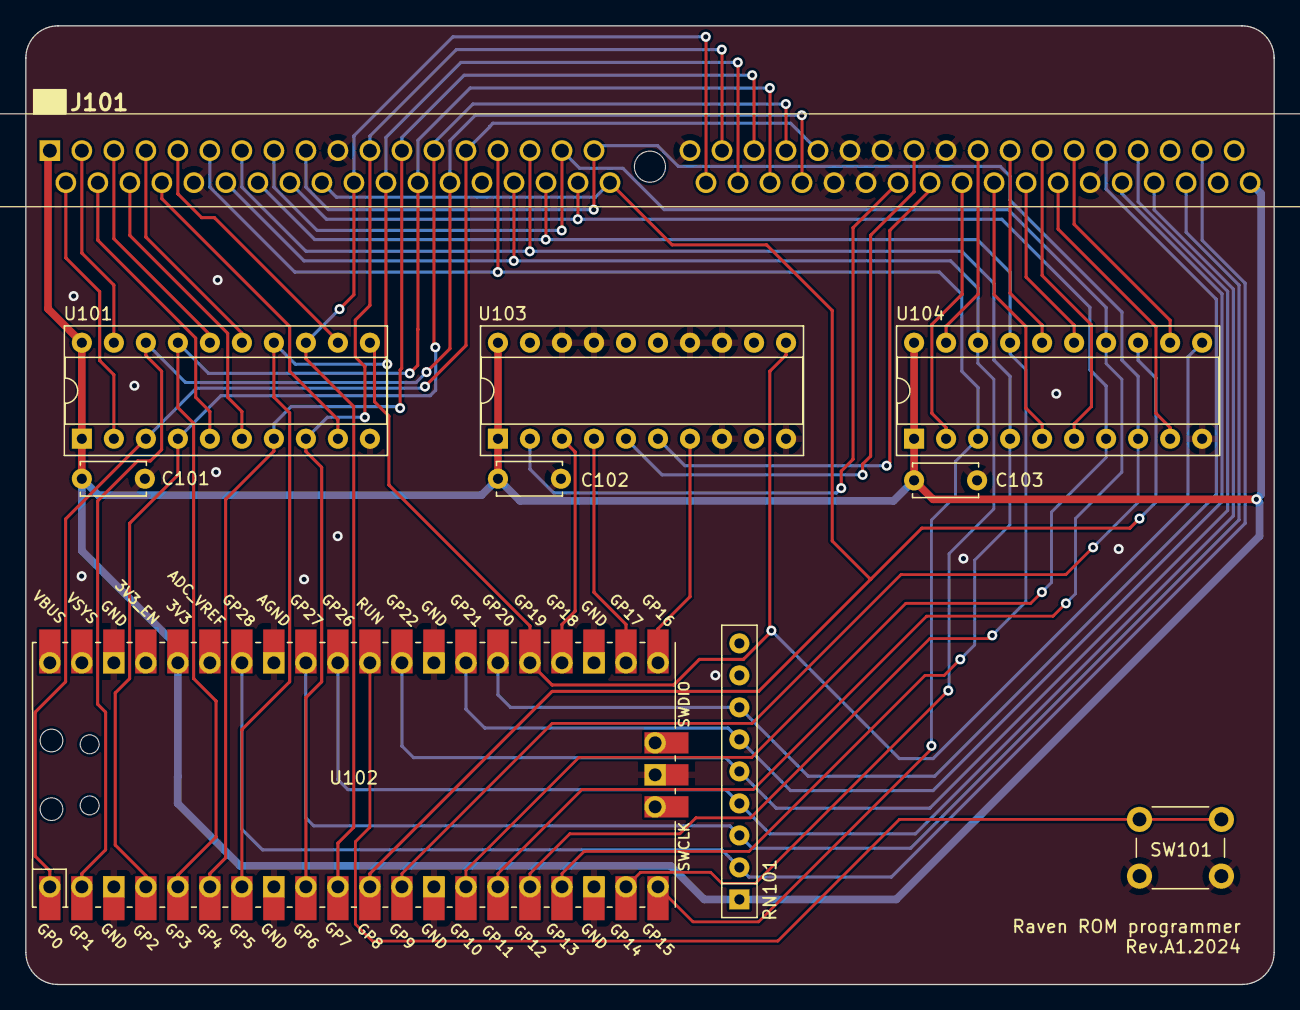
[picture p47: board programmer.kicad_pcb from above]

Board: 2 copper layers, 99.1 x 76.1 mm, 10 parts (0 on the bottom side), 48 nets.

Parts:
C101, C102, C103: 0.1uF; C_Disc_D5.0mm_W2.5mm_P5.00mm
J101: SIMM72; SIMM72_v_lpol
RN101: 8x10K; R_Array_SIP9
SW101: SW_Push_PCB_THT; SW_PUSH_6mm_H4.3mm
U101, U103, U104: 74HC273; DIP-20_W7.62mm_Socket
U102: RPico

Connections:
+3.3V: C101.1, C102.1, C103.1, J101.1 (VCC), J101.72 (VCC), RN101.1 (common), U101.1 (~Mr), U101.20 (VCC), U102.36 (3V3), U103.1 (~Mr), U103.20 (VCC), U104.1 (~Mr), U104.20 (VCC)
A0: J101.2 (A0), U101.2 (Q0)
A1: J101.3 (A1), U101.19 (Q7)
A2: J101.4 (A2), U101.5 (Q1)
A3: J101.5 (A3), U101.16 (Q6)
A4: J101.6 (A4), U101.6 (Q2)
A5: J101.7 (A5), U101.15 (Q5)
A6: J101.8 (A6), U101.9 (Q3)
A7: J101.9 (A7), U101.12 (Q4)
A8: J101.61 (A8), U104.12 (Q4)
A9: J101.60 (A9), U104.9 (Q3)
A10: J101.59 (A10), U104.6 (Q2)
A11: J101.58 (A11), U104.15 (Q5)
A12: J101.57 (A12), U104.16 (Q6)
A13: J101.56 (A13), U104.5 (Q1)
A14: J101.55 (A14), U104.19 (Q7)
A15: J101.54 (A15), U104.2 (Q0)
A16: J101.52 (A16), U103.6 (Q2)
A17: J101.51 (A17), U103.5 (Q1)
A18: J101.50 (A18), U103.2 (Q0)
AD0: J101.27 (D16), J101.45 (D0), U101.3 (D0), U102.1 (GPIO0)
AD1: J101.26 (D17), J101.44 (D1), U101.18 (D7), U102.2 (GPIO1)
AD2: J101.25 (D18), J101.43 (D2), U101.4 (D1), U102.4 (GPIO2)
AD3: J101.24 (D19), J101.42 (D3), U101.17 (D6), U102.5 (GPIO3)
AD4: J101.23 (D20), J101.41 (D4), U101.7 (D2), U102.6 (GPIO4)
AD5: J101.22 (D21), J101.40 (D5), U101.14 (D5), U102.7 (GPIO5)
AD6: J101.21 (D22), J101.39 (D6), U101.8 (D3), U102.9 (GPIO6)
AD7: J101.20 (D23), J101.38 (D7), U101.13 (D4), U102.10 (GPIO7)
AD8: J101.18 (D24), J101.36 (D8), U102.11 (GPIO8), U104.13 (D4)
AD9: J101.17 (D25), J101.35 (D9), U102.12 (GPIO9), U104.8 (D3)
AD10: J101.16 (D26), J101.34 (D10), U102.14 (GPIO10), U104.7 (D2)
AD11: J101.15 (D27), J101.33 (D11), U102.15 (GPIO11), U104.14 (D5)
AD12: J101.14 (D28), J101.32 (D12), U102.16 (GPIO12), U104.17 (D6)
AD13: J101.13 (D29), J101.31 (D13), U102.17 (GPIO13), U104.4 (D1)
AD14: J101.12 (D30), J101.30 (D14), U102.19 (GPIO14), U104.18 (D7)
AD15: J101.11 (D31), J101.29 (D15), U102.20 (GPIO15), U104.3 (D0)
AD16: U102.21 (GPIO16), U103.7 (D2)
AD17: U102.22 (GPIO17), U103.4 (D1)
AD18: U102.24 (GPIO18), U103.3 (D0)
ALE: U101.11 (Cp), U102.25 (GPIO19), U103.11 (Cp), U104.11 (Cp)
GND: C101.2, C102.2, C103.2, J101.10 (GND), J101.19 (GND), J101.28 (GND), J101.37 (GND), J101.46 (GND), J101.47 (A21), J101.48 (A20), J101.49 (A19), J101.53 (GND), J101.62 (GND), SW101.2, U101.10 (GND), U102.3 (GND), U102.8 (GND), U102.13 (GND), U102.18 (GND), U102.23 (GND), U102.28 (GND), U102.33 (AGND), U102.38 (GND), U102.42 (GND), U103.8 (D3), U103.10 (GND), U103.13 (D4), U103.14 (D5), U103.17 (D6), U103.18 (D7), U104.10 (GND)
unnamed: SW101.1, U102.30 (RUN)
~DBS0: J101.63 (~BS0), RN101.7 (R6), U102.26 (GPIO20)
~DBS1: J101.64 (~BS1), RN101.6 (R5), U102.27 (GPIO21)
~DBS2: J101.65 (~BS2), RN101.5 (R4), U102.29 (GPIO22)
~DBS3: J101.66 (~BS3), RN101.4 (R3), U102.31 (GPIO26_ADC0)
~DRD: J101.68 (~OE), RN101.3 (R2), U102.32 (GPIO27_ADC1)
~DWR: J101.69 (~WE), RN101.2 (R1), U102.34 (GPIO28_ADC2)

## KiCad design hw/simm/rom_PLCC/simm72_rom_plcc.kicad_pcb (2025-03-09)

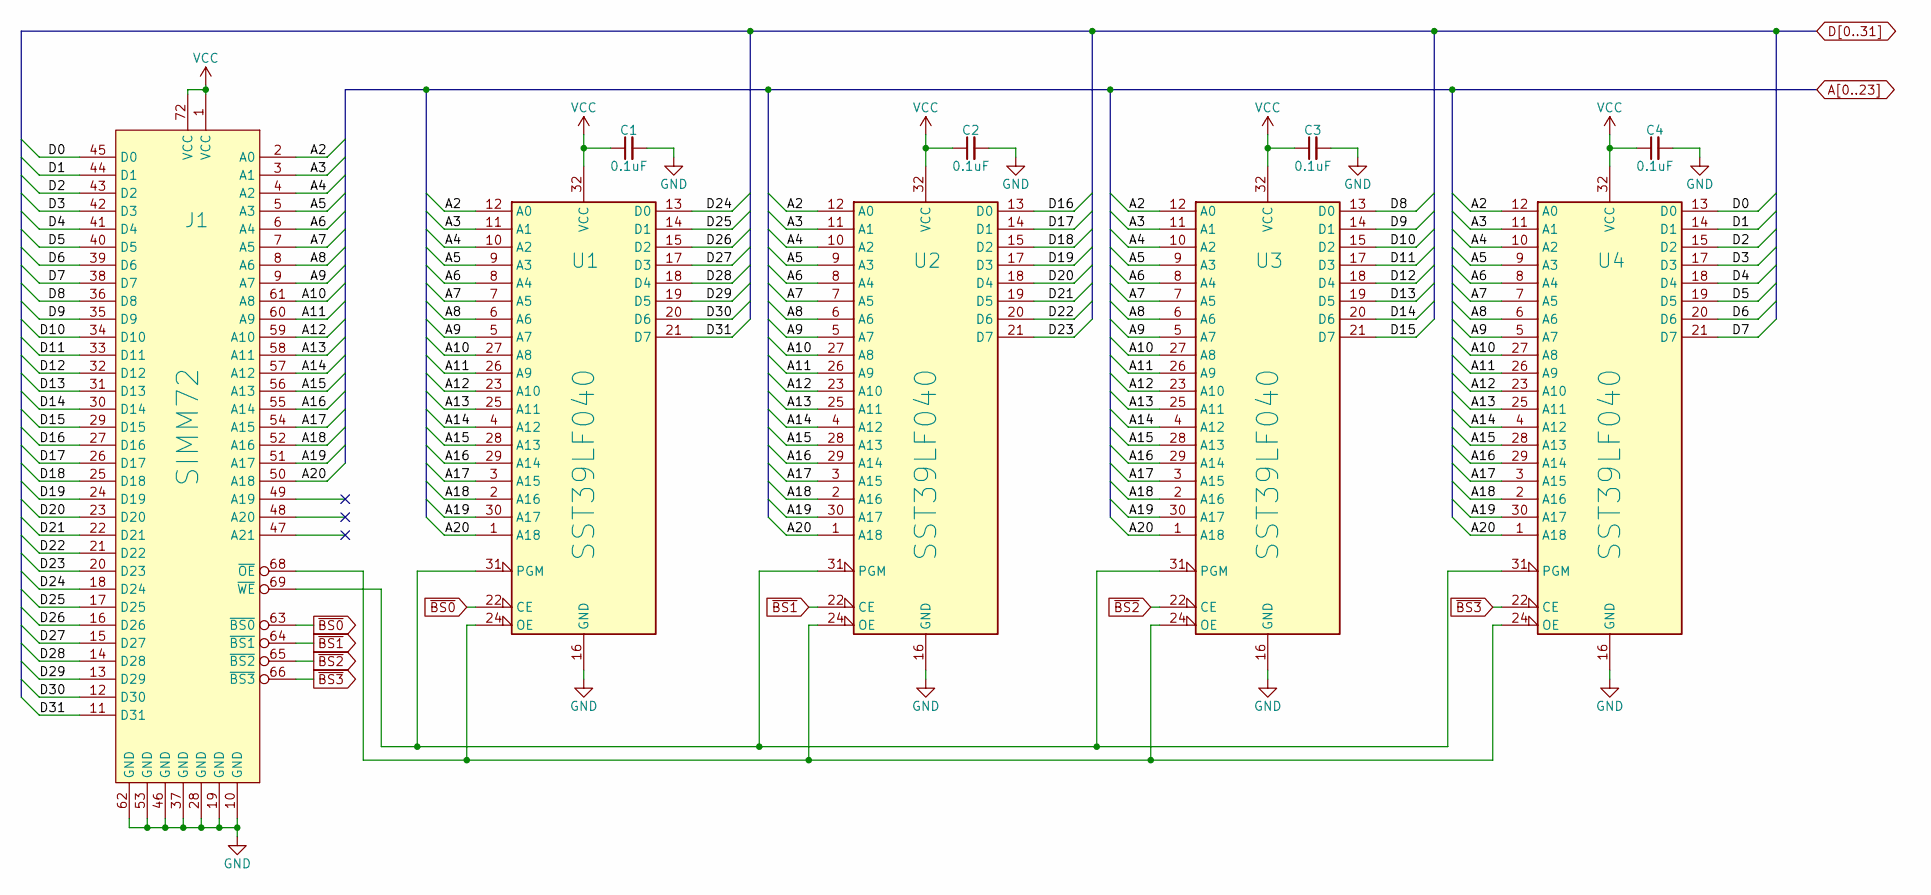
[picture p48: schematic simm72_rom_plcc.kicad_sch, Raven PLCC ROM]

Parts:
C1, C2, C3, C4: 0.1uF; C_1206_3216Metric_Pad1.33x1.80mm_HandSolder; Manufacturer_Part_Number C1206C104K5RACTU
J1: SIMM72; SIMM72_edge
U1, U2, U3, U4: SST39LF040; PLCC-32_THT-Socket; Manufacturer_Part_Number SST39LF040-55-4C-NHE-T

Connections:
A2: J1.2 (A0), U1.12 (A0), U2.12 (A0), U3.12 (A0), U4.12 (A0)
A3: J1.3 (A1), U1.11 (A1), U2.11 (A1), U3.11 (A1), U4.11 (A1)
A4: J1.4 (A2), U1.10 (A2), U2.10 (A2), U3.10 (A2), U4.10 (A2)
A5: J1.5 (A3), U1.9 (A3), U2.9 (A3), U3.9 (A3), U4.9 (A3)
A6: J1.6 (A4), U1.8 (A4), U2.8 (A4), U3.8 (A4), U4.8 (A4)
A7: J1.7 (A5), U1.7 (A5), U2.7 (A5), U3.7 (A5), U4.7 (A5)
A8: J1.8 (A6), U1.6 (A6), U2.6 (A6), U3.6 (A6), U4.6 (A6)
A9: J1.9 (A7), U1.5 (A7), U2.5 (A7), U3.5 (A7), U4.5 (A7)
A10: J1.61 (A8), U1.27 (A8), U2.27 (A8), U3.27 (A8), U4.27 (A8)
A11: J1.60 (A9), U1.26 (A9), U2.26 (A9), U3.26 (A9), U4.26 (A9)
A12: J1.59 (A10), U1.23 (A10), U2.23 (A10), U3.23 (A10), U4.23 (A10)
A13: J1.58 (A11), U1.25 (A11), U2.25 (A11), U3.25 (A11), U4.25 (A11)
A14: J1.57 (A12), U1.4 (A12), U2.4 (A12), U3.4 (A12), U4.4 (A12)
A15: J1.56 (A13), U1.28 (A13), U2.28 (A13), U3.28 (A13), U4.28 (A13)
A16: J1.55 (A14), U1.29 (A14), U2.29 (A14), U3.29 (A14), U4.29 (A14)
A17: J1.54 (A15), U1.3 (A15), U2.3 (A15), U3.3 (A15), U4.3 (A15)
A18: J1.52 (A16), U1.2 (A16), U2.2 (A16), U3.2 (A16), U4.2 (A16)
A19: J1.51 (A17), U1.30 (A17), U2.30 (A17), U3.30 (A17), U4.30 (A17)
A20: J1.50 (A18), U1.1 (A18), U2.1 (A18), U3.1 (A18), U4.1 (A18)
D0: J1.45 (D0), U4.13 (D0)
D1: J1.44 (D1), U4.14 (D1)
D2: J1.43 (D2), U4.15 (D2)
D3: J1.42 (D3), U4.17 (D3)
D4: J1.41 (D4), U4.18 (D4)
D5: J1.40 (D5), U4.19 (D5)
D6: J1.39 (D6), U4.20 (D6)
D7: J1.38 (D7), U4.21 (D7)
D8: J1.36 (D8), U3.13 (D0)
D9: J1.35 (D9), U3.14 (D1)
D10: J1.34 (D10), U3.15 (D2)
D11: J1.33 (D11), U3.17 (D3)
D12: J1.32 (D12), U3.18 (D4)
D13: J1.31 (D13), U3.19 (D5)
D14: J1.30 (D14), U3.20 (D6)
D15: J1.29 (D15), U3.21 (D7)
D16: J1.27 (D16), U2.13 (D0)
D17: J1.26 (D17), U2.14 (D1)
D18: J1.25 (D18), U2.15 (D2)
D19: J1.24 (D19), U2.17 (D3)
D20: J1.23 (D20), U2.18 (D4)
D21: J1.22 (D21), U2.19 (D5)
D22: J1.21 (D22), U2.20 (D6)
D23: J1.20 (D23), U2.21 (D7)
D24: J1.18 (D24), U1.13 (D0)
D25: J1.17 (D25), U1.14 (D1)
D26: J1.16 (D26), U1.15 (D2)
D27: J1.15 (D27), U1.17 (D3)
D28: J1.14 (D28), U1.18 (D4)
D29: J1.13 (D29), U1.19 (D5)
D30: J1.12 (D30), U1.20 (D6)
D31: J1.11 (D31), U1.21 (D7)
GND: C1.2, C2.2, C3.2, C4.2, J1.10 (GND), J1.19 (GND), J1.28 (GND), J1.37 (GND), J1.46 (GND), J1.53 (GND), J1.62 (GND), U1.16 (GND), U2.16 (GND), U3.16 (GND), U4.16 (GND)
unnamed: J1.68 (~OE), U1.24 (OE), U2.24 (OE), U3.24 (OE), U4.24 (OE)
unnamed: J1.69 (~WE), U1.31 (PGM), U2.31 (PGM), U3.31 (PGM), U4.31 (PGM)
VCC: C1.1, C2.1, C3.1, C4.1, J1.1 (VCC), J1.72 (VCC), U1.32 (VCC), U2.32 (VCC), U3.32 (VCC), U4.32 (VCC)
~BS0: J1.63 (~BS0), U1.22 (CE)
~BS1: J1.64 (~BS1), U2.22 (CE)
~BS2: J1.65 (~BS2), U3.22 (CE)
~BS3: J1.66 (~BS3), U4.22 (CE)

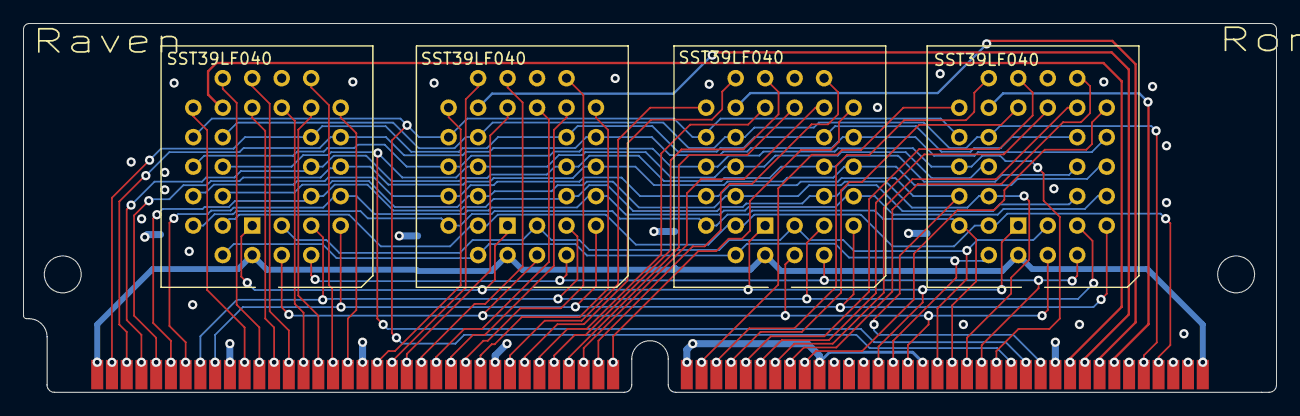
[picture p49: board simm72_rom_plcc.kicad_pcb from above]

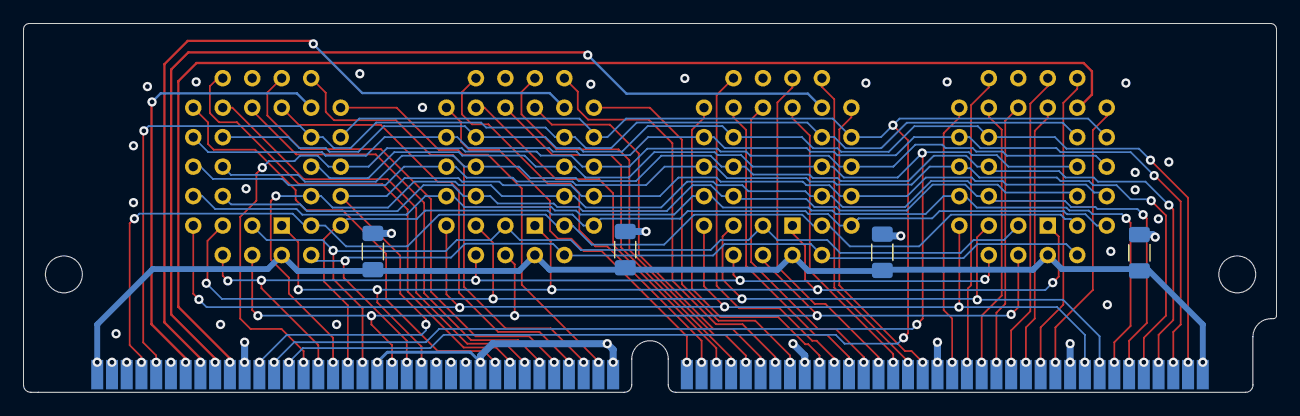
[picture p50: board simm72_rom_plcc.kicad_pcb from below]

Board: 4 copper layers, 108.0 x 31.8 mm, 9 parts (4 on the bottom side), 59 nets.

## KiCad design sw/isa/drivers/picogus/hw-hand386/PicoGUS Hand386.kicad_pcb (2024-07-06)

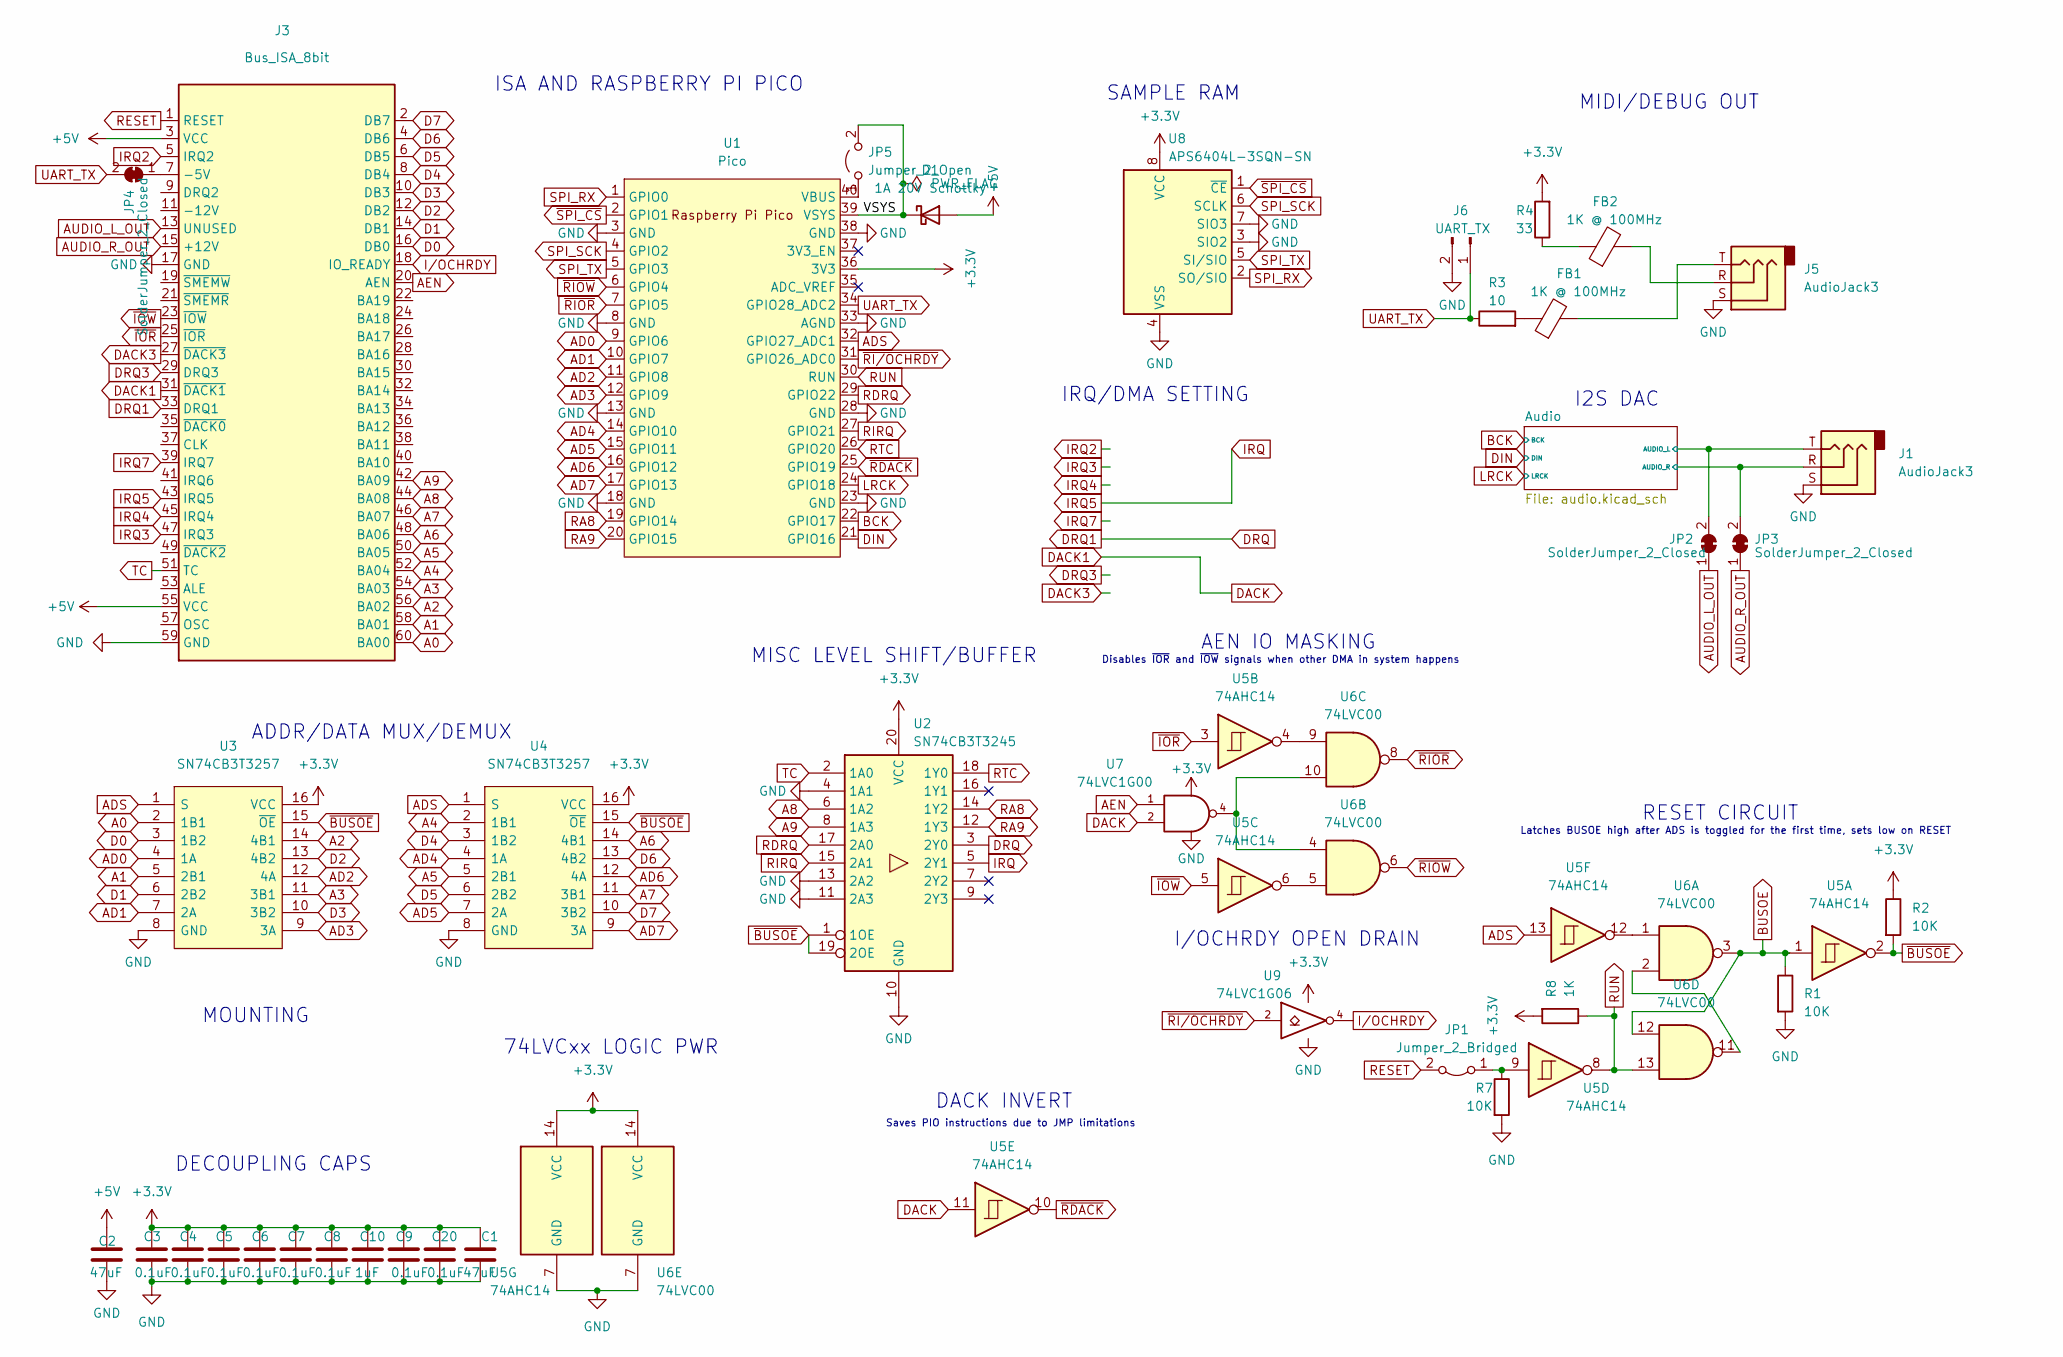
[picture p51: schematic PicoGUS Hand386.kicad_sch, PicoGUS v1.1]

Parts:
C1, C2: 47uF; C_1206_3216Metric
C3, C4, C5, C6, C7, C8, C9, C20: 0.1uF; C_0402_1005Metric
C10: 1uF; C_0402_1005Metric
D1: 1A 20V Schottky; D_SOD-123
FB1, FB2: 1K @ 100MHz; L_0603_1608Metric
J1: AudioJack3; PJ-321A
J3: Bus_ISA_8bit; EDGE-60
J5: AudioJack3; PJ-231F-4A
J6: UART_TX; PinHeader_1x02_P2.54mm_Vertical
JP1: Jumper_2_Bridged; PinHeader_1x02_P2.54mm_Vertical
JP2, JP3, JP4: SolderJumper_2_Closed; SolderJumper-2_P1.3mm_Bridged_RoundedPad1.0x1.5mm-nomask
JP5: Jumper_2_Open; PinHeader_1x02_P2.54mm_Vertical
R1, R2, R7: 10K; R_0402_1005Metric
R3: 10; R_0805_2012Metric
R4: 33; R_0805_2012Metric
R8: 1K; R_0402_1005Metric
U1: Pico; RPi_Pico_SMD_TH
U2: SN74CB3T3245; TSSOP-20_4.4x6.5mm_P0.65mm
U3, U4: SN74CB3T3257; TSSOP-16_4.4x5mm_P0.65mm; Manufacturer_Part_Number 74FST3257DR2G; Mouser Part Number 863-74FST3257DR2G
U5: 74AHC14; TSSOP-14_4.4x5mm_P0.65mm
U6: 74LVC00; TSSOP-14_4.4x5mm_P0.65mm
U7: 74LVC1G00; SOT-23-5
U8: APS6404L-3SQN-SN; SOIC-8_3.9x4.9mm_P1.27mm
U9: 74LVC1G06; SOT-23-5

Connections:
+5V: C2.1, D1.2 (A), J3.3 (VCC), J3.55 (VCC)
/Audio/AUDIO_L: J1.T, JP2.2 (B); also elsewhere on the board
/Audio/AUDIO_R: J1.R, JP3.2 (B); also elsewhere on the board
/VSYS: D1.1 (K), JP5.2 (B), U1.39 (VSYS)
A0: J3.60 (BA00), U3.2 (1B1)
A1: J3.58 (BA01), U3.5 (2B1)
A2: J3.56 (BA02), U3.14 (4B1)
A3: J3.54 (BA03), U3.11 (3B1)
A4: J3.52 (BA04), U4.2 (1B1)
A5: J3.50 (BA05), U4.5 (2B1)
A6: J3.48 (BA06), U4.14 (4B1)
A7: J3.46 (BA07), U4.11 (3B1)
A8: J3.44 (BA08), U2.6 (1A2)
A9: J3.42 (BA09), U2.8 (1A3)
AD0: U1.9 (GPIO6), U3.4 (1A)
AD1: U1.10 (GPIO7), U3.7 (2A)
AD2: U1.11 (GPIO8), U3.12 (4A)
AD3: U1.12 (GPIO9), U3.9 (3A)
AD4: U1.14 (GPIO10), U4.4 (1A)
AD5: U1.15 (GPIO11), U4.7 (2A)
AD6: U1.16 (GPIO12), U4.12 (4A)
AD7: U1.17 (GPIO13), U4.9 (3A)
ADS: U1.32 (GPIO27_ADC1), U3.1 (S), U4.1 (S), U5.13
AEN: J3.20 (AEN), U7.1
AUDIO_L_OUT: J3.13 (UNUSED), JP2.1 (A)
AUDIO_R_OUT: J3.15 (+12V), JP3.1 (A)
BCK: U1.22 (GPIO17); also elsewhere on the board
BUSOE: R1.1, U5.1, U6.3, U6.12
D0: J3.16 (DB0), U3.3 (1B2)
D1: J3.14 (DB1), U3.6 (2B2)
D2: J3.12 (DB2), U3.13 (4B2)
D3: J3.10 (DB3), U3.10 (3B2)
D4: J3.8 (DB4), U4.3 (1B2)
D5: J3.6 (DB5), U4.6 (2B2)
D6: J3.4 (DB6), U4.13 (4B2)
D7: J3.2 (DB7), U4.10 (3B2)
DACK: J3.31 (~DACK1), U5.11, U7.2
DACK3: J3.27 (~DACK3)
DIN: U1.21 (GPIO16); also elsewhere on the board
DRQ: J3.33 (DRQ1), U2.3 (2Y0)
DRQ3: J3.29 (DRQ3)
GND: C1.2, C2.2, C3.2, C4.2, C5.2, C6.2, C7.2, C8.2, C9.2, C10.2, C20.2, J1.S, J3.17 (GND), J3.59 (GND), J5.S, J6.2, R1.2, R7.2, U1.3 (GND), U1.8 (GND), U1.13 (GND), U1.18 (GND), U1.23 (GND), U1.28 (GND), U1.33 (AGND), U1.38 (GND), U2.4 (1A1), U2.10 (GND), U2.11 (2A3), U2.13 (2A2), U3.8 (GND), U4.8 (GND), U5.7 (GND), U6.7 (GND), U7.3 (GND), U8.3 (SIO2), U8.4 (VSS), U8.7 (SIO3), U9.3 (GND); also elsewhere on the board
IRQ: J3.43 (IRQ5), U2.5 (2Y1)
IRQ2: J3.5 (IRQ2)
IRQ3: J3.47 (IRQ3)
IRQ4: J3.45 (IRQ4)
IRQ7: J3.39 (IRQ7)
I/OCHRDY: J3.18 (IO_READY), U9.4
LRCK: U1.24 (GPIO18); also elsewhere on the board
unnamed: FB1.1, R3.2
unnamed: FB1.2, J5.T
unnamed: FB2.1, R4.1
unnamed: FB2.2, J5.R
unnamed: J3.7 (-5V), JP4.1 (A)
unnamed: JP1.1 (A), R7.1, U5.9
unnamed: JP5.1 (A), U1.40 (VBUS)
unnamed: U5.4, U6.9
unnamed: U5.6, U6.5
unnamed: U5.12, U6.1
unnamed: U6.4, U6.10, U7.4
unnamed: U6.2, U6.11
RA8: U1.19 (GPIO14), U2.14 (1Y2)
RA9: U1.20 (GPIO15), U2.12 (1Y3)
RDRQ: U1.29 (GPIO22), U2.17 (2A0)
RESET: J3.1 (RESET), JP1.2 (B)
RIRQ: U1.27 (GPIO21), U2.15 (2A1)
RTC: U1.26 (GPIO20), U2.18 (1Y0)
RUN: R8.1, U1.30 (RUN), U5.8, U6.13
SPI_RX: U1.1 (GPIO0), U8.2 (SO/SIO)
SPI_SCK: U1.4 (GPIO2), U8.6 (SCLK)
SPI_TX: U1.5 (GPIO3), U8.5 (SI/SIO)
TC: J3.51 (TC), U2.2 (1A0)
UART_TX: J6.1, JP4.2 (B), R3.1, U1.34 (GPIO28_ADC2)
~BUSOE: R2.2, U2.1 (1OE), U2.19 (2OE), U3.15 (~OE), U4.15 (~OE), U5.2
~IOR: J3.25 (~IOR), U5.3
~IOW: J3.23 (~IOW), U5.5
~RDACK: U1.25 (GPIO19), U5.10
~RIOR: U1.7 (GPIO5), U6.8
~RIOW: U1.6 (GPIO4), U6.6
~RI/OCHRDY: U1.31 (GPIO26_ADC0), U9.2
~SPI_CS: U1.2 (GPIO1), U8.1 (~CE)

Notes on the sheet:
Saves PIO instructions due to JMP limitations
DECOUPLING CAPS
I2S DAC
Disables ~{IOR} and ~{IOW} signals when other DMA in system happens
Latches BUSOE high after ADS is toggled for the first time, sets low on RESET
MIDI/DEBUG OUT
MOUNTING
MISC LEVEL SHIFT/BUFFER
IRQ/DMA SETTING
DACK INVERT
ADDR/DATA MUX/DEMUX
SAMPLE RAM
AEN IO MASKING
ISA AND RASPBERRY PI PICO
RESET CIRCUIT
I/OCHRDY OPEN DRAIN
74LVCxx LOGIC PWR

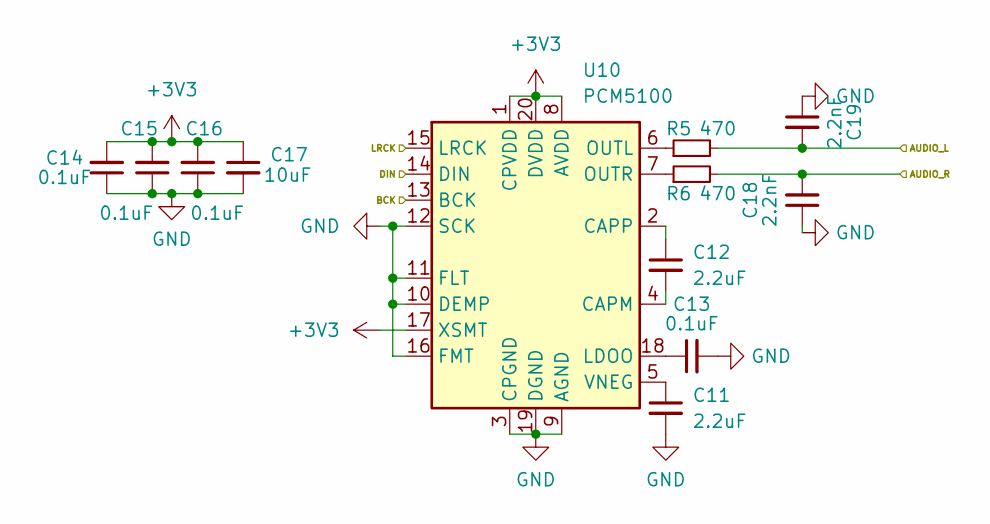
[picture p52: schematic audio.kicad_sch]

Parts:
C11, C12: 2.2uF; C_0402_1005Metric
C13, C14, C15, C16: 0.1uF; C_0402_1005Metric
C17: 10uF; C_0603_1608Metric
C18, C19: 2.2nF; C_0402_1005Metric
R5, R6: 470; R_0402_1005Metric
U10: PCM5100; TSSOP-20_4.4x6.5mm_P0.65mm

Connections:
/Audio/AUDIO_L: C19.2, R5.2; also elsewhere on the board
/Audio/AUDIO_R: C18.2, R6.2; also elsewhere on the board
BCK: U10.13 (BCK); also elsewhere on the board
DIN: U10.14 (DIN); also elsewhere on the board
GND: C11.2, C13.2, C14.1, C15.1, C16.1, C17.2, C18.1, C19.1, U10.3 (CPGND), U10.9 (AGND), U10.10 (DEMP), U10.11 (FLT), U10.12 (SCK), U10.16 (FMT), U10.19 (DGND); also elsewhere on the board
LRCK: U10.15 (LRCK); also elsewhere on the board
unnamed: C12.2, U10.4 (CAPM)
unnamed: C12.1, U10.2 (CAPP)
unnamed: C13.1, U10.18 (LDOO)
unnamed: R5.1, U10.6 (OUTL)
unnamed: R6.1, U10.7 (OUTR)
unnamed: C11.1, U10.5 (VNEG)

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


Board: 4 copper layers, 29.2 x 75.2 mm, 53 parts (3 on the bottom side), 82 nets.

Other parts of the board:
JLCTOOLING1, JLCTOOLING2, JLCTOOLING3: JLCPCB-tooling

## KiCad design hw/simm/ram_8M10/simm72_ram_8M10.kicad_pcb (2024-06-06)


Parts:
C1, C2, C3, C4: 0.1uF; C_1206_3216Metric_Pad1.33x1.80mm_HandSolder; Manufacturer_Part_Number C1206C104K5RACTU
IC1, IC2: IS61WV204816BLL-10TLI; SOP50P2000X120-48N; Mouser Part Number 870-WV204816BLL10TLI
J1: SIMM72; SIMM72_edge

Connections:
A2: IC1.5 (A0), IC2.5 (A0), J1.2 (A0)
A3: IC1.4 (A1), IC2.4 (A1), J1.3 (A1)
A4: IC1.3 (A2), IC2.3 (A2), J1.4 (A2)
A5: IC1.2 (A3), IC2.2 (A3), J1.5 (A3)
A6: IC1.1 (A4), IC2.1 (A4), J1.6 (A4)
A7: IC1.48 (A5), IC2.48 (A5), J1.7 (A5)
A8: IC1.47 (A6), IC2.47 (A6), J1.8 (A6)
A9: IC1.46 (A7), IC2.46 (A7), J1.9 (A7)
A10: IC1.45 (A8), IC2.45 (A8), J1.61 (A8)
A11: IC1.30 (A9), IC2.30 (A9), J1.60 (A9)
A12: IC1.29 (A10), IC2.29 (A10), J1.59 (A10)
A13: IC1.28 (A11), IC2.28 (A11), J1.58 (A11)
A14: IC1.27 (A12), IC2.27 (A12), J1.57 (A12)
A15: IC1.26 (A13), IC2.26 (A13), J1.56 (A13)
A16: IC1.25 (A14), IC2.25 (A14), J1.55 (A14)
A17: IC1.24 (A15), IC2.24 (A15), J1.54 (A15)
A18: IC1.23 (A16), IC2.23 (A16), J1.52 (A16)
A19: IC1.22 (A17), IC2.22 (A17), J1.51 (A17)
A20: IC1.21 (A18), IC2.21 (A18), J1.50 (A18)
A21: IC1.20 (A19), IC2.20 (A19), J1.49 (A19)
A22: IC1.31 (A20), IC2.31 (A20), J1.48 (A20)
D0: IC1.8 (I/O0), J1.45 (D0)
D1: IC1.9 (I/O1), J1.44 (D1)
D2: IC1.10 (I/O2), J1.43 (D2)
D3: IC1.11 (I/O3), J1.42 (D3)
D4: IC1.14 (I/O4), J1.41 (D4)
D5: IC1.15 (I/O5), J1.40 (D5)
D6: IC1.16 (I/O6), J1.39 (D6)
D7: IC1.17 (I/O7), J1.38 (D7)
D8: IC1.32 (I/O8), J1.36 (D8)
D9: IC1.33 (I/O9), J1.35 (D9)
D10: IC1.34 (I/O10), J1.34 (D10)
D11: IC1.35 (I/O11), J1.33 (D11)
D12: IC1.38 (I/O12), J1.32 (D12)
D13: IC1.39 (I/O13), J1.31 (D13)
D14: IC1.40 (I/O14), J1.30 (D14)
D15: IC1.41 (I/O15), J1.29 (D15)
D16: IC2.8 (I/O0), J1.27 (D16)
D17: IC2.9 (I/O1), J1.26 (D17)
D18: IC2.10 (I/O2), J1.25 (D18)
D19: IC2.11 (I/O3), J1.24 (D19)
D20: IC2.14 (I/O4), J1.23 (D20)
D21: IC2.15 (I/O5), J1.22 (D21)
D22: IC2.16 (I/O6), J1.21 (D22)
D23: IC2.17 (I/O7), J1.20 (D23)
D24: IC2.32 (I/O8), J1.18 (D24)
D25: IC2.33 (I/O9), J1.17 (D25)
D26: IC2.34 (I/O10), J1.16 (D26)
D27: IC2.35 (I/O11), J1.15 (D27)
D28: IC2.38 (I/O12), J1.14 (D28)
D29: IC2.39 (I/O13), J1.13 (D29)
D30: IC2.40 (I/O14), J1.12 (D30)
D31: IC2.41 (I/O15), J1.11 (D31)
GND: C1.2, C2.2, C3.2, C4.2, IC1.7 (CS#), IC1.13 (VSS_1), IC1.37 (VSS_2), IC2.7 (CS#), IC2.13 (VSS_1), IC2.37 (VSS_2), J1.10 (GND), J1.19 (GND), J1.28 (GND), J1.37 (GND), J1.46 (GND), J1.53 (GND), J1.62 (GND)
VCC: C1.1, C2.1, C3.1, C4.1, IC1.12 (VDD_1), IC1.36 (VDD_2), IC2.12 (VDD_1), IC2.36 (VDD_2), J1.1 (VCC), J1.72 (VCC)
~BS0: IC2.43 (UB#), J1.63 (~BS0)
~BS1: IC2.42 (LB#), J1.64 (~BS1)
~BS2: IC1.43 (UB#), J1.65 (~BS2)
~BS3: IC1.42 (LB#), J1.66 (~BS3)
~OE: IC1.44 (OE#), IC2.44 (OE#), J1.68 (~OE)
~WE: IC1.18 (WE#), IC2.18 (WE#), J1.69 (~WE)


Board: 4 copper layers, 108.0 x 31.8 mm, 7 parts (0 on the bottom side), 61 nets.

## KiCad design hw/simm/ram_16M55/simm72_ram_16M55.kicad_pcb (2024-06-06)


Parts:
C1, C2: 0.1uF; C_1206_3216Metric_Pad1.33x1.80mm_HandSolder; Manufacturer_Part_Number C1206C104K5RACTU
IC1, IC2: AS6C6416-55TIN; SOP50P2000X120-48N; Mouser Part Number 913-AS6C6416-55TIN
J1: SIMM72; SIMM72_edge

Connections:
A2: IC1.25 (A0), IC2.25 (A0), J1.2 (A0)
A3: IC1.24 (A1), IC2.24 (A1), J1.3 (A1)
A4: IC1.23 (A2), IC2.23 (A2), J1.4 (A2)
A5: IC1.22 (A3), IC2.22 (A3), J1.5 (A3)
A6: IC1.21 (A4), IC2.21 (A4), J1.6 (A4)
A7: IC1.20 (A5), IC2.20 (A5), J1.7 (A5)
A8: IC1.19 (A6), IC2.19 (A6), J1.8 (A6)
A9: IC1.18 (A7), IC2.18 (A7), J1.9 (A7)
A10: IC1.8 (A8), IC2.8 (A8), J1.61 (A8)
A11: IC1.7 (A9), IC2.7 (A9), J1.60 (A9)
A12: IC1.6 (A10), IC2.6 (A10), J1.59 (A10)
A13: IC1.5 (A11), IC2.5 (A11), J1.58 (A11)
A14: IC1.4 (A12), IC2.4 (A12), J1.57 (A12)
A15: IC1.3 (A13), IC2.3 (A13), J1.56 (A13)
A16: IC1.2 (A14), IC2.2 (A14), J1.55 (A14)
A17: IC1.1 (A15), IC2.1 (A15), J1.54 (A15)
A18: IC1.48 (A16), IC2.48 (A16), J1.52 (A16)
A19: IC1.17 (A17), IC2.17 (A17), J1.51 (A17)
A20: IC1.16 (A18), IC2.16 (A18), J1.50 (A18)
A21: IC1.9 (A19), IC2.9 (A19), J1.49 (A19)
A22: IC1.10 (A20), IC2.10 (A20), J1.48 (A20)
A23: IC1.13 (A21), IC2.13 (A21), J1.47 (A21)
D0: IC2.29 (DQ0), J1.45 (D0)
D1: IC2.31 (DQ1), J1.44 (D1)
D2: IC2.33 (DQ2), J1.43 (D2)
D3: IC2.35 (DQ3), J1.42 (D3)
D4: IC2.38 (DQ4), J1.41 (D4)
D5: IC2.40 (DQ5), J1.40 (D5)
D6: IC2.42 (DQ6), J1.39 (D6)
D7: IC2.44 (DQ7), J1.38 (D7)
D8: IC2.30 (DQ8), J1.36 (D8)
D9: IC2.32 (DQ9), J1.35 (D9)
D10: IC2.34 (DQ10), J1.34 (D10)
D11: IC2.36 (DQ11), J1.33 (D11)
D12: IC2.39 (DQ12), J1.32 (D12)
D13: IC2.41 (DQ13), J1.31 (D13)
D14: IC2.43 (DQ14), J1.30 (D14)
D15: IC2.45 (DQ15/A-1), J1.29 (D15)
D16: IC1.29 (DQ0), J1.27 (D16)
D17: IC1.31 (DQ1), J1.26 (D17)
D18: IC1.33 (DQ2), J1.25 (D18)
D19: IC1.35 (DQ3), J1.24 (D19)
D20: IC1.38 (DQ4), J1.23 (D20)
D21: IC1.40 (DQ5), J1.22 (D21)
D22: IC1.42 (DQ6), J1.21 (D22)
D23: IC1.44 (DQ7), J1.20 (D23)
D24: IC1.30 (DQ8), J1.18 (D24)
D25: IC1.32 (DQ9), J1.17 (D25)
D26: IC1.34 (DQ10), J1.16 (D26)
D27: IC1.36 (DQ11), J1.15 (D27)
D28: IC1.39 (DQ12), J1.14 (D28)
D29: IC1.41 (DQ13), J1.13 (D29)
D30: IC1.43 (DQ14), J1.12 (D30)
D31: IC1.45 (DQ15/A-1), J1.11 (D31)
GND: C1.2, C2.2, IC1.26 (CE#), IC1.27 (VSS_1), IC1.46 (VSS_2), IC2.26 (CE#), IC2.27 (VSS_1), IC2.46 (VSS_2), J1.10 (GND), J1.19 (GND), J1.28 (GND), J1.37 (GND), J1.46 (GND), J1.53 (GND), J1.62 (GND)
VCC: C1.1, C2.1, IC1.12 (CE2), IC1.37 (VCC), IC1.47 (BYTE#), IC2.12 (CE2), IC2.37 (VCC), IC2.47 (BYTE#), J1.1 (VCC), J1.72 (VCC)
~BS0: IC1.14 (UB#), J1.63 (~BS0)
~BS1: IC1.15 (LB#), J1.64 (~BS1)
~BS2: IC2.14 (UB#), J1.65 (~BS2)
~BS3: IC2.15 (LB#), J1.66 (~BS3)
~OE: IC1.28 (OE#), IC2.28 (OE#), J1.68 (~OE)
~WE: IC1.11 (WE#), IC2.11 (WE#), J1.69 (~WE)


Board: 4 copper layers, 108.0 x 31.8 mm, 5 parts (0 on the bottom side), 62 nets.

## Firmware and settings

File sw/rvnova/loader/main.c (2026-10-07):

/*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
 * You should have received a copy of the GNU General Public License
 * along with this program  if not, write to the Free Software
 * Foundation, Inc., 675 Mass Ave, Cambridge, MA 02139, USA.
 *-----------------------------------------------------------------------------*/
#include <tos.h>
#include <stdlib.h>
#include <stdio.h>
#include <stddef.h>
#include <stdint.h>
#include <stdbool.h>
#include <string.h>
#include <mint/cookie.h>
#include <mint/osbind.h>
#include <mint/basepage.h>

#include <linea.h>
extern LINEA *Linea;
extern VDIESC *Vdiesc;
extern FONTS *Fonts;

#include "raven.h"
#include "rvnova.h"
#include "sysutil.h"
#include "vga.h"
#define INI_IMPL
#include "ini.h"


#define USE_XMENU 0

bool w32i_EnableInterleaveMode(void);

static const char* path_root     = "c:";
static const char* path_nova     = "c:\\nova";
static const char* path_auto     = "c:\\auto";
static const char* path_emulator = "auto\\emulator.prg";
static const char* path_vdi		 = "auto\\sta_vdi.prg";
static const char* path_vdibib 	 = "auto\\sta_vdi.bib";
static const char* path_emubib 	 = "auto\\emulator.bib";


static long cpu;
static rvnova_menuinf_t inf;
static ini_t ini;

/*----------------------------------------
	Set small font
----------------------------------------*/
static void font_small(void) {
    FONT_HDR* font;
    linea_init();
    font = Vdiesc->font_ring[1];
    Vdiesc->v_cel_ht = font->frm_hgt;
    Vdiesc->v_cel_wr = Linea->v_lin_wr * font->frm_hgt;
    Vdiesc->v_cel_mx = (Vdiesc->v_rez_hz / font->wcel_wdt) - 1;
    Vdiesc->v_cel_my = (Vdiesc->v_rez_vt / font->frm_hgt) - 1;
    Vdiesc->v_fnt_wd = font->frm_wdt;
    Vdiesc->v_fnt_st = font->ade_lo;
    Vdiesc->v_fnt_nd = font->ade_hi;
    Vdiesc->v_fnt_ad = font->fnt_dta;
    Vdiesc->v_off_ad = font->ch_ofst;
}

static void screen_off(void) {
#if 0
	char tmp[6];
	sprintf(tmp, "\033c%c", '0'+15);	/* bg color */
	(void)Cconws(tmp);
	(void)Cconws("\033E");              /* clear screen */
	sprintf(tmp, "\033b%c", '0'+15);	/* fg color */
	(void)Cconws(tmp);
#endif
}

static void screen_restore(void) {
#if 0
	char tmp[6];
	sprintf(tmp, "\033b%c", '0');		/* fg color */
	(void)Cconws("\033E");              /* clear screen */
	(void)Cconws(tmp);
#endif
}

static void screen_clear(void) {
	(void)Cconws("\033E\r\n");              /* clear screen */
}


/*----------------------------------------
	Driver pre-load
----------------------------------------*/
void drv_preload(void) {
    raven_t* rv = 0;
    if ((Getcookie(C_RAVN, (long*)&rv) == C_FOUND) && rv) {
        /* Nova driver specific VME -> ISA remap */
        if (stricmp(inf.drvpath, "MACH32") == 0) {
            /* driver code references fea00000 */
            /* also fe908000 for register writes (adding 0x8000) to reg number */
            /* VME adapter is supposed to be on ST jumper setting which grounds A22 */
            rv->mmu_Redirect(0xFE900000UL, 0x83000000UL, 0x00100000UL); /* TT Nova Mach32 reg */
            rv->mmu_Redirect(0xFE800000UL, 0x82000000UL, 0x00100000UL); /* TT Nova Mach32 vga */
            rv->mmu_Redirect(0xFEA00000UL, 0x82200000UL, 0x00100000UL); /* TT Nova Mach32 mem0 -> isa2 */
            rv->mmu_Redirect(0xFEB00000UL, 0x82300000UL, 0x00100000UL); /* TT Nova Mach32 mem1 -> isa3 */
        } else if (stricmp(inf.drvpath, "MACH64") == 0) {
            /* --> this is based on guessing and has not been tested <-- */
            /* driver code references fec00000 and fee00000 */
            /* also fe908000 for register writes (adding 0x8000 to reg number )*/
            /* VME adapter is supposed to be on TT jumper setting and this let's A22 */
            /* pass onto the ISA bus instead of forced to GND */
            rv->mmu_Redirect(0xFE900000UL, 0x83000000UL, 0x00100000UL); /* TT Nova Mach64 reg  */
            rv->mmu_Redirect(0xFE800000UL, 0x82000000UL, 0x00100000UL); /* TT Nova Mach64 vga  */
            rv->mmu_Redirect(0xFEA00000UL, 0x82200000UL, 0x00100000UL); /* probably unused */
            rv->mmu_Redirect(0xFEB00000UL, 0x82300000UL, 0x00100000UL); /* probably unused */
            rv->mmu_Redirect(0xFEC00000UL, 0x82400000UL, 0x00100000UL); /* TT Nova Mach64 mem0 -> isa4 */  
            rv->mmu_Redirect(0xFED00000UL, 0x82500000UL, 0x00100000UL); /* TT Nova Mach64 mem1 -> isa5 */
            rv->mmu_Redirect(0xFEE00000UL, 0x82600000UL, 0x00100000UL); /* TT Nova Mach64 mem2 -> isa6 */
            rv->mmu_Redirect(0xFEF00000UL, 0x82700000UL, 0x00100000UL); /* TT Nova Mach64 mem3 -> isa7 */
        } else if (strnicmp(inf.drvpath, "ET4000", 6) == 0) {
            rv->mmu_Invalid( 0xFE900000UL, 0x00100000UL);               /* probably unnecessary */
            rv->mmu_Invalid( 0xFE800000UL, 0x00100000UL);               /* probably unnecessary */
            rv->mmu_Redirect(0xFED00000UL, 0x83000000UL, 0x00100000UL); /* TT Nova ET4000 reg */
            rv->mmu_Redirect(0xFEC00000UL, 0x82000000UL, 0x00100000UL); /* TT Nova ET4000 mem0 -> isa0 */
            rv->mmu_Redirect(0x00D00000UL, 0x83000000UL, 0x00100000UL); /* ST Nova ET4000 reg */
            rv->mmu_Redirect(0x00C00000UL, 0x82000000UL, 0x00100000UL); /* ST Nova ET4000 mem0 -> isa0 */
        }
    }
}

/*----------------------------------------
	Driver post-load
----------------------------------------*/
void drv_postload(void) {
    if (stricmp(inf.drvpath, "ET4000.W32") == 0) {
        ini_t drv_ini;
        if (ini_GetSection(&drv_ini, &ini, "et4000.w32")) {
            if (ini_GetInt(&drv_ini, "interleave", 0)) {
                screen_clear();
                w32i_EnableInterleaveMode();
                screen_clear();
            }
        }
    }
}

/*----------------------------------------
	Patch vdi
----------------------------------------*/
const unsigned char vdi_patch_cache[] = {
    0x30, 0x28, 0x00, 0x88,                 /*      move.w   (0x88,a0),d0    <- rts */
    0xb0, 0x7c, 0x00, 0x14,                 /*      cmp.w    #0x14,d0               */
    0x6d, 0x16,                             /*      blt.b    .1                     */
    0x4e, 0x7a, 0x00, 0x02,                 /*      movec    cacr,d0                */
    0x22, 0x00,                             /*      move.l   d0,d1                  */
    0xc2, 0xbc, 0xff, 0xff, 0xfe, 0xfe,     /*      and.l    #-0x102,d1             */
    0x82, 0xbc, 0x00, 0x00, 0x08, 0x08,     /*      or.l     #0x0808,d1             */
    0x4e, 0x7b, 0x10, 0x02,                 /*      movec    d1,cacr                */
    0x4e, 0x75,                             /* 1:   rts                             */
    0x32, 0x28, 0x00, 0x88,                 /*      move.w   (0x88,a0),d1    <- rts */
    0xb2, 0x7c, 0x00, 0x14,                 /*      cmp.w    #0x14,d1               */
    0x6d, 0x04,                             /*      blt.b    .2,d1                  */
    0x4e, 0x7b, 0x00, 0x02,                 /*      movec    d0,cacr                */
    0x4e, 0x75                              /* 2:   rts                             */
};

void vdi_patch(BASEPAGE* bp) {
    long i;

    /* patch cache controls */
    if (cpu >= 40) {
        for (i=0; i<bp->p_tlen - sizeof(vdi_patch_cache); i+=2) {
            if (memcmp(vdi_patch_cache, &bp->p_tbase[i], sizeof(vdi_patch_cache)) == 0) {
                bp->p_tbase[i +  0] = 0x4e; bp->p_tbase[i +  1] = 0x75; /* rts */
                bp->p_tbase[i + 34] = 0x4e; bp->p_tbase[i + 35] = 0x75; /* rts */
                break;
            }
        }
    }

    /* replace card name from infoline */
    if ((strnicmp(inf.drvpath, "MACH", 4) != 0) && (strnicmp(inf.drvpath, "ET4000", 6) != 0)) {
        /* todo: retrieve rvnova card info */
        /* for now, just get rid of the ET4000 string */
        for (i=0; (i<bp->p_tlen - 16); i++) {
            if (strncmp("NOVA-VDI  Versio", &bp->p_tbase[i], 16) == 0) {
                long slen = strlen(&bp->p_tbase[i]) - 22;
                if (slen > 2) {
                    sprintf(&bp->p_tbase[i+22], "\r\n");
                }
                break;
            }
        }
    }
}

/*----------------------------------------
	Main
----------------------------------------*/

long supermain()
{
    nova_bib_t bib_emu;
	nova_bib_t bib_vdi;
	char fname[128];

    /* todo:
        get boot drive letter and update
        - path_root
        - path_nova
        - path_auto
    */

    /* cookies */
    if (Getcookie(C__CPU, &cpu) != C_FOUND) {
        cpu = 0;
    }

    /* load rvga settings */
    sprintf(fname, "%s\\rvga.inf", path_root);
    if (ini_Load(&ini, fname)) {
        path_nova = ini_GetStr(&ini, "path", path_nova);
    }

	/* load xmenu settings */
	sprintf(fname, "%s\\xmenu.inf", path_auto);
	if (!rvnova_loadinf(&inf, fname)) {
        rvnova_makeinf(&inf);
	}

	/* force settings */
	inf.menuinf.guikey = 3;		/* gui disable unless keypress */
	inf.menuinf.maccel = 0;

	/* early out if disabled */
	if ((inf.drv_enable == 0) || (inf.menuinf.output != 1) || (inf.drvpath[0] == 0)) {
        goto fail;
	}

	/* sta_vdi.bib */
	sprintf(fname, "%s\\%s\\%s", path_nova, inf.drvpath, path_vdibib);
	rvnova_loadbib(&bib_vdi, fname);
	sprintf(fname, "%s\\sta_vdi.bib", path_auto);
	rvnova_savebib(&bib_vdi, fname);
	if (rvnova_findres(&bib_vdi, &inf.vdi_res)) {
		inf.menuinf.resid = inf.vdi_res.i;
	}
	
	/* emulator.bib */
	sprintf(fname, "%s\\%s\\%s", path_nova, inf.drvpath, path_emubib);
	rvnova_loadbib(&bib_emu, fname);
	if (rvnova_findres(&bib_vdi, &inf.drv_res) ) {
		rvnova_copybib(&bib_emu, 0, &bib_vdi, inf.drv_res.i);
	}
	sprintf(fname, "%s\\emulator.bib", path_auto);
	rvnova_savebib(&bib_emu, fname);

	rvnova_freebib(&bib_emu);
	rvnova_freebib(&bib_vdi);

#if USE_XMENU	
	/* save xmenu.inf */
	sprintf(fname, "%s\\xmenu.inf", path_auto);
	if (!rvnova_saveinf(&inf, fname)) {
        goto fail;
	}
#endif

	/* launch driver */
	if (inf.drv_enable) {
        long result;
        /* Card specific hackery before driver has loaded */
        drv_preload();

        /* start driver */
        screen_off();
		sprintf(fname, "%s\\%s\\%s", path_nova, inf.drvpath, path_emulator);
		result = Pexec(PE_LOADGO, fname, "", 0L);
        if (result < 0) {
            goto fail;
        }

		if (inf.vdi_enable) {
            BASEPAGE* bp;

#if USE_XMENU
            /* start xmenu */
			sprintf(fname, "%s\\xmenu.prg", path_nova);
			result = Pexec(PE_LOADGO, fname, "", 0L);
            if (result < 0) {
                goto fail;
            }
			screen_restore();
#else			
			nova_xcb_t* nova = 0;

			/* assign vdi resolution */
			if ((Getcookie(C_NOVA, (long*)&nova) == C_FOUND) && nova) {
				nova->resolution = inf.vdi_res.i;
				/* xmenu.prg calls instxbios(0) at start,
				 * then (1) after detecting cookie and loading bib
				 * then (0) again right before exiting */
				if (nova->p_instxbios) {
					nova->p_instxbios(0);
				}
			}

			/* rename external gdos program according to enable flag */
			if (strlen(inf.menuinf.gdosfile) > 0) {
				char fname_en[64];
				char fname_di[64];
				sprintf(fname_en, "%s\\%s.PRG", path_auto, inf.menuinf.gdosfile);
				strcpy(fname_di, fname_en);
				fname_di[strlen(fname_di)-1] = 0;

				if (inf.menuinf.gdos) {
					if (Fattrib(fname_en, 0, 0) == -33) {
						Frename(0, fname_di, fname_en);
					}
				} else {
					if (Fattrib(fname_en, 0, 0) >= 0) {
						Frename(0, fname_en, fname_di);
					}
				}
			}
#endif			

            /* start vdi */
			sprintf(fname, "%s\\%s\\%s", path_nova, inf.drvpath, path_vdi);
            result = Pexec(PE_LOAD, fname, "", 0L);
            if (result < 0) {
                goto fail;
            }
			bp = (BASEPAGE*)result;
            vdi_patch(bp);
            FlushCache(cpu);
            Cconws("\33p");
            Pexec(PE_GO_FREE, 0, (const void*)bp, 0L);
            Cconws("\33q");

            /* use small console font */
            /*
            font_small();
            screen_clear();
            */
		} else {
			screen_restore();
		}

        /* Card specific hackery after the driver has loaded */
        drv_postload();
	}

    ini_Unload(&ini);
    return 1;
fail:
    ini_Unload(&ini);
    return 0;    
}

int main()
{
	if (Supexec(supermain)) {
/*		Ptermres(_PgmSize, 0); */
	}
	return 0;
}



bool w32i_EnableInterleaveMode(void) {

    /* todo: it would be good if this code first identified that we actually
       have an ET4000/W32i card.
    */

    uint16_t port;
    uint8_t r32, r37;

    /*
    NOTE: The "KEY" must be set in order to write CRTC indices above 18, except indices 33 and
    35, (CRTC 35 is protected by bit 7 of CRTC 11). See Section 5.1.2, Input Status Register Zero for
    definition of "KEY
    */

    /* To set the KEY: write 03 to hercules compatibility registers */
    vga_WritePort(0x3bf, 3);
    /* then set bits 7 and 5 of mode control register to 1,1, e.g.A0 (other bits are don't care) */
    port = (vga_ReadPort(0x3cc) & 1) ? 0x3d8 : 0x3b8;
    vga_WritePort(port, 0xa0);

    /* now enable interleaved memory mode */
    r32 = vga_ReadReg(VGA_REG_CRTC, 0x32);            /* ras/cas conf */
    r37 = vga_ReadReg(VGA_REG_CRTC, 0x37);            /* vsconf2 */

    /* Databook page: 126
    CRTC:37 video system conf2
    bit0 : display memory data bus width
    */
    vga_WriteReg(VGA_REG_CRTC, 0x37, (r37 | 1));

    /* Databook page: 130
     CRTC:32 ras/cas config
     bit7 : memory interleave enable.
     When set to 1 (memory interleave enabled), the chip operates properly only if
     CSW<0> = 0, CSP<0> = 0, and CRTC Indexed Register 37 bit 0 = 1.
    */
    vga_WriteReg(VGA_REG_CRTC, 0x32, ((r32 | (1 << 7)) & 0xFC));
    return true;
}

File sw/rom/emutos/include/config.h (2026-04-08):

/*
 * config.h - default settings
 *
 * When adding a configuration option to this file, you should ensure
 * (via #ifdef) that it can be overridden by entries in localconf.h.
 * Defines that should *not* be overridden should appear in sysconf.h
 * (or deskconf.h if they apply to EmuDesk).
 *
 * Copyright (C) 2001-2025 The EmuTOS development team
 *
 * Authors:
 *  MAD     Martin Doering
 *  LVL     Laurent Vogel
 *  VRI     Vincent Rivière
 *
 * This file is distributed under the GPL, version 2 or at your
 * option any later version.  See doc/license.txt for details.
 */

#ifndef _CONFIG_H
#define _CONFIG_H

/*
 * File localconf.h will be included if reported present by the Makefile.
 * Use it to put your local configuration. File localconf.h will not be
 * imported into Git.
 */

#ifdef LOCALCONF
# include "../localconf.h"
#endif

/*
 * Determine if this EmuTOS is built for ROM or RAM
 */
#if defined(TARGET_PRG) || defined(TARGET_FLOPPY) || defined(TARGET_AMIGA_FLOPPY) || defined(TARGET_LISA_FLOPPY)
#  define EMUTOS_LIVES_IN_RAM 1
# else
#  define EMUTOS_LIVES_IN_RAM 0
#endif

/*
 * Determine if we use static Alt-RAM
 */
#ifdef STATIC_ALT_RAM_ADDRESS
# ifdef CONF_WITH_STATIC_ALT_RAM
#  error CONF_WITH_STATIC_ALT_RAM must not be manually set. Define STATIC_ALT_RAM_ADDRESS instead.
# endif
# define CONF_WITH_STATIC_ALT_RAM 1
#endif



/****************************************************
 *  T A R G E T   D E F A U L T S   S E C T I O N   *
 ****************************************************/

/*
 * Defaults for the ARAnyM target
 */
#ifdef MACHINE_ARANYM
# ifndef CONF_WITH_VDI_16BIT
#  define CONF_WITH_VDI_16BIT 1
# endif
# ifndef CONF_WITH_APOLLO_68080
#  define CONF_WITH_APOLLO_68080 0
# endif
# ifndef CONF_WITH_IKBD_CLOCK
#  define CONF_WITH_IKBD_CLOCK 0
# endif
# ifndef CONF_WITH_CARTRIDGE
#  define CONF_WITH_CARTRIDGE 0
# endif
# ifndef CONF_WITH_ACSI
#  define CONF_WITH_ACSI 0
# endif
# ifndef CONF_WITH_SCSI
#  define CONF_WITH_SCSI 0
# endif
# ifndef CONF_WITH_TT_MFP
#  define CONF_WITH_TT_MFP 0
# endif
# ifndef CONF_WITH_STE_SHIFTER
#  define CONF_WITH_STE_SHIFTER 0
# endif
# ifndef CONF_WITH_TT_SHIFTER
#  define CONF_WITH_TT_SHIFTER 0
# endif
# ifndef CONF_WITH_SCC
#  define CONF_WITH_SCC 1
# endif
# ifndef CONF_WITH_MEGARTC
#  define CONF_WITH_MEGARTC 0
# endif
# ifndef CONF_WITH_VME
#  define CONF_WITH_VME 0
# endif
# ifndef CONF_WITH_SFP004
#  define CONF_WITH_SFP004 0
# endif
# ifndef CONF_WITH_68030_PMMU
#  define CONF_WITH_68030_PMMU 0
# endif
# ifndef CONF_WITH_68040_PMMU
#  define CONF_WITH_68040_PMMU 1
# endif
# ifndef CONF_WITH_MONSTER
#  define CONF_WITH_MONSTER 0
# endif
# ifndef CONF_WITH_MAGNUM
#  define CONF_WITH_MAGNUM 0
# endif
# ifndef CONF_WITH_NOVA
#  define CONF_WITH_NOVA 0
# endif
# ifndef CONF_WITH_FORMAT
#  define CONF_WITH_FORMAT 0
# endif
# ifndef CONF_WITH_EASTER_EGG
#  define CONF_WITH_EASTER_EGG 0 /* ARAnyM's YM2149 can't produce sound */
# endif
#endif

/*
 * Defaults for the FireBee target
 */
#ifdef MACHINE_FIREBEE
# ifndef CONF_WITH_ST_MMU
#  define CONF_WITH_ST_MMU 0
# endif
# ifndef CONF_WITH_TT_MMU
#  define CONF_WITH_TT_MMU 0
# endif
# ifndef CONF_WITH_TT_MFP
#  define CONF_WITH_TT_MFP 0
# endif
# ifndef CONF_WITH_STE_SHIFTER
#  define CONF_WITH_STE_SHIFTER 0
# endif
# ifndef CONF_WITH_TT_SHIFTER
#  define CONF_WITH_TT_SHIFTER 0
# endif
# ifndef CONF_WITH_DSP
#  define CONF_WITH_DSP 0
# endif
# ifndef CONF_WITH_SCC
#  define CONF_WITH_SCC 0
# endif
# ifndef CONF_WITH_MEGARTC
#  define CONF_WITH_MEGARTC 0
# endif
# ifndef CONF_WITH_BLITTER
#  define CONF_WITH_BLITTER 0
# endif
# ifndef CONF_WITH_CACHE_CONTROL
#  define CONF_WITH_CACHE_CONTROL 0
# endif
# ifndef CONF_WITH_SFP004
#  define CONF_WITH_SFP004 0
# endif
# ifndef CONF_WITH_68030_PMMU
#  define CONF_WITH_68030_PMMU 0
# endif
# ifndef CONF_WITH_68040_PMMU
#  define CONF_WITH_68040_PMMU 0
# endif
# ifndef CONF_WITH_SDMMC
#  define CONF_WITH_SDMMC 1
# endif
# ifndef CONF_DETECT_FIRST_BOOT_WITHOUT_MEMCONF
#  define CONF_DETECT_FIRST_BOOT_WITHOUT_MEMCONF 1
# endif
# ifndef INITINFO_DURATION
#  define INITINFO_DURATION 8 /* Longer time for LCD monitors startup */
# endif
# ifndef AES_STACK_SIZE
#  define AES_STACK_SIZE 2048   /* in LONGs */
# endif
# ifndef CONF_WITH_ACSI
#  define CONF_WITH_ACSI 0      /* broken in current FireBee hardware */
# endif
# ifndef CONF_WITH_SCSI
#  define CONF_WITH_SCSI 0
# endif
# ifndef CONF_WITH_ICDRTC
#  define CONF_WITH_ICDRTC 0    /* useless on FireBee as it has NVRAM clock */
# endif
# ifndef CONF_WITH_ULTRASATAN_CLOCK
#  define CONF_WITH_ULTRASATAN_CLOCK 0    /* useless on FireBee as it has NVRAM clock */
# endif
# ifndef CONF_WITH_MONSTER
#  define CONF_WITH_MONSTER 0
# endif
# ifndef CONF_WITH_MAGNUM
#  define CONF_WITH_MAGNUM 0
# endif
# ifndef CONF_WITH_NOVA
#  define CONF_WITH_NOVA 0
# endif
# ifndef CONF_WITH_FORMAT
#  define CONF_WITH_FORMAT 0
# endif
#endif
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

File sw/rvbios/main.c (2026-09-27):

/*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
 * You should have received a copy of the GNU General Public License
 * along with this program  if not, write to the Free Software
 * Foundation, Inc., 675 Mass Ave, Cambridge, MA 02139, USA.
 *-----------------------------------------------------------------------------*/
#include <tos.h>
#include <linea.h>
#include <stdlib.h>
#include <stdio.h>
#include <stddef.h>
#include <stdint.h>
#include <stdbool.h>
#include <string.h>
#include <mint/cookie.h>
#include <mint/osbind.h>
#include <mint/sysvars.h>
#include "raven.h"
#include "rvbios.h"
#include "vga.h"
#include "setup/setup.h"
#include "setup/form_vt.h"


/*----------------------------------------
	Constants
----------------------------------------*/
#define C__MCH_RAVEN        0x00070000UL

#define COL_FG_TOS		    COL_BLACK
#define COL_BG_TOS		    COL_WHITE

#define BOOTSCREEN_HELP     1
#define BOOTSCREEN_NAME     1

#define FONTSIZE_8x8        1
#define FONTSIZE_8x16       2

#define SETUP_ONLY          0



/*----------------------------------------
	Globals
----------------------------------------*/

/*----------------------------------------
	Create or change cookie
----------------------------------------*/
void Setcookie(uint32_t c, uint32_t d)
{
	int32_t cookies_size = 0;
	int32_t cookies_used = 0;
	int32_t cookies_avail = 0;
	uint32_t* jar = (uint32_t*) *((uint32_t*)0x5A0);
	uint32_t* ptr = jar;
	
	/* replace value or find number of free slots */
	while (1){
		cookies_used++;
		if (ptr[0] == c){
			ptr[1] = d;
			return;
		}
		else if (ptr[0] == 0){
			cookies_size = ptr[1];
			break;
		}
		ptr+=2;
	}

	/* grow jar when necessary */
	cookies_avail = cookies_size - cookies_used;
	if (cookies_avail <= 0) {
		int32_t oldsize = (2*4*(cookies_size + 0));
		int32_t newsize = (2*4*(cookies_size + 8));
		uint32_t* newjar = (uint32_t*)Malloc(newsize);
		memcpy(newjar, jar, oldsize);
		*((uint32_t*)0x5A0) = (uint32_t)newjar;
		jar = newjar;
		cookies_size = cookies_size + 8;
	}
	
	/* install cookie */
	jar[(cookies_used<<1)-2] = c;
	jar[(cookies_used<<1)-1] = d;
	jar[(cookies_used<<1)+0] = 0;
	jar[(cookies_used<<1)+1] = cookies_size;
}


/*----------------------------------------
	Locale
----------------------------------------*/

void InstallCookies(void)
{
#if XBNVM
	uint8_t r[4];
	if (NVMaccess(0, 6, 4, r) == 0)
	{
		uint32_t cookie;
		uint16_t country  = (uint16_t)r[0];
		uint16_t keyboard = (uint16_t)r[1];
		uint16_t idt0     = (uint16_t)r[2];
		uint16_t idt1	  = (uint16_t)r[3];

		if (Getcookie(C__AKP,(long*)&cookie) != C_FOUND) {
			Setcookie(C__AKP, (country << 8) | keyboard);
		}

		if (Getcookie(C__IDT,(long*)&cookie) != C_FOUND) {
			Setcookie(C__IDT, (idt0 << 8) | idt1);
		}	
	}
#endif
	
	Setcookie(C_RAVN, (uint32_t)raven());
#if defined(C__MCH_RAVEN)
	Setcookie(C__MCH, C__MCH_RAVEN);
#endif    
}

/*----------------------------------------
	Boot info
----------------------------------------*/
#include "logo.c"

void bootscreen_off(void)
{
	uint32_t i;
	uint32_t* vram = (uint32_t*)Physbase();
    vga_WriteReg(0x3c4, 0x02, 0x0e);
    for (i = 0; i < ((64UL * 1024) / 4); i++) {
        *vram++ = 0;
    }
	vga_WriteReg(0x3c4, 0x02, 0x02);
}

void bootscreen(void)
{
	int p,i,j,k;
    uint16_t* logoHdr = (uint16_t*)logo_bin;
    uint32_t logo_w = (uint32_t)logoHdr[3];
    uint32_t logo_h = (uint32_t)logoHdr[4];
    int16_t logo_p  = logoHdr[5];
	uint8_t* logo = (uint8_t*)(&logo_bin[64]);

    const uint32_t logo_x = (logo_w < (640 >> 3)) ? ((320 - (logo_w << 2)) >> 3) : 0;
    const uint32_t logo_y = (logo_h < 480) ? (240 - (logo_h >> 1)) : 0;

    uint32_t vram_w = (uint32_t)Vdiesc->bytes_lin;

    /* todo: get background color from logo header data */
    if ((logo[1] & (1<<7)) == 0) {
        vt_setFgColor(COL_BLACK);
    	vt_setBgColor(COL_WHITE);
    } else {
        vt_setFgColor(COL_WHITE);
    	vt_setBgColor(COL_BLACK);
    }

    Cconws(C_OFF);
	Cconws(CLEAR_HOME "\r\n");
    vt_setCursorPos(0, 7);

    for (p=0; p<logo_p; p++) {
        uint8_t* vram = (uint8_t*)Physbase();
        vram += (logo_x + (logo_y * vram_w));
		vga_WriteReg(0x3c4, 0x02, (1 << (p+1)));
        for (i=0; i<logo_h-1; i++) {
            for (j=0; j<logo_w; ) {
                uint8_t ctrl = *logo++;
                uint8_t runl = ctrl & 0x7f;
                j += runl;
                if (ctrl & 0x80) {
                    uint8_t data = *logo++;
                    for (k=0; k<runl; k++) {
                        *vram++ = data;
                    }
                } else {
                    for (k=0; k<runl; k++) {
                        *vram++ = *logo++;
                    }
                }
            }
            vram += (vram_w - logo_w);
        }
		logo = (uint8_t*)(&logo_bin[64]) + logoHdr[8+p];
    }
	vga_WriteReg(0x3c4, 0x02, 0x02);
}

extern LINEA *Linea;
extern VDIESC *Vdiesc;
extern FONTS *Fonts;

typedef struct
{
    bool changed;
    FONT_HDR* font;
    short v_cel_ht;
    short v_cel_wr;
    short v_cel_mx;
    short v_cel_my;
    short v_fnt_wd;
    short v_fnt_st;
    short v_fnt_nd;
    void* v_fnt_ad;
    short* v_off_ad;
} fnt_data_t;

static fnt_data_t fnt_data_old;

void font_get(fnt_data_t* fnt_data) {
    fnt_data->v_cel_ht = Vdiesc->v_cel_ht;
    fnt_data->v_cel_wr = Vdiesc->v_cel_wr;
    fnt_data->v_cel_mx = Vdiesc->v_cel_mx;
    fnt_data->v_cel_my = Vdiesc->v_cel_my;
    fnt_data->v_fnt_wd = Vdiesc->v_fnt_wd;
    fnt_data->v_fnt_st = Vdiesc->v_fnt_st;
    fnt_data->v_fnt_nd = Vdiesc->v_fnt_nd;
    fnt_data->v_fnt_ad = Vdiesc->v_fnt_ad;
    fnt_data->v_off_ad = Vdiesc->v_off_ad;
}

void font_set(fnt_data_t* fnt_data) {
    Vdiesc->v_cel_ht = fnt_data->v_cel_ht;
    Vdiesc->v_cel_wr = fnt_data->v_cel_wr;
    Vdiesc->v_cel_mx = fnt_data->v_cel_mx;
    Vdiesc->v_cel_my = fnt_data->v_cel_my;
    Vdiesc->v_fnt_wd = fnt_data->v_fnt_wd;
    Vdiesc->v_fnt_st = fnt_data->v_fnt_st;
    Vdiesc->v_fnt_nd = fnt_data->v_fnt_nd;
    Vdiesc->v_fnt_ad = fnt_data->v_fnt_ad;
    Vdiesc->v_off_ad = fnt_data->v_off_ad;
}

void font_setsize(uint16_t idx) {
    FONT_HDR* font = Fonts->font[idx];
    Vdiesc->v_cel_ht = font->frm_hgt;
    Vdiesc->v_cel_wr = Linea->v_lin_wr * font->frm_hgt;
    Vdiesc->v_cel_mx = (Vdiesc->v_rez_hz / font->wcel_wdt) - 1;
    Vdiesc->v_cel_my = (Vdiesc->v_rez_vt / font->frm_hgt) - 1;
    Vdiesc->v_fnt_wd = font->frm_wdt;
    Vdiesc->v_fnt_st = font->ade_lo;
    Vdiesc->v_fnt_nd = font->ade_hi;
    Vdiesc->v_fnt_ad = font->fnt_dta;
    Vdiesc->v_off_ad = font->ch_ofst;
}
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

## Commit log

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2024-05-27 isa - template
    [isa16.kicad_pcb, isa16.kicad_sch]
2024-05-27 simm stuff
    [panel_4layer.kicad_pcb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]
2024-05-27 renamed folder for rom16m55/70
    [simm72_rom_16M55-B_Cu.gbl, simm72_rom_16M55-B_Mask.gbs, simm72_rom_16M55-B_Paste.gbp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]
2024-05-27 update isa16 template
    [isa16.kicad_pcb, isa16.kicad_sch]
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2024-06-06 simm folder cleanup and license
    [programmer.kicad_pcb, programmer.kicad_sch, simm72.kicad_pcb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]
2024-06-06 isa folder cleanup
    [isa16.kicad_pcb, isa16.kicad_sch]
2024-06-06 A0 sources
    [isa.kicad_sch, local16.kicad_sch, local32.kicad_sch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]
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2024-06-07 fixed bom error
    [misc.kicad_sch]
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2024-06-29 Bootrom fixes
    Fixed bad BSS address
    Disabled flow control
    Additional debug output
2024-06-29 i2c fix for revA1
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2024-06-30 setup for rev.A2 wip
    [isa.kicad_sch, local16.kicad_sch, local32.kicad_sch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]
2024-06-30 Changed ROM Simm naming convention
    [simm72_rom_1M55-B_Cu.gbl, simm72_rom_1M55-B_Mask.gbs, simm72_rom_1M55-B_Paste.gbp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]
2024-06-30 Update PLCC rom preview image
    [simm72_rom_2M55.kicad_pcb]
2024-06-30 re-export plcc rom gerbers with corrected silkscreen
    [simm72_rom_2M55-B_Cu.gbl, simm72_rom_2M55-B_Mask.gbs, simm72_rom_2M55-B_Paste.gbp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]
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2024-07-06 Squashed 'sw/isa/drivers/picogus/' content from commit 91d421af
    git-subtree-dir: sw/isa/drivers/picogus
    git-subtree-split: 91d421af3f1f90727cb92a818d3008c63f348286
    [BOM (DAC module).csv, BOM (integrated DAC).csv, BOM-ISA adapter.csv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]
2024-07-09 Squashed 'sw/isa/drivers/picogus/' changes from 91d421af..f066d4fb
    f066d4fb Remove release script - it's currently all done in CMake and GH Actions
    5cd03cbd Changelog for v2.0.0
    6a7c1eb5 Fix bool option setting and add xinput driver install callback
    afd68487 pgusinit: Update com port and SB blaster parsing
    ab2b0e2b Mouse working in CMS/Tandy/AdLib modes
    6fde955e Working mouse emu in USB mode
    5f5583d7 Pin GH workflow to ubuntu-22.04 just in case
    24621a8e Fix saving current boot mode; cleanup
    19fae392 Fixes for pgusinit
    193ab734 Fix multifw build for adlib
    fb46bb36 Dynamic PIC timers
    8b0c34e3 Combine USB joy/mouse into common handler
    7a0b3c49 Update submodules
    e216fdc0 Big overhaul of pgusinit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
    [audio.kicad_sch]
2024-07-13 ROM update
    Build EmuTOS rom by default, build monitor only with "make mon"
    Started to add hardware test command to monitor
    Fixed cache settings for st/tt regions
    Changes st-ram size to 1MB
    Reduced reserved ram to 3MB
    Enable storebuffer
    Misc cleanup
    [config.h]
2024-07-30 NE2000 network driver.
    Unmodified Ethernec driver. Hades version is compatible (ENEH)
    [TCC.CFG]
2024-08-09 nessi : wip version
    ISA: slowed I/O access to accommodate PicoGUS
    ISA: fixed 16bit access to 8bit devices
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2024-08-09 Rev.A2 some minor fixes
    [local32.kicad_sch, misc.kicad_sch, power.kicad_sch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]
2024-08-16 A1 : IO shield template, wip
    [ioshield.kicad_pcb]
2024-08-17 A2 : minor changes to aid in building
    Silkscreen improvements
    Larger diode footprints
    [local16.kicad_sch, power.kicad_sch]
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2024-08-20 Fixed 48MB issue
    Firmware and Rom updated, moving things away from the lower regions of TT-RAM.
    Changed SIMM3 address to $40000000
    Changed STEMU address to $41000000
    [config.h]
2024-08-24 silence S-record errors for non-S-record input lines when not programming
    [main.c]
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2024-09-22 programmer: accelerate flash programming using readback
    Rather than wait for the maximum possible program time, stop waiting when the correct
    value can be read back. This is a conservative version of the "Data# polling" algorithm.
    [flash.c, main.c]
2024-09-22 Build mon with m68k-atari-mintelf toolchain
    apply const until .data is empty
    remove RAM trampoline code
    copy .data segment to RAM at startup.
    simplify ROM makefile and fix mon build dependency
    merge substance of #6
    [config.h, flash.c]
2024-10-05 emutos : don't enable ikbd interrupts before acia init
    Prevent EmuTOS crash if using ikbd before acia vectors has been initialized.
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2024-11-15 a2 : added some todo notes
    [isa.kicad_sch, local16.kicad_sch, local32.kicad_sch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]
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2024-12-02 fpemu: fixed memory trashing if new vbr was created
    [main.c]
2024-12-02 fixed bug if no cookie jar existed
    [main.c]
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2024-12-16 Squashed 'sw/isa/drivers/picogus/' changes from f066d4fb..348d86da
    348d86da Firmware v2.2.0
    c01a4c06 Temporarily use develop branch of Pico SDK to bring in timer fix
    ad969987 Cleanup
    a3df9cd0 Clean up MPU-401, increase midi buffer size in non-MPU modes
    fe8e9680 Drop flash_safe_execute_core_init as it interferes with cyw43
    ca91483f Remove debug printf
    8152361c Fix build
    0836bc62 Periodically try reconnecting
    0984cad9 Move to non-poll for wifi
    9bfeb41c WIP
    11d26f19 Update to SDK 2.1.0
    b23cb703 Add missing pico_pic to ne2k
    3bb39377 License housekeeping
    d84e4437 Refactor events for less jitter
    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
2024-12-22 removed unused crosstos utilities
    [LASER.CFG, LDB.CFG, TC.CFG]
2024-12-22 crosstos : fixed path resolving issue
    would fail if a file or path with longer name started with the string that was looked for.
    [main.c]
2024-12-22 crosstos : misc fixes
    fixed path resolve bug.
    increased max number of file handles
    support commandlines larger than 126 characters
    [main.c]
2024-12-22 purec and tools reorg
    [PCC.CFG, PD.CFG]
2024-12-25 rvnova cleanup and fix
    fixed memory overwrite, warnings, and new makefile
    [main.c]
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2025-01-08 EmuTOS (Raven specific): Increased stack size for AES
    To be more compatible with programs which are using CFLib but does not have stacksize workarounds for plain TOS.
    (More specifically, I want to use a recent QED in EmuTOS instead of keeping an old version around for when not running MiNT)
    [config.h]
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2025-02-08 emutos: hi-speed serial now available as bios device 7
    todo:
    - cts/rts is not working, could be a hardware issue
    - bios buffer and interrupt is not yet implemented, it currently relies on the 64byte hardware fifo and polling
    [config.h]
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2025-02-26 Fix prototype of panic()
2025-02-26 FIx fsincose tests calling wrong driver function
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2025-03-08 Raven.A2 : routing cleanup + gpio
    pwr switch status -> uart gpi
    uart gpo -> header
    [local32.kicad_sch, power.kicad_sch]
2025-03-08 Raven.A2: pullups on MC68150 databus
    [power.kicad_sch, raven.kicad_sch]
2025-03-09 some restructuring of simm folders
    Size shouldn't be in the folder and filenames since it depends on what chips one populates.
    Added SMD rev.A1 with fixes to make it compatible with BYTE/WORD selectable nor flash (pin47 tied to VCC for WORD mode)
    [simm72_rom_2M55.kicad_pcb, simm72_rom_2M55.kicad_sch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]
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2025-03-09 rev.A2 updates
    Added i2c DAC for reading cpu core temperature
    [local16.kicad_sch, local32.kicad_sch, misc.kicad_sch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]
2025-05-16 bom corrected (description fix)
2025-05-16 corrected resistor value description, resaved with KiCad 9
    [programmer.kicad_pcb, programmer.kicad_sch]
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2025-05-26 Added ckbd upgrade module for Raven.A1
    [ckbd.kicad_pcb, ckbd.kicad_sch]
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2025-05-29 mon upload fix
    do not try to flash non-rom images. luckily it was caught by verify and printed error message instead.
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2025-06-01 update SMD-ROM rev.A1 with gerbers
    Has not been built nor tested.
    Should be compatible with existing rom chips, and can in theory support additional models with byte/word select input (assuming software for flashing is updated to support the model if required)
    [simm72_rom_smd-B_Cu.gbl, simm72_rom_smd-B_Mask.gbs, simm72_rom_smd-B_Paste.gbp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]
2025-06-02 fixed usb mouse wheel direction
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2025-06-19 joyport fix for a1 pcb
2025-06-20 nessi: reversed order of the ram slots
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2025-06-26 corrected GPL version in source comment
    [main.c]
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2025-06-29 68150:BUSCS signal separate from 68150:CS
    [raven.kicad_sch]
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2025-07-05 replaced DS1818 TH part with SMD version
    It's easy to get the orientation wrong on the TH part, there is no question about it when using the SMD part.
    [power.kicad_sch]
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2025-07-27 bom correction
2025-07-27 updated smd rom simm
    removed old version in favour of new one.
    supports flash devices with byte/word selection on pin47
    [simm72_rom_smd-B_Cu.gbl, simm72_rom_smd-B_Mask.gbs, simm72_rom_smd-B_Paste.gbp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]
2025-08-02 rom layout refactor
    commit 2375798ec444a1d7bb6cf3793f102078f9837c7c
    Author: agranlund <granlund23@yahoo.se>
    Date: Sat Aug 2 02:05:27 2025 +0200
    rom layout refactoring
    - Individual rom sections and toc, less unnecessary padding between boot/tos/romdisk etc.
    commit 269c4584b95ecdf640444f638d0d2041a0ec764c
    Author: agranlund <granlund23@yahoo.se>
    Date: Sat Aug 2 01:55:32 2025 +0200
    rom: uart helper functions
    commit 23e26c139cdb68b30c0ce3aa620887cf8dc00329
    Author: agranlund <granlund23@yahoo.se>
    Date: Thu Jul 31 17:24:49 2025 +0200
    simm programmer now understands config space
    - avoid config area when reprogramming rom
    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
    [flash.c, main.c]
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2025-08-09 slight refactor, fixed runtime mode switch
    in preparation for card specific svga
    [emulator.h, main.c]
2025-08-16 rvnova
    - added Cirrus, OAK and WDC wip svga drivers
    - added auto-bankswitch support for cards that don't have linear support
    - replaced sta_vdi with ET4000T8 version for 16 and 32bpp support
    [emulator.h, main.c]
2025-08-16 updated emutos
    commit ac0905db494e31bb2780fabebbf2b0cf6f219503
    Merge: 97e6c418b 96eba3970
    Date: Sat Aug 16 21:05:36 2025 +0200
    Merge commit '96eba397064e841ab5e44faf3734685c2ce2ae81' into emutos
    commit 96eba397064e841ab5e44faf3734685c2ce2ae81
    Date: Sat Aug 16 21:01:08 2025 +0200
    Squashed 'sw/rom/emutos/' changes from fd546a134..838656355
    838656355 Rework Crazydots graphics card detection
    49ec92334 Falcon: Increase VRAM allocation at boot if necessary
    401c35611 Make calc_vram_size static
    e37c82c8c Implement strcat() with inline assembly
    3d868195d Implement strcpy() with inline a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
    [config.h]
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2025-08-27 ISA:MEMCS16 for 8bit support
    [isa.kicad_sch, raven.kicad_sch]
2025-08-27 Temporary fix for SDL and Nova
    removed 320x200x16bpp resolution from default driver bib.
    SDL appears to pick it when requesting the 8bpp variant.
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2025-10-07 remove vgabios workarounds
    no longer needed.
    they were there in case rvnova was ran in a cache-disabled state from the auto folder.
2025-10-08 crash fix
    code path was likely never taken but this prevents crashing if calling vga_clear() with no driver initialised.
2025-10-25 A2: support 32MB simms
    [isa.kicad_sch, local32.kicad_sch]
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2025-11-08 rvbios: rtc driver fix
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2025-11-11 disable store/load bypass on rev1+5 cpus
    workaround as suggested by motorola errata I14
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2025-11-11 fix crash on startup
    [main.c]
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2025-12-06 soundblaster: ess, wss, opl3sa
    pnp and non-pnp detect.
    opl3sa mixer to circumvent sb compatibility bug
    [main.c]
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2025-12-10 added todo for ISA-IRQ fix
    [isa.kicad_sch]
2025-12-10 ISA irq support (disabled)
    Disabled for now because Raven.A1 has a hardware bug that prevents isa interrupts from being detected.
2025-12-12 Remove ISA interrupts issue from README
    Removed note about ISA interrupts not working and IRQ lines.
    Turns out they are.
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2025-12-23 Squashed 'sw/rom/emutos/' changes from fd546a134..8fc0919c9
    8fc0919c9 Nova: Use BOOL type internally where appropriate
    eb8c73165 Nova: Remove dead code
    feb5145ea Mach: Refactor register initialization
    28639d30a Mach64: Refactor DAC access
    f29e23940 Nova: Update comments
    29c9e38ae Mach64: Add support for CH8398 DAC
    cf7b4432b Add support for ATI Mach64 graphics card in Nova adapter
    185679eee Fix header guard name
    64eb50e5e IDE: Add explanatory comment
    581b1faab Support GUID partition table (GPT)
    92d890c59 SCSIDRV: Report correct maximum transfer size for Falcon SCSI
    36bacb9c6 Update source code comments
    e452070ac Clarify GEMDOS trap code
    30a91f6ff Refactor GEMDOS trap code
    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
    [config.h]
2025-12-25 purec stacksize fix
    Remove _StkSize variable as it was completely wrong.
    It is being set by the linker as not supposed to be a variable like that.
    [main.c]
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2026-01-18 minor fixes
    - replace IDE header footprint and part
    - fix floating (unused) inputs on U102
    - removed ckbd debug pads
    [local16.kicad_sch, local32.kicad_sch, raven.kicad_sch]
2026-01-18 Revise README with BOM updates and fixes
    Updated README with recent BOM changes and fixes.
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2026-01-20 rvnd: mpu401 minor fix
    [main.c]
2026-01-30 Add files via upload
    IO Shield 3D STL created from KiCAD PCB. Tested and fits standard ATX case.
    [raven_ioshield_new.stl]
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2026-02-01 fdc improvements
    some error handling
    xbios read/verify functions
    [fdc.c, main.c]
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2026-02-06 floppy wip
    slight refactor on read/write/format.
    (write disabled by default as it's still not working correctly)
    [fdc.c, main.c]
2026-02-07 replace printf with cconws
    [main.c]
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2026-02-07 font change + clear screen no longer needed
    [main.c]
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2026-02-16 Add Blender 3D IO Shield file
    add Blender 3D file used to create IO Shield STL
    [Raven060 IO Shield.blend]
2026-02-16 tseng fixes
    - correctly place W32i LFB address
    - detect clocks for custom resolutions
    - 1280x720 works and tested on AX and W32i
    [emulator.h]
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2026-03-04 S3 driver, small fixes
2026-03-08 uip: fixed stringop warnings
    [main.c]
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2026-03-08 rvnova: graceful exit if required files cannot be found
    instead of crashing if selected driver files cannot be loaded, or other required files.
    [main.c]
2026-03-08 fixed bib generator pitch bug
2026-03-30 install 060sp in TOS vectors
    installed by bootrom in hidden vbr proxy by default.
    this moves it to TOS vectors at $0
    required for some programs to correctly identify 040 vs 060 (eg. Mint 1.16.0)
    [main.c]
2026-03-31 fix crash on unassigned interrupt vectors
2026-03-31 Squashed 'sw/rom/emutos/' changes from 65a71f38e3..67e4a4cd1b
    67e4a4cd1b Speed up hard disk check again
    cebdff8972 Hatari test: Allow more time to reach Desktop
    e095c950ab Fix 'dmaboot' for ColdFire architecture
    32ddba4141 Update copyright years
    d5bc81e9c3 Remove obsolete disabled code
    590636a4f1 Run cartridge applications before harddisk boot
    327adfba4f Fix ACSI2STM GEMDRIVE booting
    0817d25da0 Ignore 'EFI hidden' GPT partitions
    6245942cda Accept disks that only return a root sector
    dd32dad5e2 Support for booting 3rd party hard disk driver
    93e1098722 TT RAM sizing: Stop when mirrored memory region is detected
    04bac280c6 Remove unused defines
    git-subtree-dir: sw/rom/emutos
    git-subtree-split: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
    [config.h]
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2026-04-08 fix nova setup when no drivers are present
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2026-04-10 increase i2c delay
    shot in the dark trying to hunt down intermittent nvram read-failure.
2026-04-11 wip pram + flash fixes
    [flash.c]
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2026-04-22 A2 rework
    - reworking top-left area for dsp56303
    - internal speaker header for YM
    - software controlled volume for YM
    - misc routing cleanup
    [isa.kicad_sch, local16.kicad_sch, local32.kicad_sch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]
2026-04-23 A2. YM:IOA7 used for detecting volume+spkr controls
    [local16.kicad_sch]
2026-04-24 A2: DSP ram routing
    [local16.kicad_sch, local32.kicad_sch, misc.kicad_sch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]
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2026-04-27 A2: DAC for DSP and mix with YM
    [local32.kicad_sch, misc.kicad_sch]
2026-04-29 A2: simplified DSP RAM connection
    AA0 -> SRAM_CE
    AA1 -> SRAM_A16
    OMR register must be set to priority encoding disabled.
    [local32.kicad_sch]
2026-04-29 A2: fixed comment about DSP ram memory map
    [local32.kicad_sch]
2026-05-02 Document errors to consider when building
    Added error notes regarding capacitor orientation and silkscreen labeling for J305.
2026-05-02 A2: dac + adc + dsp work
    [local16.kicad_sch, local32.kicad_sch, misc.kicad_sch]
2026-05-03 A2 wip
    audio hooked up
    added caps for fan headers
    [local16.kicad_sch, local32.kicad_sch, power.kicad_sch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]
2026-05-03 A2: changed oscillator caps
    also fixed reference identifier
    [local32.kicad_sch, power.kicad_sch]
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2026-05-23 A2: routed few misc signals
    temp1, temp2, argb, pwm, pwrsw
    remove uart irq from mfp1, was unused in A1 anyway.
    (uart irq was always at avec5)
    [local16.kicad_sch]
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2026-05-24 A2: schema + routing complete. ERC + DRC complete.
    Let sit for a while, revisit and sanity check with fresh eyes before gerber.
    Todo: double check BOM export and fix missing infos if any.
    [isa.kicad_sch, local16.kicad_sch, local32.kicad_sch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]
2026-05-28 A2: cosmetics and bom preparations
    [isa.kicad_sch, local16.kicad_sch, local32.kicad_sch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]
2026-05-28 Update README with BOM and fix details
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2026-05-30 A2: gerber settings and misc
    [local32.kicad_sch]
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2026-05-31 removed unused components fields
    [isa.kicad_sch, local16.kicad_sch, local32.kicad_sch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]
2026-05-31 A2: dsp jtag
    resistor on TCK instead of hardwired.
    makes it possible, but uncomfortable, to jtag by placing needles directly on chip.
    [local32.kicad_sch, raven-a2_bom.csv]
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2026-06-21 replaced a couple of caps
    [local32.kicad_sch, raven-a2_bom.csv, raven.kicad_sch]
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2026-06-27 removed PWR_SW to UART:RI connection
    [local32.kicad_sch]
2026-06-28 moved a1 upgrade hw into a1 folder
    [ckbd-B_Cu.gbl, ckbd-B_Mask.gbs, ckbd-B_Paste.gbp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]
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2026-06-28 uart1:ria to gnd, same as A1
    [local32.kicad_sch]
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2026-07-04 removed unused part
    Already excluded from board and bom.
    No need to keep the excluded part in schematic.
    [local32.kicad_sch]
2026-07-14 RevA2b
    - Fixed bad ADC input from YM (two caps added)
    [isa.kicad_sch, local16.kicad_sch, local32.kicad_sch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]
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2026-07-30 asm56: option to write empty sections.
    Added -u option for writing empty sections. By default this version now skips them.
    Ie; avoid writing sections that only contain DS and DSM.
    The write-zero is in itself a useful option in case you actually do have a section with DC's that you actually explicitly wanted inited to zero. (this option should probably go away or at least be made default)
    Also bumped version number, and made default program without arguments output the usage help.
    [main.c]
2026-08-02 fixed dsp interrupt dispatcher bug
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2026-10-07 rvnova: no longer relies on xmenu.prg
    functionality is now built into the loader.
    [main.c]
2026-10-10 Squashed commit of the following:
    commit c691e1190a0c1727c01236eb2d6c331850976714
    Date: Sat Oct 10 12:34:04 2026 +0200
    Update motorola_sp.S
    commit f3b160e1bac71a0971e67ef68431edf36704d6f8
    Date: Thu Oct 8 23:45:56 2026 +0200
    bugfixes
    latest fixed fpsp
    simplified boilerplate like ct60tos
    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
2026-10-11 rom/rvbios: motorola 060sp fixes
    bootrom installs the entire package to proxy as before.
    rvbios move only the unimplemented integer instruction to TOS vectors, leaving all others hidden in the proxy.
    unimpl instruciton is commonly used by TOS programs to detect cpu type so should be in TOS vectors and overridable.
    fpu vectors are kept hidden in the proxy to avoid something overriding them.
    for example, mint replaces them all otherwise.
    ct60tos combats Mints behavior by checking and force-reinstalling its vectors every vbl but we can just keep ours hidden in the proxy for same effect.
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2026-10-14 pcmake now corrects errors in pcc's line number reports
    pcc reports wrong line number for errors and warnings if a source file has multi-line block comments.
    this fixes that by taking the output message, fixing it, and printing the fixed one.
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2026-11-07 fixed bad geometry, exported new stl.
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

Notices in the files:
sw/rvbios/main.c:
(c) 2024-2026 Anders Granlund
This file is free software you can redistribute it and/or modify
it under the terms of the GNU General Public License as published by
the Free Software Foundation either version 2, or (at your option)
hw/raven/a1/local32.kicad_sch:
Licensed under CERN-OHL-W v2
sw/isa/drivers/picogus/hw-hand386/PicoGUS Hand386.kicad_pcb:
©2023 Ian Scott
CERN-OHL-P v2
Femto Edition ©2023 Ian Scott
